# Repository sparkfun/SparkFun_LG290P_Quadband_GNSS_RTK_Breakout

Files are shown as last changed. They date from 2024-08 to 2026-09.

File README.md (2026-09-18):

SparkFun Quadband GNSS RTK Breakout - LG290P (Qwiic)
========================================

SparkFun Quadband GNSS RTK Breakout - LG290P (Qwiic) (https://www.sparkfun.com/sparkfun-quadband-gnss-rtk-breakout-lg290p-qwiic.html)

[*SparkFun Quadband GNSS RTK Breakout - LG290P (Qwiic) (GPS-26620)*](https://www.sparkfun.com/sparkfun-quadband-gnss-rtk-breakout-lg290p-qwiic.html)

The [SparkFun Quadband GNSS RTK Breakout - LG290P (Qwiic)](https://www.sparkfun.com/sparkfun-quadband-gnss-rtk-breakout-lg290p-qwiic.html) features the Quectel LG290P GNSS module. The board's dimensions, pin layout, and connectors are exactly the same as our very popular [SparkFun GPS-RTK-SMA Breakout - ZED-F9P (Qwiic)](https://www.sparkfun.com/sparkfun-gps-rtk-sma-breakout-zed-f9p-qwiic.html); and can be used as a drop-in replacement. The board also accommodates users with a diverse choice of interfaces including UART, SPI*, and I2C*.

The LG290P module is a quad-band, multi-constellation, high-precision, RTK GNSS receiver. The module is capable of simultaneously receiving signals from the `L1`, `L2`, `L5`, and `L6`/`E6` frequency bands of the GPS, GLONASS, Galileo, BDS, QZSS, and NavIC GNSS constellations. In addition, the module supports SBAS augmentation systems (WASS, EGNOS, BDSBAS, MSAS, GAGAN, and SDCM), PPP services* (BDS PPP-B2b, QZSS CLAS, MADOCA-PPP, and Galileo HAS), and RTK corrections for precision navigation with a fast convergence time and reliable performance.

The built-in NIC anti-jamming unit provides professional-grade interference signal detection and elimination algorithms, which effectively mitigate against multiple narrow-band interference sources and significantly improves the signal reception performance in complex electromagnetic environments. Additionally, the embedded algorithms ensure reliable positioning in complex scenarios such as urban environments and deep tree cover.

With its performance advantages of high-precision and low power consumption, this board is an ideal choice for high-precision navigation applications, such as intelligent robots, UAVs, precision agriculture, mining, surveying, and autonomous navigation.

> [!NOTE]
> `*`: Feature is still under development

> [!IMPORTANT]
> - Currently, only the UART interface is supported by the module. All three UART ports are broken out to the USB-C connector *(via CH342 USB-serial converter)*, 4-pin locking JST connector, and BlueSMiRF 6-pin header.
> - Additionally, the corrections for some of the PPP services may not be implemented yet.

Documentation
--------------

* **[Hookup Guide (mkdocs)](http://docs.sparkfun.com/SparkFun_LG290P_Quadband_GNSS_RTK_Breakout/)** - The hookup guide for the SparkFun Quadband GNSS RTK Breakout - LG290P (Qwiic) hosted by GitHub pages.<br>
   
* [SparkFun LG290P GNSS Arduino Library](https://github.com/sparkfun/SparkFun_LG290P_GNSS_Arduino_Library) - An Arduino library for the LG290P GNSS module

*Need to download or print our hookup guide?*

* [Print *(Print to PDF)* from Single-Page View](http://docs.sparkfun.com/SparkFun_LG290P_Quadband_GNSS_RTK_Breakout/print_view)

Repository Contents
-------------------

* **[/docs](/docs/)** - Online documentation files
    * [assets](/docs/assets/) - Assets files
        * [3d_model](/docs/assets/3d_model/) - Files for the 3D models
            * [3D CAD Model](/docs/assets/3d_model/cad_model.step) (.step)
        * [board_files](/docs/assets/board_files/) - Files for the product design
            * [KiCad Design Files](/docs/assets/board_files/kicad_files.zip) (.zip)
            * [Schematic](/docs/assets/board_files/schematic.pdf) (.pdf)
            * [Dimensions](/docs/assets/board_files/dimensions.pdf) (.pdf)
        * [component_documentation](/docs/assets/component_documentation/) - Datasheets for hardware components
        * [img/hookup_guide/](/docs/assets/img/hookup_guide/) - Images for hookup guide documentation
* **[/Hardware](/Hardware/)** - Hardware design files (.brd, .sch)
  * **[/Production](/Production/)** - Production files

Product Variants
----------------

- LG290P Variants
  - [GPS-26620](https://www.sparkfun.com/sparkfun-quadband-gnss-rtk-breakout-lg290p-qwiic.html) - v1.0, Initial Release
  - [GPS-26916](https://www.sparkfun.com/sparkfun-rtk-postcard.html) - SparkFun RTK Postcard *(w/ ESP32)*
- [GPS-28019](https://www.sparkfun.com/products/28019) - SparkFun Quadband GNSS RTK Breakout - LG580P (Qwiic)

Version History
---------------

* [v10](https://github.com/sparkfun/SparkFun_LG290P_Quadband_GNSS_RTK_Breakout/releases/tag/v10) - Initial Release

License Information
-------------------

This product is ***open source***!

Please review the [`LICENSE.md`](./LICENSE.md) file for license information.

If you have any questions or concerns about licensing, please contact technical support on our [SparkFun forums](https://community.sparkfun.com/).

Distributed as-is; no warranty is given.

- Your friends at SparkFun.

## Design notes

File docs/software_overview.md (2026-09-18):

---
icon: fontawesome/solid/computer
---

## CH342 USB Driver
The USB drivers for the CH342 USB-to-Serial converter can be downloaded from the [manufacturer's website](https://www.wch-ic.com/search?q=CH342&t=downloads).

<div class="grid cards" align="center" markdown>

-   :material-microsoft-windows: **Windows**

	---

	[:octicons-download-16:{ .heart } Download Page for `CH343SER.EXE`](https://www.wch-ic.com/downloads/CH343SER_EXE.html){ .md-button .md-button--primary target="blank" }

-   :material-apple: **MacOS**

	---

	[:octicons-download-16:{ .heart } Download Page for `CH341SER_MAC.ZIP`](https://www.wch-ic.com/downloads/CH34XSER_MAC_ZIP.html){ .md-button .md-button--primary target="blank" }

</div>

!!! info "Linux"
	A USB driver is not required for Linux based operating systems.

## GNSS Software
!!! tip
	While it is not required, we highly recommend that users configure their LG290P GNSS module with the [QGNSS software provided by Quectel](#qgnss-software). This is due to the unique data structure of the UART command messages, utilized to configure the LG290P module.

	??? warning "Windows Only"
		Currently, the QGNSS software is only available for Windows operating systems.

	??? success "Windows, MacOS, or Linux"
		For users with computers that run on MacOS or Linux, we have found alternative software option for viewing the data from the NMEA messages. However, this GUI interface is currently limited to only receiving UART messages and cannot send messages to configure the LG290P module.

		- :material-github: [GitHub Repository](https://github.com/semuconsulting/PyGPSClient)
		- [Installation Instructions](https://github.com/semuconsulting/PyGPSClient?tab=readme-ov-file#installation)
		- [PyPI Project](https://pypi.org/project/pygpsclient/)

### QGNSS Software
!!! warning "Windows Only"
	Currently, the QGNSS software is only available for Windows operating systems.

QGNSS is highly intuitive GNSS evaluation software that is easy to use, personalized, and compatible with leading Quectel technologies. The software allows users to define or apply GNSS product configurations for specific use cases. Saving, restoring, or sharing configurations between different products and users is easy. The software supports product evaluation with a choice of views to observe static and dynamic behavior of the connected a Quectel GNSS receiver.

<article style="text-align: center;" markdown>
[:octicons-download-16:{ .heart } Download the QGNSS Software *(v2.x)* from Quectel](https://www.quectel.com/download/qgnss_v2-0_en/){ .md-button .md-button--primary target="blank" }
</article>

!!! info "System Requirements"
	**Operating System:** Windows

#### Connecting to the LG290P
In order to connect to the LG290P properly, users will need to specify the settings of the `UART1` port.

<figure markdown>
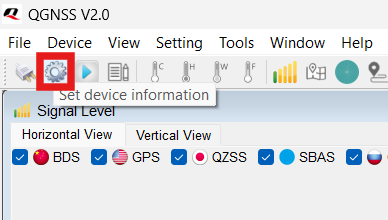
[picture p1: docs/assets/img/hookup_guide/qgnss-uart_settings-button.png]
Configure UART Settings

<figcaption markdown>Click the <kbd>:material-cog:</kbd> button to configure the UART settings.</figcaption>
</figure>

Before users can connect to the Quad-band GNSS RTK breakout board, they will need to specify the connection settings in QGNSS. Once configured, users can select the ++"OK"++ button and QGNSS will automatically attempt to connect to the GNSS module.

- Select the `LG290P(03)` from the drop-down menu to configure the `Model` of the GNSS module being connected.
- Below, is a list of the default settings for `UART` ports of the LG290P. These settings should be selected in the `Device Information` menu, unless configured differently.
- For the `Port`, select the port with the lowest enumeration of the CH342 or the port labeled with channel `A` from the drop-down menu.

<div class="grid" markdown>

<div markdown>

<figure markdown>
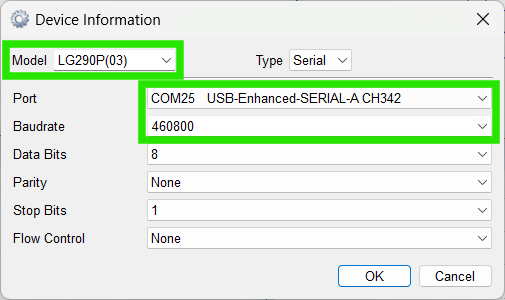
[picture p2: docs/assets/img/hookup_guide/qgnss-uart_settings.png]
UART Settings in QGNSS

<figcaption markdown>Specify the settings for the UART port in QGNSS.</figcaption>
</figure>

</div>

<div markdown>

!!! info "LG290P - Default Settings"
	The UART ports of the LG290P GNSS module will have the following default configuration:

	- Baudrate: 460800bps
	- Data Bits: 8
	- Parity: No
	- Stop Bits: 1
	- Flow Control: None

</div>

<div markdown>

<figure markdown>
COM Ports
<figcaption markdown>Available `COM`ports for the CH342. Select the lowest enumeration or the port labeled `A`.</figcaption>
</figure>

</div>

</div>

#### Configure the LG290P
By default, the UART ports are configured to transmit and receive `NMEA 0183` and/or `RTCM 3.x` messages. These messages are generally used for transmitting PNT data; and providing or receiving RTK corrections, respectively. Quectel also implements a system of proprietary messages (`PQTM`) for users to configure the LG290P, following the data format of the `NMEA` protocol.

???+ terminal "Data Format - PQTM Messages"
	The expected structure of the data in the proprietary PQTM messages is shown below:

	<figure markdown>
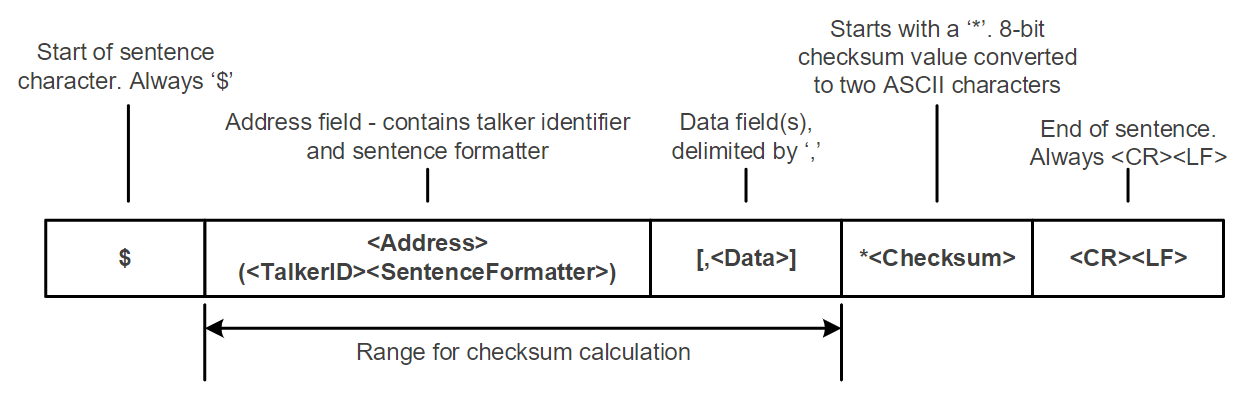
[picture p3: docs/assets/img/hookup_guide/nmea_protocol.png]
NMEA data structure
	
	<figcaption markdown>The data structure of Quectel messages for the `NMEA` protocol.</figcaption>
	</figure>

	`<Checksum>`:

	- Checksum field follows the checksum delimiter character `*`.
	- Checksum is the 8-bit exclusive OR of all characters in the sentence, including `,` the field delimiter, between but not including the `$` and the `*` delimiters.

	`<CR>` & `<LF>`: Carriage return; followed by a new line

	- Depending on the terminal emulator, these may be options configured in the program settings.
	- Otherwise, users may need to add the `\r` and `\n` characters at the end of the message.

In the QGNSS software, users can click on the ++"Advance"++ button, at the bottom of the `QConsole` window, to configure the settings for the messages sent to the LG290P. Selecting `NMEA` and `CRLF` from the drop-down menu of the **Checksum Type** and **Suffix** options, will automatically calculate and append the `<checksum>` value, carriage return, and line follow to the end of the message entered in the **Data Input** field.

<figure markdown>
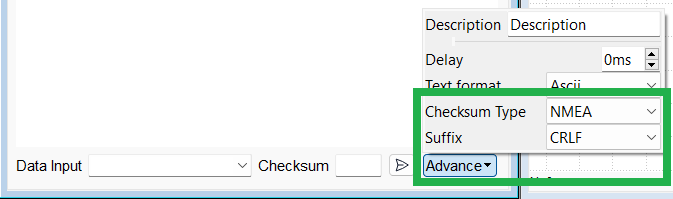
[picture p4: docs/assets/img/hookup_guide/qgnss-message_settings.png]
NMEA message setting

<figcaption markdown>The settings for the messages transmitted from the QConsole.</figcaption>
</figure>

???+ tip "Display the QConsole Toolbar"
	There is a toolbar for the QConsole, which has a bunch of tools that users may find useful. This includes, a search function, scroll-lock button, pause/clear the message feed, etc. To open/close the toolbar inside the QConsole, ++"right-click"++ on the mouse and select the `Show Tool` option from the drop-down menu or utilize the keyboard shortcut: ++ctrl++ + ++q++.

	<figure markdown>
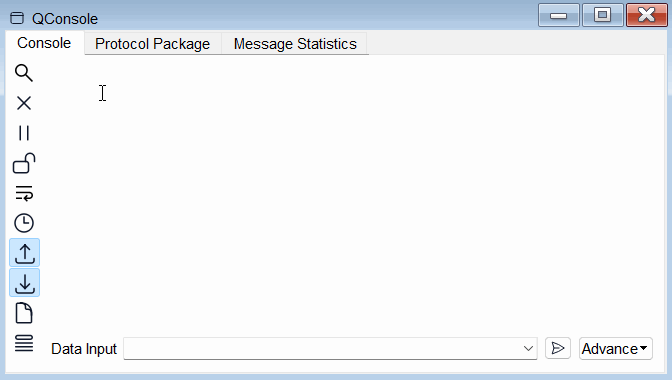
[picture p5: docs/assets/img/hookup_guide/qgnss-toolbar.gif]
QConsole Toolbar
	
	<figcaption markdown>++"Right-click"++ on the mouse and select the `Show Tool` option, inside the QConsole.</figcaption>
	</figure>

??? example "Example - `PQTMCFGUART` Message"
	As an example, try utilizing the `PQTMCFGUART` PQTM message. Enter `$PQTMCFGUART,R*` into the **Data Input*** field of the QConsole. DOn't forget to select the `NMEA` and `CRLF` options from ++"Advance"++ settings menu. If entered and configured properly, the value `36` should pop up in the **Checksum** field of the QConsole; then, click on the <kbd>:material-send:</kbd> button to send the message.

	``` bash
	$PQTMCFGUART,R*
	```

	Once the message has been sent, keep a close watch of the messages in the console. It may help to click on the <kbd>:octicons-unlock-16:</kbd> button to disable auto-scrolling, when trying to locate the message response. Additionally, the response may not appear right away, it could be appended to the end of the next data packet, as shown in the image below.

	<figure markdown>
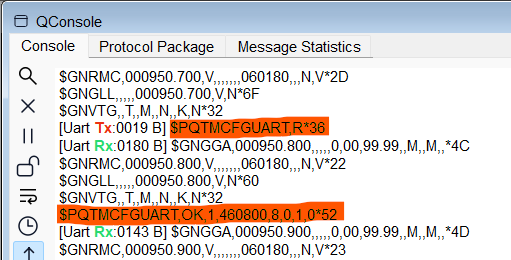
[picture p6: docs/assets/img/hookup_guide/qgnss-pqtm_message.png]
PQTM demo
	
	<figcaption markdown>Example of utilizing the Quectel PQTM messages in the QConsole.</figcaption>
	</figure>

#### Firmware Update
In the event that users need to update the firmware on the LG290P module, please refer to the instructions in Quectel's [reference manual](./assets/component_documentation/quectel_lg290p03lgx80p03_firmware_upgrade_guide_v1-1.pdf). For the latest firmware, users should reach out to Quectel through their [forum page](https://forums.quectel.com/); otherwise, we have some of the firmware releases available in one of our [GitHub repositories](https://github.com/sparkfun/SparkFun_RTK_Postcard/tree/main/Firmware).

<article style="text-align: center;" markdown>

[Archived Firmware Releases](https://github.com/sparkfun/SparkFun_RTK_Postcard/tree/main/Firmware){ .md-button .md-button--primary target="blank" } [Firmware Upgrade Manual](./assets/component_documentation/quectel_lg290p03lgx80p03_firmware_upgrade_guide_v1-1.pdf){ .md-button .md-button--primary target="blank" }

</article>

!!! warning "Synchronization Step"
	In the [reference manual](./assets/component_documentation/quectel_lg290p03lgx80p03_firmware_upgrade_guide_v1-1.pdf), **Step 9** instructs users to wait for a synchronization process. If users refer to an earlier section of the manual, this process requires the LG290P module to receive a `SYNC_WORD1` within 500ms of powering up. Therefore, users must restart the module during the synchronization step. In the QGNSS software *(+v2.1)*, this can be performed with the :material-refresh: reboot button.

	<figure markdown>
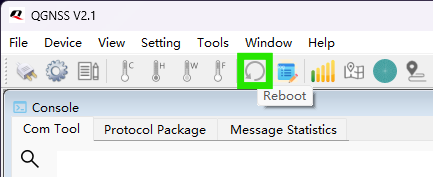
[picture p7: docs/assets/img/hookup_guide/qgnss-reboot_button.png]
Reboot button
	
	<figcaption markdown>Reboot button in the QGNSS software *(v2.1)*.</figcaption>
	</figure>

!!! example "Example - Step-by-Step Instructions"

	1. [Connect to the LG290P](#connecting-to-the-lg290p)
	1. From the **Tools** drop down menu, select **Firmware Update**

	**Tools** > **Firmware Update**

	1. Click the :material-file-send: button to select the receiver firmware
	1. Click `Settings` to select the baudrate
	1. Click to start the firmware upgrade process and wait for the process to complete
	1. Reset module

	1. Click to choose the firmware upgrade package whose name is identifiable by the presence of “pkg” before the extension name
	1. Click to start the firmware upgrade process and wait for synchronization between the module and the PC
	1. Manually reset the module within 90 s; otherwise, the firmware upgrade will fail. In this case, you can retry the previous step

		??? tip "Previous Versions"
			For previous versions of the QGNSS software, prior to initializing the firmware upgrade process, users can send the `PQTMSRR` [PQTM message](#configure-the-lg290p) to perform a system reset and reboot the GNSS receiver. We recommend having everything pre-configured to upgrade the firmware as the module usually initializes within 5s of sending the `PQTMSRR` message.

	1. Wait for upgrading to complete
	1. Firmware upgrade is successful. After the upgrade is complete, the module will automatically restart

### PyGPSClient
As an alternative to QGNSS, for users with computers that run on MacOS or Linux (_including Raspberry Pi_), we recommend [PyGPSClient](https://github.com/semuconsulting/PyGPSClient) as an option for configuring the LG290P (_via proprietary NMEA sentences_), viewing standard and proprietary NMEA data from the receiver and connecting to an NTRIP caster.

??? info "Resources"
	For additional information, users can refer to the following resources for the PyGPSClient software:

	- :material-github: [GitHub Repository](https://github.com/semuconsulting/PyGPSClient)
	- [Installation Instructions](https://github.com/semuconsulting/PyGPSClient?tab=readme-ov-file#installation)
	- [LG290P Configuration](https://github.com/semuconsulting/PyGPSClient?tab=readme-ov-file#nmeaconfig)
	- [PyPI Project](https://pypi.org/project/pygpsclient/)

#### Installation
There are a variety of [installation methods](https://github.com/semuconsulting/PyGPSClient?tab=readme-ov-file#installation) detailed in the GitHub repository's `README.md` file. However, we recommend utilizing the `pip` installation method.

!!! terminal "Installation Commands"
	Depending on how Python is installed on the computer, one of the following commands should allow users to install the software.

	-
		``` bash
		python3 -m pip install --upgrade pygpsclient
		```
	-
		``` bash
		pip install --upgrade pygpsclient
		```

	!!! info "System Requirements"
		This installation method requires an internet connection. Additionally, users may need administrative privileges *(or root access `sudo`)* for some installations.

#### Connecting to the LG290P
Before users can connect to the Quad-band GNSS RTK breakout board, they will need to specify the settings of the UART port in PyGPSClient. Once configured, users can select the <kbd>:material-usb:</kbd> button and PyGPSClient will automatically attempt to connect to the GNSS module. If the UART port does not appear in the Serial Port list in the PyGPSClient UI, it can be added as a user-defined port e.g. `/dev/ttyAMA0`.

- Below, is a list of the default settings for `UART` ports of the LG290P. These settings should be selected in the configuration menu.
- For the `Serial Port`, select the port with the lowest enumeration of the CH342 or the port labeled with channel `A` from the drop-down menu.

<div class="grid" markdown>

<div markdown>

<figure markdown>
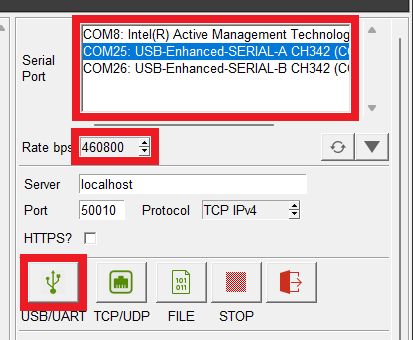
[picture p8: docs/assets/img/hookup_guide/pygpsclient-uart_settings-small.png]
UART Settings in PyGPSClient

<figcaption markdown>Specify the settings for the UART port in QGNSS.</figcaption>
</figure>

</div>

<div markdown>

!!! info "LG290P - Default Settings"
	The UART ports of the LG290P GNSS module will have the following default configuration:

	- Baudrate: 460800bps
	- Data Bits: 8
	- Parity: No
	- Stop Bits: 1
	- Flow Control: None

</div>

</div>

### Terminal Emulator
Another viable option for connecting to the Quad-band GNSS RTK breakout board, is to utilize a [terminal emulation program](https://learn.sparkfun.com/tutorials/112). While reading the data sent from the LG290P is relatively trivial, users will need to be more selective when choosing an emulator to configure the LG290P module on the Quad-band GNSS RTK breakout board. This is due to the unique data structure of the proprietary messages that Quectel implements to configure the LG290P *(see the [**Configure the LG290P**](#configure-the-lg290p) section, above)*.

## Arduino IDE
!!! tip
	For first-time users, who have never programmed before and are looking to use the Arduino IDE, we recommend beginning with the <a href="https://www.sparkfun.com/sparkfun-inventor-s-kit-for-arduino-uno-v4-1.html">SparkFun Inventor's Kit (SIK)</a>, which is designed to help users get started programming with the Arduino IDE.

Most users may already be familiar with the Arduino IDE and its use. However, for those of you who have never heard the name *Arduino* before, feel free to check out the [Arduino website](https://www.arduino.cc/en/Guide/HomePage). To get started with using the Arduino IDE, check out our tutorials below:

<div class="grid cards" markdown align="center">

-   <a href="https://learn.sparkfun.com/tutorials/50"><figure markdown>
	What is an Arduino?
	</figure>

	---

	**What is an Arduino?**</a>

-   <a href="https://learn.sparkfun.com/tutorials/61"><figure markdown>
	Installing the Arduino IDE
	</figure>

	---
	
	**Installing the Arduino IDE**</a>

-   <a href="https://learn.sparkfun.com/tutorials/15"><figure markdown>
	Installing an Arduino Library
	</figure>

	---
	
	**Installing an Arduino Library**</a>

-   <a href="https://learn.sparkfun.com/tutorials/1265"><figure markdown>
	Installing Board Definitions in the Arduino IDE
	</figure>

	---
	
	**Installing Board Definitions in the Arduino IDE**</a>
</div>

### SparkFun LG290P Quadband RTK GNSS Arduino Library
The [SparkFun LG290P Quadband RTK GNSS Arduino Library](https://github.com/sparkfun/SparkFun_LG290P_GNSS_Arduino_Library) can be installed from the library manager in the Arduino IDE by searching for:

	SparkFun LG290P Quadband RTK GNSS Arduino Library

<div class="grid" markdown>

<div markdown>

<figure markdown>
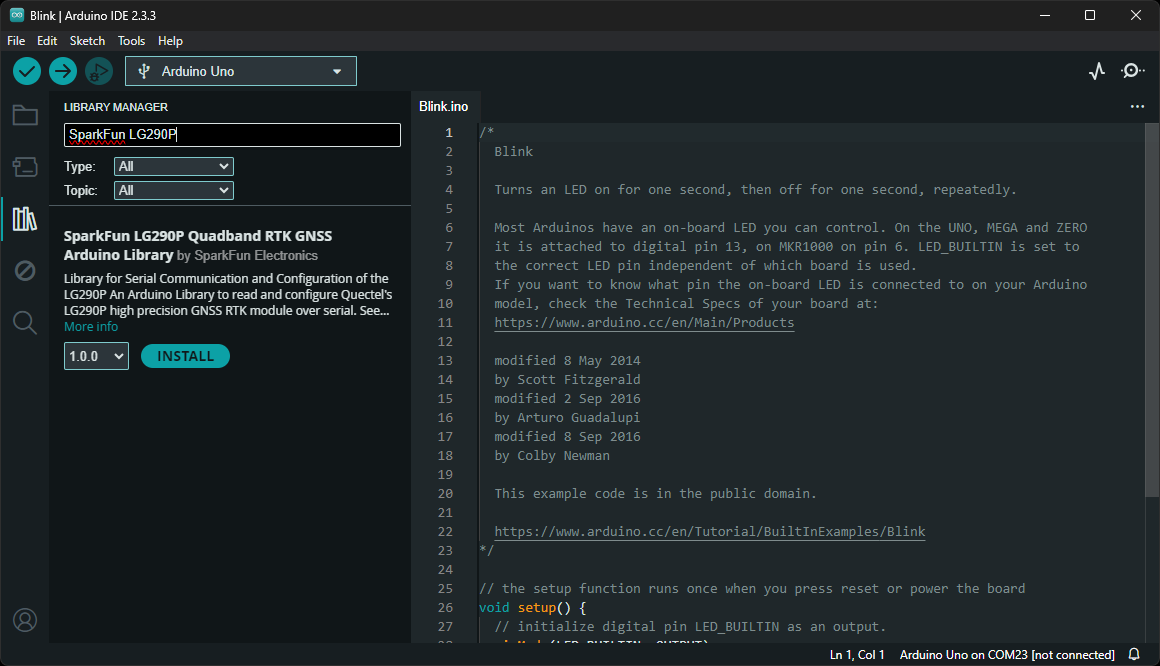
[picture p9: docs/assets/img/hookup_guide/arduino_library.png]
Click to enlarge

<figcaption markdown>SparkFun LG290P Quadband RTK GNSS Arduino Library in the library manager of the Arduino IDE.</figcaption>
</figure>

</div>

<div markdown>

!!! tip "Manually Download the Arduino Library"
	For users who would like to manually download and install the library, the `*.zip` file can be accessed from the [GitHub repository](https://github.com/sparkfun/SparkFun_LG290P_GNSS_Arduino_Library) or downloaded by clicking the button below.

	<article style="text-align: center;" markdown>
	[:octicons-download-16:{ .heart } Download the Arduino Library](https://github.com/sparkfun/SparkFun_LG290P_GNSS_Arduino_Library/archive/refs/heads/main.zip){ .md-button .md-button--primary }
	</article>

</div>

</div>

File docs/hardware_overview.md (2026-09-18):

---
icon: material/cog
---

## :material-folder-cog: Design Files
The SparkFun LG290P Quadband GNSS RTK breakout board's dimensions, pin layout, and connectors are exactly the same as our very popular [SparkFun GPS-RTK-SMA Breakout - ZED-F9P (Qwiic)](https://www.sparkfun.com/sparkfun-gps-rtk-sma-breakout-zed-f9p-qwiic.html); and can be used as a drop-in replacement. The board features three UART ports, which are accessible through the USB-C connector, BlueSMiRF *(6-pin PTH)* header , and 4-pin locking JST connector. Users can also interface with the board through the 24 PTH pins that are broken out around the edge of the board. For the GNSS antenna, an SMA antenna connector is provided on the edge of the board; additionally, there are also SMD pads for another <i>(RP-)</i>SMA connector to output a PPS signal. We also provide two 4-pin JST Qwiic connectors for future use, when the I<sup>2</sup>C feature becomes available for the GNSS module.

<!-- Import the component -->
<script type="module" src="https://ajax.googleapis.com/ajax/libs/model-viewer/3.5.0/model-viewer.min.js"></script>

<div class="grid cards desc" markdown>

-   :kicad-logo:{ .enlarge-logo } Design Files

	---

	- :fontawesome-solid-file-pdf: [Schematic](./assets/board_files/schematic.pdf)
	- :material-folder-zip: [KiCad Files](./assets/board_files/kicad_files.zip)
	- :material-cube-outline: [STEP File](./assets/3d_model/cad_model.step)
	<!-- - :material-rotate-3d: [STEP File](./assets/3d_model/cad_model.step) -->
	- :fontawesome-solid-file-pdf: [Board Dimensions](./assets/board_files/dimensions.pdf):
		- 1.70" x 1.70" (43.2mm x 43.2mm)
		- Four mounting holes:
			- 4-40 screw compatible

-   <!-- Boxes in tabs -->

	=== "3D Model"
		<article style="text-align: center;" markdown>
		<model-viewer src="../assets/3d_model/web_model.glb" camera-controls poster="../assets/3d_model/poster.png" tone-mapping="neutral" shadow-intensity="1.49" exposure="0.75" shadow-softness="0.58" camera-target="-0.001m 0m 0m" camera-orbit="0deg 70deg 0.1259m" field-of-view="25.11deg" environment-image="legacy" style="width: 100%; height: 450px;">
		</model-viewer>
		</article>

	=== "Dimensions"
		<article style="text-align: center;" markdown>
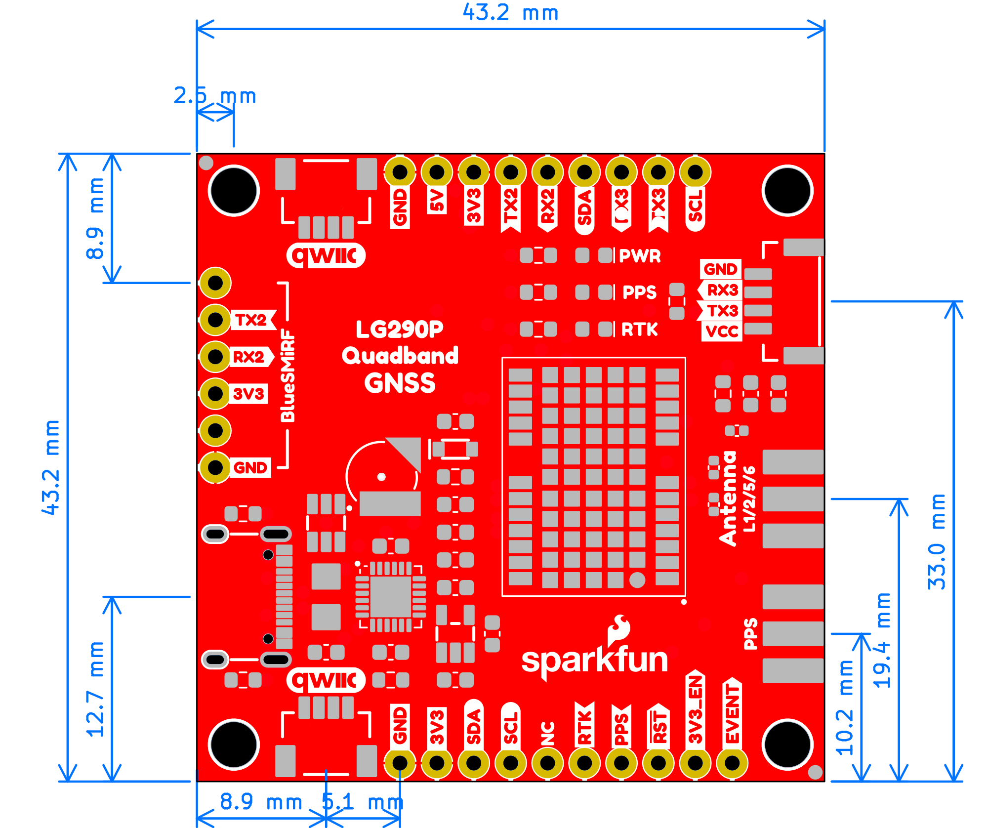
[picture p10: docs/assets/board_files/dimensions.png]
Board Dimensions
		
		<figcaption markdown>Dimensions of the Quad-band GNSS RTK breakout board.</figcaption>
		</article>

		??? tip "Need more measurements?"
			For more information about the board's dimensions, users can download the [KiCad files](./assets/board_files/kicad_files.zip) for this board. These files can be opened in KiCad and additional measurements can be made with the measuring tool.

			!!! info ":octicons-download-16:{ .heart } KiCad - Free Download!"
				KiCad is free, open-source [CAD]("computer-aided design") program for electronics. Click on the button below to download their software. *(\*Users can find out more information about KiCad from their [website](https://www.kicad.org/).)*

				<article style="text-align: center;" markdown>
				[Download :kicad-logo:{ .enlarge-logo }](https://www.kicad.org/download/ "Go to downloads page"){ .md-button .md-button--primary width="250px" }
				</article>

			??? info ":straight_ruler: Measuring Tool"
				This video demonstrates how to utilize the dimensions tool in KiCad, to include additional measurements:

				<article class="video-500px" style="text-align: center; margin: auto;" markdown>
				<iframe src="https://www.youtube.com/embed/-eXuD8pkCYw" title="KiCad Dimension Tool" frameborder="0" allow="accelerometer; autoplay; clipboard-write; encrypted-media; gyroscope; picture-in-picture" allowfullscreen></iframe>
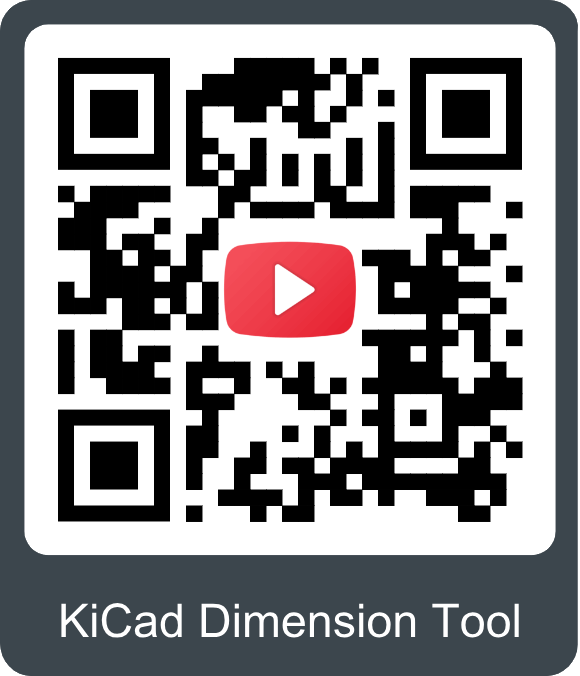
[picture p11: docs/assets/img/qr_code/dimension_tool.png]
QR code to play video
				
				</article>

</div>

## USB-C Connector
The USB connector is provided to power and communicate with the LG290P GNSS receiver. For most users, it will be the primary method for interfacing with the LG290P.

<figure markdown>
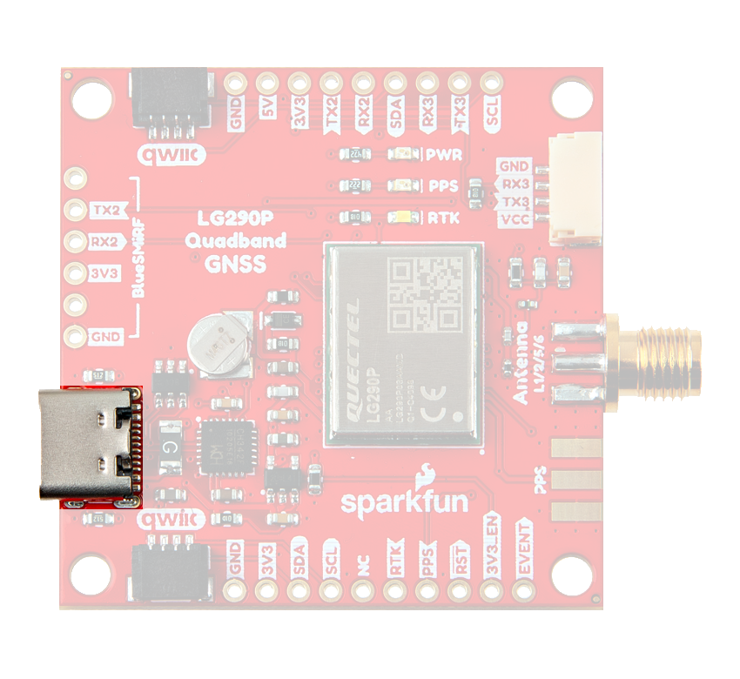
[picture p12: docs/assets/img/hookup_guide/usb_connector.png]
USB-C Connector

<figcaption markdown>USB-C connector on the Quad-band GNSS RTK breakout board.</figcaption>
</figure>

### CH342 Dual UART Converter
The CH342 serial-to-USB converter allows users to interface with the `UART1` port of the LG290P GNSS module through the USB-C connector. Although the CH342 provides a dual-channel UART interface, only a single channel is utilized to communicate with the LG290P GNSS module. To utilize the CH342, users may need to install a USB driver, which can be downloaded from the [manufacturer website](https://www.wch-ic.com/search?q=CH342&t=downloads).

Once the USB driver is installed:

- Two virtual `COM` ports will be emulated, which can be used as standard `COM` ports to access the receiver.
- Users should select `COM` port with the lower enumeration or the one labeled as `Channel A`.

??? tip "Tip - USB Drivers"
	<div class="grid cards" align="center" markdown>

	-   :material-microsoft-windows: **Windows**

		---

		[:octicons-download-16:{ .heart } Download Page for `CH343SER.EXE`](https://www.wch-ic.com/downloads/CH343SER_EXE.html){ .md-button .md-button--primary target="blank" }

	-   :material-apple: **MacOS**

		---

		[:octicons-download-16:{ .heart } Download Page for `CH341SER_MAC.ZIP`](https://www.wch-ic.com/downloads/CH34XSER_MAC_ZIP.html){ .md-button .md-button--primary target="blank" }

	</div>

	!!! info "Linux"
		A USB driver is not required for Linux based operating systems.

## Power
The Quad-band GNSS RTK breakout board only requires **3.3V** to power the board's primary components. The simplest method to power the board is through the USB-C connector. Alternatively, the board can also be powered through the other connectors and [PTH](https://en.wikipedia.org/wiki/Through-hole_technology "Plated Through Holes") pins.

<figure markdown>
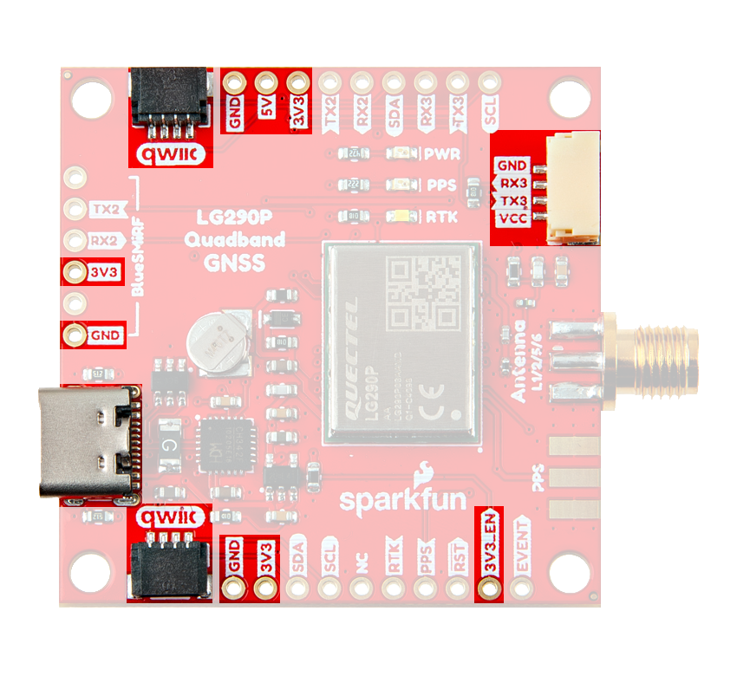
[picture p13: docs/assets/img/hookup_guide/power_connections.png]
Power connections

<figcaption markdown>Quad-band GNSS RTK breakout board's power connections.</figcaption>
</figure>

Below, is a general summary of the power circuitry for the board:

<div class="annotate" markdown>

- **`5V`** - The voltage from the USB-C connector, usually **5V**.
	- Can be utilized as the primary power source for the entire board.
- **`3V3`** - 3.3V power rail, which powers the LG290P GNSS module, backup battery, and the power LED.
	- Power can also be distributed to/from any of the `3V3` PTH pins or JST connectors *(Qwiic or `UART3`)*.
		- For power that is supplied through these connections, the LG290P requires a supply voltage of **3.15–3.45V**.
	- A regulated **3.3V** is supplied by the [RT9080](./assets/component_documentation/DS9080.pdf), when powered from the `5V` PTH pin or USB connector
		- Input Voltage Range: **3.0 to 5.5V**
		- The RT9080 LDO regulator can source up to 600mA.
- **`3V3_EN`** - Controls the power output form the RT9080 voltage regulator.
	- By default, the pin is pulled-up to 5V and to enable the RT9080 output voltage.
- **`GND`** - The common ground or the 0V reference for the voltage supplies.

</div>

!!! info
	For more details, users can reference the [schematic](./assets/board_files/schematic.pdf) and the datasheets of the individual components on the board.

<div class="grid cards" markdown>

-   ### Power Consumption

	The power consumption of the LG290P GNSS module depends on the GNSS signals enabled and the positioning mode.

	**Current Consumption:**

	- Acquisition: 91mA (300.3mW)
	- Tracking: 91mA (300.3mW)
	- Backup Mode: 12μA (39.6mW)

-   ### Backup Battery

	While charged, the backup battery allows the GNSS module to hot/warm start with valid ephemeris data (time and GNSS orbital trajectories) that was stored.

	**Time to First Fix:**

	- Cold Start: 28s
	- Warm Start: 28s
	- Hot Start: 1.7s

</div>

## :fontawesome-solid-microchip:&nbsp; LG290P GNSS
The centerpiece of the Quad-band GNSS RTK breakout board, is the [LG290P GNSS module](./assets/component_documentation/quectel_lg290p03_hardware_design_v1-1.pdf) from [Quectel](https://www.quectel.com/). The LG290P is a low-power, multi-band, multi-constellation GNSS receiver capable of delivering centimeter-level precision at high update rates. The built-in NIC anti-jamming unit provides professional-grade interference signal detection and elimination algorithms, which effectively mitigate against multiple narrow-band interference sources and significantly improves the signal reception performance in complex electromagnetic environments. With its performance advantages of high-precision and power consumption, this board is an ideal choice for high-precision navigation applications, such as intelligent robots, UAVs, precision agriculture, mining, surveying, and autonomous navigation.

<div class="grid" markdown>

<div markdown>

<figure markdown>
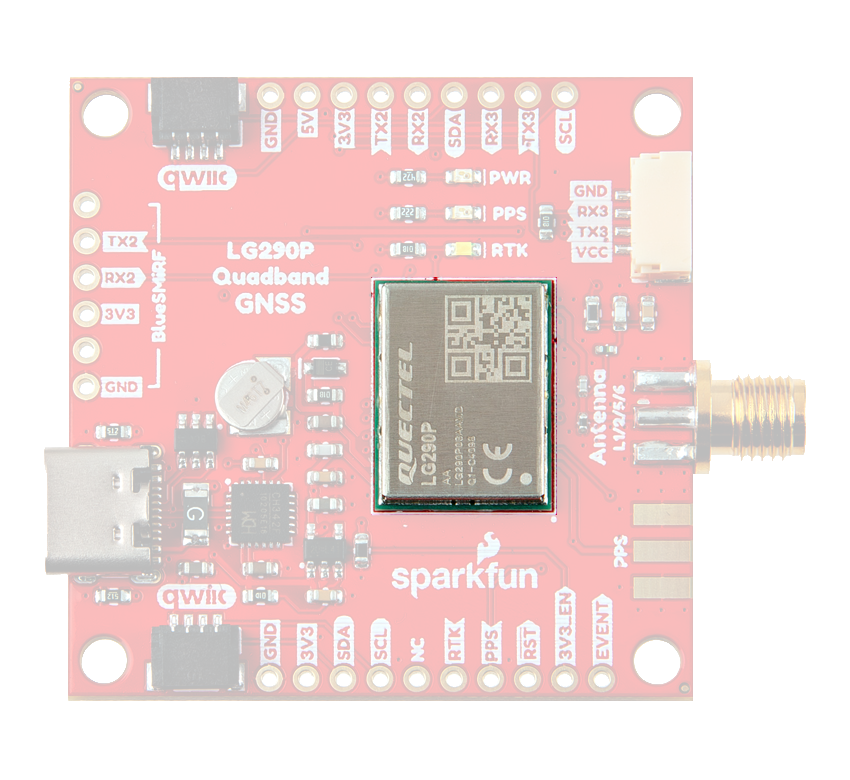
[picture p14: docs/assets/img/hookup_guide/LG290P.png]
LG290P GNSS module

<figcaption markdown>The LG290P module on the Quad-band GNSS RTK breakout board.</figcaption>
</figure>

</div>

<div markdown>

<article class="video-500px" style="text-align: center; margin: auto;" markdown>
<iframe src="https://player.vimeo.com/video/1000742664?dnt=1&amp;app_id=122963" title="Quectel: Product Intro for LG290P GNSS Module" frameborder="0" allow="accelerometer; autoplay; clipboard-write; encrypted-media; gyroscope; picture-in-picture" allowfullscreen></iframe>
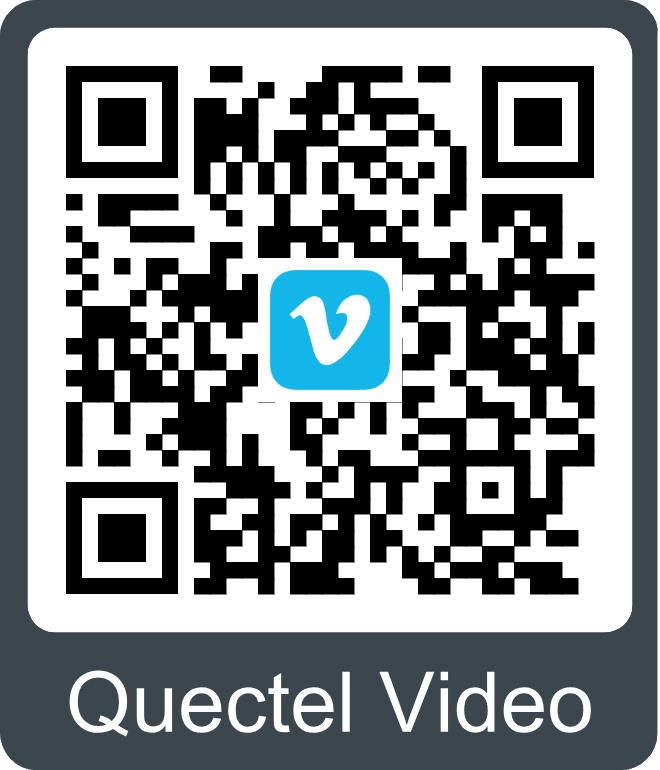
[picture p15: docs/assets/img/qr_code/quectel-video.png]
QR code to product video

</article>

</div>

</div>

??? info "General Features"
	<div class="grid" markdown>

	<div markdown>

	- Supply Voltage: **3.15–3.45V**
	- Tracking Channels: 1040
	- Concurrent signal reception: 5 + QZSS
		- `L1`, `L2`, `L5`, `E6` frequency bands
	- Sensitivity:
		- Acquisition: -146dBm
		- Tracking: -160dBm
		- Reacquisition: -155dBm
	- Antenna Power: External or Internal
	- GNSS Constellations and SBAS Systems:
		- **USA:** GPS + WASS
		- **Russia:** GLONASS + SDCM
		- **EU:** Galileo + EGNOS
		- **China:** BDS + BDSDAS
		- **Japan:** QZSS + MSAS
		- **India:** NavIC + GAGAN
	- Accuracy of 1PPS Signal: 5ns *(RMS)*
	- Update Rate:
		- Default: 10Hz
		- Max: 20Hz

	</div>

	<div markdown>

	- Time to First Fix *(without AGNSS)*:
		- Cold Start: 28s
		- Warm Start: 28s
		- Hot Start: 1.7s
	- RTK Convergence Time: 5s
	- Dynamic Performance:
		- Maximum Altitude: 10000m
		- Maximum Velocity: 490m/s
		- Maximum Acceleration: 4g
	- Built-in NIC anti-jamming unit
	- Interfaces
		- UART (x3)
			- Baud Rate: 9600–3000000bps
				- **Default:** 460800bps
			- Protocol: `NMEA 0183`/`RTCM 3.x`
		- SPI[^1] (x1)
		- I^2^C[^1] (x1)
	- Operating temperature: -40&deg;C to +85&deg;C
	- Footprint: 12.2mm × 16mm × 2.6mm
	- Weight: ~0.9g

	</div>

	</div>

	[^1]:
		!!! warning "Feature Under Development"
			Currently, only the UART interface is supported by the module. Support for the **I^2^C** and **SPI** interfaces are still under development.

??? info "Supported Frequency Bands"
	The LG290P modules are multi-band, multi-constellation GNSS receivers. Below, is a chart illustrating the frequency bands utilized by all the global navigation satellite systems; along with a list of the frequency bands and GNSS systems supported by the LG290P GNSS module.

	<figure markdown>
	GNSS frequency bands (https://www.tallysman.com/app/uploads/2021/07/Tallysman-GNSS-Frequencies-v8.0_Chart-1-1024x425.png "Click to enlarge")
	<figcaption markdown>Frequency bands of the global navigation satellite systems. (Source: [Tallysman](https://www.tallysman.com/gnss-constellations-radio-frequencies-and-signals/))</figcaption>
	</figure>

	<div class="grid" markdown>

	<div markdown>

	**Supported Frequency Bands:**

	- GPS: `L1 C/A`, `L1C`[^2], `L5`, `L2C`
	- GLONASS: `L1`, `L2`
	- Galileo: `E1`, `E5a`, `E5b`, `E6`
	- BDS: `B1I`, `B1C`, `B2a`, `B2b`, `B2I`, `B3I`
	- QZSS: `L1 C/A`, `L1C`[^2], `L5`, `L2C`
	- NavIC: `L5`
	- SBAS: `L1 C/A`
	- L-band PPP[^3]:
		- PPP: `B2b`
		- QZSS: `L6`
		- Galileo HAS: `E6`

	</div>

	<div markdown>

	**Supported GNSS Constellations:**

	- GPS (USA)
	- GLONASS (Russia)
	- Galileo (EU)
	- BDS (China)
	- QZSS (Japan)
	- NavIC (India)

	**Supported SBAS Systems:**

	- WASS (USA)
	- SDCM (Russia)
	- EGNOS (EU)
	- BDSBAS (China)
	- MSAS (Japan)
	- GAGAN (India)

	</div>

	</div>

	[^2]:
		!!! warning "Feature Under Development"
			Support for the `L1C` frequency band has not been implemented.
	[^3]:
		!!! warning "Feature Under Development"
			Corrections for some of the PPP services have not been implemented.

	!!! info
		For a comparison of the frequency bands supported by the LG290P GNSS modules, refer to sections **1.2**, **1.5**, and **1.6** of the [hardware design manual](./assets/component_documentation/quectel_lg290p03_hardware_design_v1-1.pdf).

	??? tip "What are Frequency Bands?"
		A [frequency band](https://en.wikipedia.org/wiki/Frequency_band) is a section of the [electromagnetic spectrum](https://en.wikipedia.org/wiki/Electromagnetic_spectrum), usually denoted by the range of its upper and lower limits. In the [radio spectrum](https://en.wikipedia.org/wiki/Radio_spectrum), these frequency bands are usually regulated by region, often through a government entity. This regulation prevents the interference of RF communication; and often includes major penalties for any interference with critical infrastructure systems and emergency services.

		<figure markdown>
		GNSS frequency bands (https://gssc.esa.int/navipedia/images/c/cf/GNSS_All_Signals.png "Click to enlarge")
		<figcaption markdown>Frequency bands of the global navigation satellite systems. (Source: [ESA](https://gssc.esa.int/navipedia/index.php?title=File:GNSS_All_Signals.png "European Space Agency"))</figcaption>
		</figure>

		However, if the various GNSS constellations share similar frequency bands, then how do they avoid interfering with one another? Without going too far into detail, the image above helps illustrate some of the characteristics, specific to the frequency bands of each system. With these characteristics in mind, along with other factors, the chart can help users to visualize how multiple GNSS constellations might co-exist with each other.

		For more information, users may find these articles of interest:

		- [GNSS signal](https://gssc.esa.int/navipedia/index.php/GNSS_signal)
		- [GPS Signal Plan](https://gssc.esa.int/navipedia/index.php?title=GPS_Signal_Plan)
		- [GLONASS Signal Plan](https://gssc.esa.int/navipedia/index.php?title=GLONASS_Signal_Plan)
		- [GALILEO Signal Plan](https://gssc.esa.int/navipedia/index.php?title=GALILEO_Signal_Plan)

??? tip "GNSS Accuracy"
	The accuracy of the position reported from the LG290P GNSS module, can be improved based upon the correction method being employed. Currently, [RTK](https://en.wikipedia.org/wiki/	Real-time_kinematic_positioning "Real-Time Kinematic") corrections provide the highest level of accuracy; however, users should be aware of certain limitations of the system:

	- RTK technique requires real-time correction data from a reference station or network of base stations.
		- RTK corrections usually come from RTCM messages that are signal specific *(i.e. an RTK network may only provide corrections for specific signals; only `E5b` and not `E5a`)*.
	- The range of the base stations will vary based upon the method used to transmit the correction data.
	- The reliability of RTK corrections are inherently reduced in [multipath environments](https://en.wikipedia.org/wiki/Multipath_propagation).

	<article style="text-align: center;" markdown>

	| Correction Method                                                                             | Horizontal                   | Vertical                | Velocity                                |
	| :-------------------------------------------------------------------------------------------- | :--------------------------: | :---------------------: | :-------------------------------------: |
	| Standalone                                                                                    | 0.7m<br>~2.3'                | 2.5m<br>~8.2'           | 3cm/s (0.108kph)<br>~1.2in/s (0.067mph) |
	| [RTK](https://en.wikipedia.org/wiki/Real-time_kinematic_positioning "Real-Time Kinematic")    | **0.8cm** *(+1ppm)*<br>~0.3" | 1.5cm *(+1ppm)*<br>~.6" |                                         |

	</article>

	??? info "RTK Corrections"
		To understand how RTK works, users will need a more fundamental understanding of the signal error sources.

		<div class="grid cards" markdown align="center">

		-   <a href="https://www.sparkfun.com/news/7533">
			<figure markdown>
			Tutorial Thumbnail
			</figure>

			---

			**Real-Time Kinematics Explained**</a>

		-   <a href="https://www.sparkfun.com/news/7138">
			<figure markdown>
			Tutorial Thumbnail
			</figure>

			---

			**What is Correction Data?**</a>

		</div>

### Peripherals and I/O Pins
The LG290P GNSS features several peripheral interfaces and I/O pins. Some of these are broken out as pins on the Quad-band GNSS RTK breakout board; whereas, others are broken out to their specific interface *(i.e. USB connector, JST connector, etc.)*. Additionally, some of their connections are tied to other components on the board.

<div class="grid" markdown>

<div markdown>

<figure markdown>
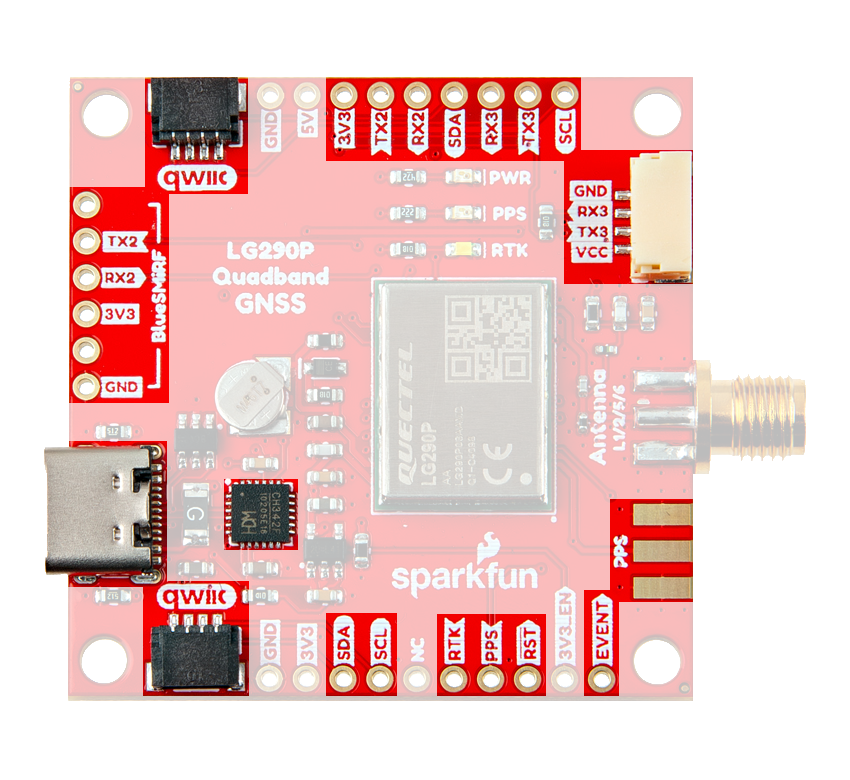
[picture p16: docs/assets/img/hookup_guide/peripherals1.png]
Peripherals interfaces

<figcaption markdown>The peripheral interfaces and I/O pins on the Quad-band GNSS RTK breakout board.</figcaption>
</figure>

</div>

<div markdown>
**Interfaces:**

- UART (x3)
- ~~SPI[^1]~~
- ~~I^2^C[^1]~~
- ~~Event Trigger[^4]~~
- Timing Signal
- RTK Signal
- Module Reset

[^4]:
	!!! warning "Feature Under Development"
		The event trigger has not been implemented.

</div>

</div>

=== "UARTs"
	The LG290P GNSS has three UART ports, which can be operated and configured separately.

	<div class="grid" markdown>

	<div markdown>

	<figure markdown>
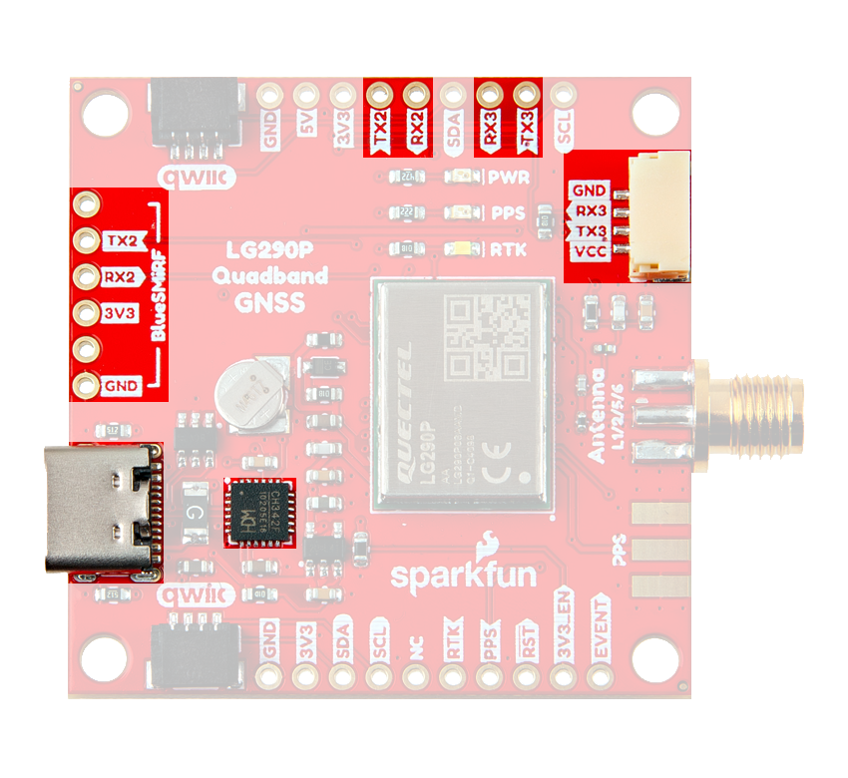
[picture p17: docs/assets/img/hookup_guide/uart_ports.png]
UART interface
	
	<figcaption markdown>The UART ports on the Quad-band GNSS RTK breakout board.</figcaption>
	</figure>

	</div>

	<div markdown>

	!!! info "Default Configuration"
		By default, the UART ports are configured with the following settings:

		- Logic Level: **3.3V**
		- Baudrate: **460800bps**
		- Data Bits: 8
		- Parity: No
		- Stop Bits: 1
		- Flow Control: None
		- Protocols:
			- `NMEA 0183`
			- `RTCM 3.x`

	??? tip "Pin Connections"
		When connecting to the board's UART pins to another device, the pins should be connected based upon the flow of their data.

		<article style="text-align: center;" markdown>

		<table>
		<tr>
		<th>Board</th>
		<td align="center">RX</td>
		<td align="center">TX</td>
		<td align="center">GND</td>
		</tr>
		<tr>
		<th>UART Device</th>
		<td align="center">TX</td>
		<td align="center">RX</td>
		<td align="center">GND</td>
		</tr>
		</table>

		</article>

	</div>

	</div>

	=== "`UART1`"
		<div class="annotate" markdown>

		`UART1` can only be accessed from the USB-C connector, through the CH342 serial-to-USB converter. For Windows and MacOS computers (1), a [USB driver must be installed](#ch342-dual-uart-converter) in order to communicate with the LG290P module through the CH342 converter. Once the USB driver is installed:

		- Two virtual `COM` ports are emulated, which can be used as standard `COM` ports to access the receiver.
		- Users should select `COM` port with the lower enumeration or listed as `Channel A`.

		</div>

		1. On Linux, the standard Linux CDC-ACM driver is suitable.

	=== "`UART2`"
		`UART2` is available through the breakout [PTH](https://en.wikipedia.org/wiki/Through-hole_technology "Plated Through Holes") pins or the *BlueSMiRF header* pins. The pin layout of the BlueSMiRF header is pin compatible with many of our serial devices (i.e. [UART adapters](https://www.sparkfun.com/categories/349), [*serial* data loggers](https://www.sparkfun.com/categories/589), [BlueSMiRF transceivers](https://www.sparkfun.com/categories/tags/bluesmirf)).

	=== "`UART3`"
		`UART3` is available through the breakout [PTH](https://en.wikipedia.org/wiki/Through-hole_technology "Plated Through Holes") pins or the locking JST connector. The pin layout of the 4-pin locking JST connector is compatible with many of our [serial radios and adapter cables](../hardware_assembly/#radio-transceivers).

	??? info "UART Protocols"
		#### UART Protocols
		By default, these UART ports are configured to transmit and receive `NMEA 0183` and/or `RTCM 3.x` messages. These messages are generally used for transmitting PNT data; and providing or receiving RTK corrections, respectively. Quectel also implements a system of proprietary messages (`PQTM`) for users to configure the LG290P that follows a data format similar to the `NMEA` protocol. The expected structure of these proprietary messages is shown below:

		<figure markdown>
		NMEA data structure
		<figcaption markdown>The data structure of Quectel messages for the `NMEA` protocol.</figcaption>
		</figure>

		=== "NMEA"
			A full list of compatible `NMEA 0183` v4.11 messages, is provided in section **2.2. Standard Messages** of the [GNSS Protocol Specification](./assets/component_documentation/quectel_lg290p03lgx80p03_gnss_protocol_specification_v1-1.pdf) manual. This protocol is used for outputting GNSS data, as detailed by the [National Marine Electronics Association](https://www.nmea.org/) organization.

			??? abstract "List of Standard NMEA Messages"
				<article style="text-align: center;" markdown>

				| Message | Type Mode | Message Description               |
				| :-----: | :-------: | :-------------------------------- |
				| RMC | Output | Recommended Minimum Specific GNSS Data   |
				| GGA | Output | Global Positioning System Fix Data       |
				| GSV | Output | GNSS Satellites in View                  |
				| GSA | Output | GNSS DOP and Active Satellites           |
				| VTG | Output | Course Over Ground & Ground Speed        |
				| GLL | Output | Geographic Position – Latitude/Longitude |

				</article>

		=== "PQTM"
			A full list of PQTM messages (proprietary NMEA messages defined by Quectel) supported by LG290P, is provided in section **2.3. PQTM Messages** of the [GNSS Protocol Specification](./assets/component_documentation/quectel_lg290p03lgx80p03_gnss_protocol_specification_v1-1.pdf) manual. This protocol is used to configure or read the settings for the LG290P GNSS module.

			??? abstract "List of Proprietary Quectel Messages"
				<article style="text-align: center;" markdown>

				| Message            | Type Mode    | Message Description                              |
				| :----------------- | :----------: | :----------------------------------------------- |
				| PQTMVER            | Output       | Outputs the firmware version                     |
				| PQTMCOLD           | Input        | Performs a cold start                            |
				| PQTMWARM           | Input        | Performs a warm start                            |
				| PQTMHOT            | Input        | Performs a hot start                             |
				| PQTMSRR            | Input        | Performs a system reset and reboots the receiver |
				| PQTMUNIQID         | Output       | Queries the module unique ID                     |
				| PQTMSAVEPAR        | Input        | Saves the configurations into NVM                |
				| PQTMRESTOREPAR     | Input        | Restores the parameters configured by all commands to their default values |
				| PQTMVERNO          | Output       | Queries the firmware version                     |
				| PQTMCFGUART        | Input/Output | Sets/gets the UART interface                     |
				| PQTMCFGPPS         | Input/Output | Sets/gets the PPS feature                        |
				| PQTMCFGPROT        | Input/Output | Sets/gets the input and output protocol for a specified port |
				| PQTMCFGNMEADP      | Input/Output | Sets/gets the decimal places of standard NMEA messages |
				| PQTMEPE            | Output       | Outputs the estimated position error             |
				| PQTMCFGMSGRATE     | Input/Output | Sets/gets the message output rate on the current interface |
				| PQTMVEL            | Output       | Outputs the velocity information                 |
				| PQTMCFGGEOFENCE    | Input/Output | Sets/gets geofence feature                       |
				| PQTMGEOFENCESTATUS | Output       | Outputs the geofence status                      |
				| PQTMGNSSSTART      | Input        | Starts GNSS engine                               |
				| PQTMGNSSSTOP       | Input        | Stops GNSS engine                                |
				| PQTMTXT            | Output       | Outputs short text messages                      |
				| PQTMCFGSVIN        | Input/Output | Sets/gets the Survey-in feature                  |
				| PQTMSVINSTATUS     | Output       | Outputs the Survey-in status                     |
				| PQTMPVT            | Output       | Outputs the PVT (GNSS only) result               |
				| PQTMCFGRCVRMODE    | Input/Output | Sets/gets the receiver working mode              |
				| PQTMDEBUGON        | Input        | Enables debug log output                         |
				| PQTMDEBUGOFF       | Input        | Disables debug log output                        |
				| PQTMCFGFIXRATE     | Input/Output | Sets/gets the fix interval                       |
				| PQTMCFGRTK         | Input/Output | Sets/gets the RTK mode                           |
				| PQTMCFGCNST        | Input/Output | Sets/gets the constellation configuration        |
				| PQTMDOP            | Output       | Outputs dilution of precision                    |
				| PQTMPL             | Output       | Outputs protection level information             |
				| PQTMCFGODO         | Input/Output | Sets/gets the odometer feature                   |
				| PQTMRESETODO       | Input        | Resets the accumulated distance recorded by the odometer |
				| PQTMODO            | Output       | Outputs the odometer information                 |
				| PQTMCFGSIGNAL      | Input/Output | Sets/gets GNSS signal mask                       |
				| PQTMCFGSAT         | Input/Output | Sets/gets GNSS satellite mask                    |
				| PQTMCFGRSID        | Input/Output | Sets/gets the reference station ID               |
				| PQTMCFGRTCM        | Input/Output | Sets/gets RTCM                                   |

				</article>

		=== "RTCM"
			A full list of compatible `RTCM v3` messages, is provided in section **3. RTCM Protocol** of the [GNSS Protocol Specification](./assets/component_documentation/quectel_lg290p03lgx80p03_gnss_protocol_specification_v1-1.pdf) manual. This protocol is used for transferring GNSS raw measurement data, as detailed by the [Radio Technical Commission for Maritime Services](https://www.rtcm.org/) organization.

			??? abstract "List of Supported RTCMv3 *(MSM)* Messages"
				<article style="text-align: center;" markdown>

				| Message | Type Mode | Message Description                              |
				| :--: | :----------: | :----------------------------------------------- |
				| 1005 | Input/Output | Stationary RTK Reference Station ARP             |
				| 1006 | Input/Output | Stationary RTK Reference Station ARP with height |
				| 1019 | Input/Output | GPS Ephemerides                                  |
				| 1020 | Input/Output | GLONASS Ephemerides                              |
				| 1041 | Input/Output | NavIC/IRNSS Ephemerides                          |
				| 1042 | Input/Output | BDS Satellite Ephemeris Data                     |
				| 1044 | Input/Output | QZSS Ephemerides                                 |
				| 1046 | Input/Output | Galileo I/NAV Satellite Ephemeris Data           |
				| 1073 | Input/Output | GPS MSM3 |
				| 1074 | Input/Output | GPS MSM4 |
				| 1075 | Input/Output | GPS MSM5 |
				| 1076 | Input/Output | GPS MSM6 |
				| 1077 | Input/Output | GPS MSM7 |
				| 1083 | Input/Output | GLONASS MSM3 |
				| 1084 | Input/Output | GLONASS MSM4 |
				| 1085 | Input/Output | GLONASS MSM5 |
				| 1086 | Input/Output | GLONASS MSM6 |
				| 1087 | Input/Output | GLONASS MSM7 |
				| 1093 | Input/Output | Galileo MSM3 |
				| 1094 | Input/Output | Galileo MSM4 |
				| 1095 | Input/Output | Galileo MSM5 |
				| 1096 | Input/Output | Galileo MSM6 |
				| 1097 | Input/Output | Galileo MSM7 |
				| 1113 | Input/Output | QZSS MSM3 |
				| 1114 | Input/Output | QZSS MSM4 |
				| 1115 | Input/Output | QZSS MSM5 |
				| 1116 | Input/Output | QZSS MSM6 |
				| 1117 | Input/Output | QZSS MSM7 |
				| 1123 | Input/Output | BDS MSM3 |
				| 1124 | Input/Output | BDS MSM4 |
				| 1125 | Input/Output | BDS MSM5 |
				| 1126 | Input/Output | BDS MSM6 |
				| 1127 | Input/Output | BDS MSM7 |
				| 1133 | Input/Output | NavIC/IRNSS MSM3 |
				| 1134 | Input/Output | NavIC/IRNSS MSM4 |
				| 1135 | Input/Output | NavIC/IRNSS MSM5 |
				| 1136 | Input/Output | NavIC/IRNSS MSM6 |
				| 1137 | Input/Output | NavIC/IRNSS MSM7 |

				</article>

=== "PPS Output"
	From the module, the [PPS](https://en.wikipedia.org/wiki/Pulse-per-second_signal "Pulse Per Second") output signal is a 3.3V signal output that can be access through the SMA connector and/or the `PPS` [PTH](https://en.wikipedia.org/wiki/Through-hole_technology "Plated Through Holes") pin. The signal is also connected to the `PPS` LED, which can be used as a visual indicator for its operation.

	<figure markdown>
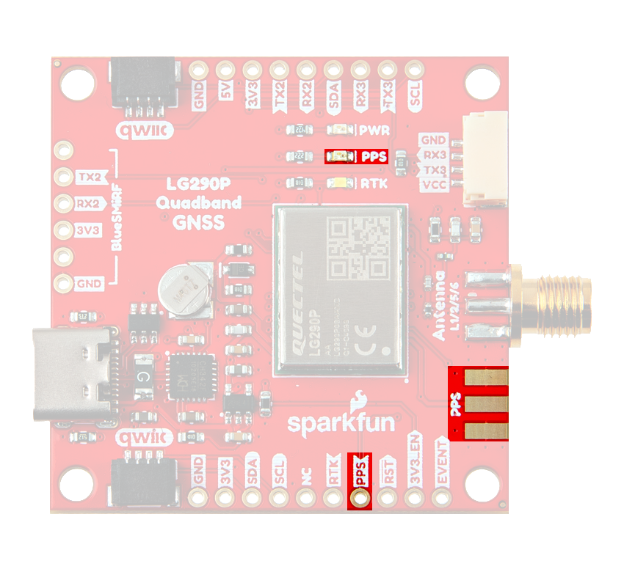
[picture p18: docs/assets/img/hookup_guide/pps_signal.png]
I/O for PPS signal
	
	<figcaption markdown>The timing signal's outputs on the Quad-band GNSS RTK breakout board.</figcaption>
	</figure>

	??? tip "Jumpers"
		*See the **[Jumpers](#jumpers)** section for more details.*

		- There is a jumper attached to the `PPS` PTH pin. When cut, it disconnects the pin from the PPS signal.
		- There is a jumper attached to the `PPS` LED. For low power applications, the jumper can be cut to disable the `PPS` LED.

	??? tip "Use Case"
		- Users could use this signal in conjunction with the event pins to synchronize two modules with each other.
		- Users could use this signal to create their own **Stratum 0** source for the [NTP](https://en.wikipedia.org/wiki/Network_Time_Protocol "Network Time Protocol") on a primary time server.

=== "RTK"
	The `RTK` [PTH](https://en.wikipedia.org/wiki/Through-hole_technology "Plated Through Holes") pin operates as both the `RTK_STAT` status indicator for the RTK positioning and `ANT_ON` power control for the external LNA or active antenna power. The pin is also connected to the `RTK` LED, which can be used as a visual indicator for its operation.

	<figure markdown>
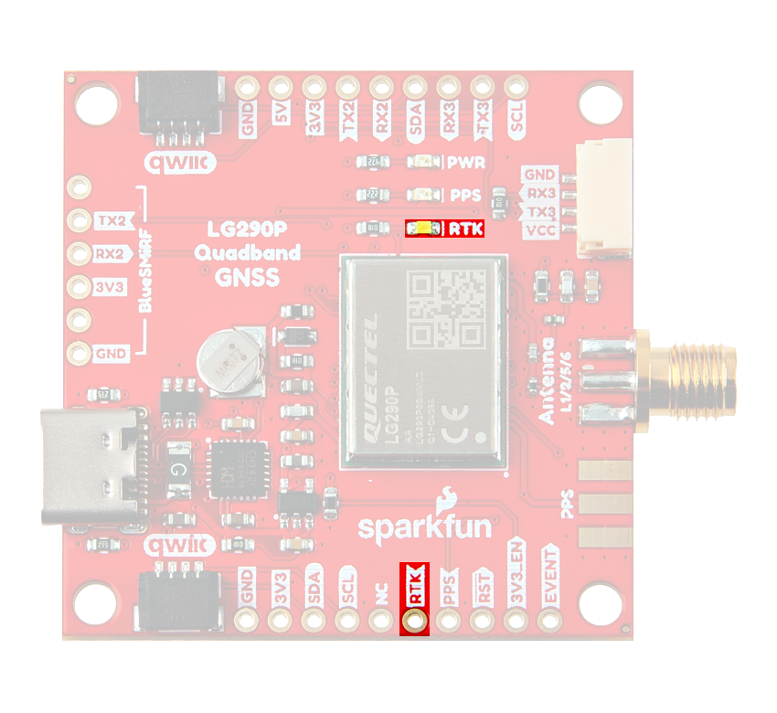
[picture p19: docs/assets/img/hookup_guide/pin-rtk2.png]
I/O for RTK signal
	
	<figcaption markdown>The RTK signal's outputs on the Quad-band GNSS RTK breakout board.</figcaption>
	</figure>

	=== "`RTK_STAT`"
		In this configuration, the pin is set to a high level at startup.

		1. If the pin output is high, it indicates the module has entered the RTK fixed mode.
		2. If the pin output is low, it indicates that the module exited the RTK fixed mode.
		3. If the pin outputs an alternating pin level, it indicates that the module received the correct RTCM data and did not enter the RTK fixed mode.

	=== "`ANT_ON`"
		In this configuration, the pin is used to control the external LNA or active antenna power supply.

		- When the pin is high, the antenna is powered.
		- When the pin is low, the antenna is not powered.

	??? tip "Jumpers"
		*See the **[Jumpers](#jumpers)** section for more details.*

		- There is a jumper attached to the `RTK` LED. For low power applications, the jumper can be cut to disable the `RTK` LED.

=== "Reset"
	The `RST` pin can be used to reset the LG290P module if it enters an abnormal state. To reset the GNSS module, the pin must be low for more than 100ms.

	<figure markdown>
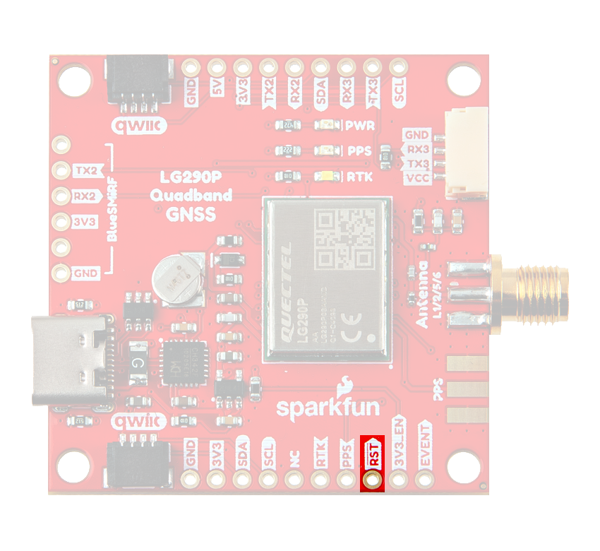
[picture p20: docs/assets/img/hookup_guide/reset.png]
Reset Pin
	
	<figcaption markdown>The `RST` pin on the Quad-band GNSS RTK breakout board.</figcaption>
	</figure>

<!-- === "Event" -->
<!-- === "I<sup>2</sup>C" -->

## SMA Connectors
While there are two SMD pads for SMA connectors, only the antenna's SMA connector is populated on the Quad-band GNSS RTK breakout board. The `Antenna` `L1/2/5/6` connector is an input for the GNSS antenna. Whereas, the `PPS` SMD pad provides a output for the **[PPS timing signal](#pps-output)**.

<div class="grid" markdown>

<div markdown>

<figure markdown>
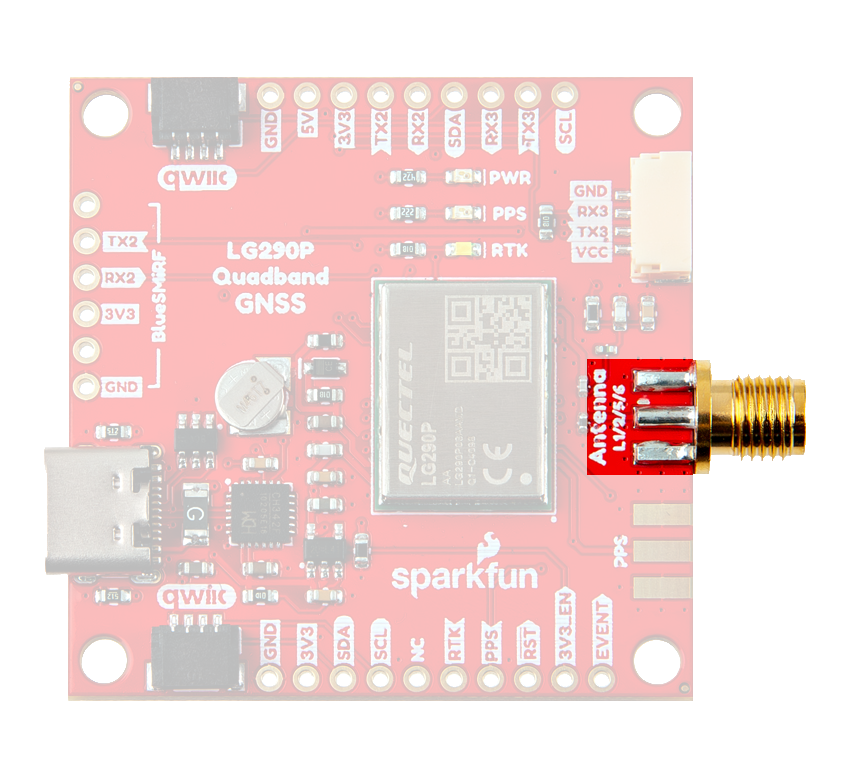
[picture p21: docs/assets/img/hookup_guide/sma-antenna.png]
SMA Connector

<figcaption markdown>The SMA connector for an external GNSS antenna on the Quad-band GNSS RTK breakout board.</figcaption>
</figure>

</div>

<div markdown>

<figure markdown>
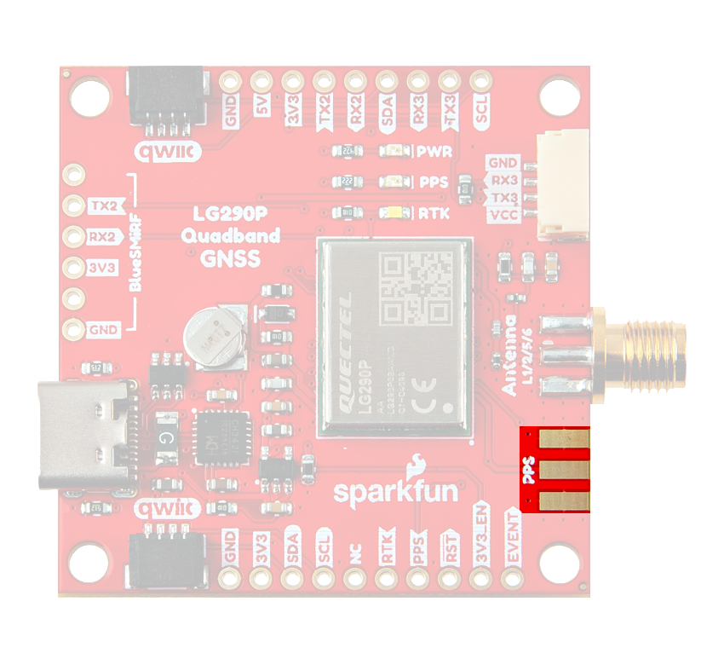
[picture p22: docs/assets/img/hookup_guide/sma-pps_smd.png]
SMD Pads

<figcaption markdown>The SMD pads to add an SMA connector for the **[PPS output](#pps-output)** from the Quad-band GNSS RTK breakout board.</figcaption>
</figure>

</div>

</div>

!!! warning "Antenna Specifications"
	- Passive antennas are not recommended for the LG290P GNSS module.
	- To mitigate the impact of out-of-band signals, utilize an active antenna whose SAW filter is placed in front of the LNA in the internal framework.
		- **DO NOT** select and antenna with the LNA placed in the front.
	- There is no need to inject an external DC voltage into the SMA connector for the GNSS antenna. Power is already provided from the LG290P module for the LNA of an active antenna.

## JST Connector
The Quad-band GNSS RTK breakout features a 4-pin [JST GH connector](./assets/component_documentation/JST-GH_datasheet.pdf), which is polarized and locking. Users can access the pins of the `UART3` port, through the JST connector with our [breadboard cable](https://www.sparkfun.com/breadboard-to-jst-ghr-04v-cable-4-pin-x-1-25mm-pitch.html)(1) or through the PTH pins. The pin layout of the JST connector is compatible with many of our [serial radios and adapter cables](../hardware_assembly/#radio-transceivers).
{ .annotate }

1. <a href="https://www.sparkfun.com/breadboard-to-jst-ghr-04v-cable-4-pin-x-1-25mm-pitch.html">
	<figure markdown>
	Product Thumbnail
	</figure>

	---

	**Breadboard to JST-GHR-04V Cable - 4-Pin x 1.25mm Pitch**<br>
	CAB-17240</a>

<figure markdown>
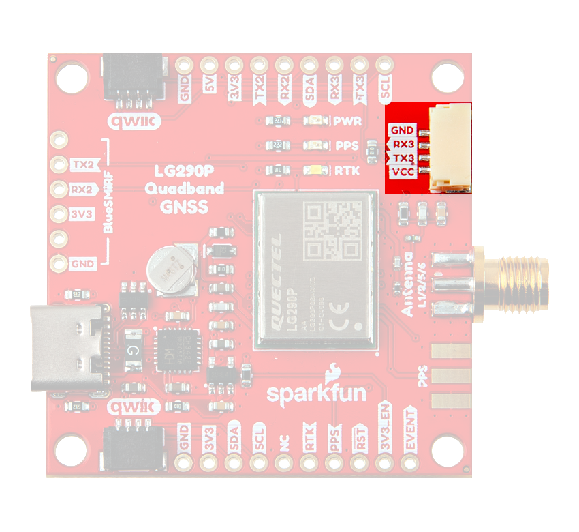
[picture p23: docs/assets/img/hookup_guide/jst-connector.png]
JST connector

<figcaption markdown>The JST connector on the Quad-band GNSS RTK breakout board.</figcaption>
</figure>

??? info "Pin Connections"
	#### Pin Connections
	When connecting the Quad-band GNSS RTK breakout board to other products, users need to be aware of the pin connections between the devices.

	<article style="text-align: center;" markdown>

	<table border="1" markdown>
	<tr>
	<th style="vertical-align:middle;">Pin Number</th>
	<td align="center">
		**1**<br>
		*(Left Side)*
	</td>
	<td align="center">**2**</td>
	<td align="center">**3**</td>
	<td align="center">**4**</td>
	</tr>
	<tr>
	<th>Label</th>
	<td align="center">VCC</td>
	<td align="center">TX3</td>
	<td align="center">RX3</td>
	<td align="center">GND</td>
	</tr>
	<tr>
	<th style="vertical-align:middle;">Function</th>
	<td>
		<u>**Voltage Output**</u><br>
		- **Default: 3.3V**<br>
		- Selectable: 3.3V or 5V
	</td>
	<td align="center" style="vertical-align:middle;">`UART3` - Receive</td>
	<td align="center" style="vertical-align:middle;">`UART3` - Transmit</td>
	<td align="center" style="vertical-align:middle;">Ground</td>
	</tr>
	</table>

	</article>

	<div class="grid" markdown>

	<div markdown>

	When connecting the Quad-band GNSS RTK breakout board to our radios, the pin connections should follow the table below. If the flow control is not enabled, the only the `RX`, `TX`, and `GND` pins are utilized.

	<article style="text-align: center;" markdown>

	<table markdown>
	<tr>
	<th>Board</th>
	<td align="center">RX</td>
	<td align="center">TX</td>
	<td align="center">GND</td>
	</tr>
	<tr>
	<th>Radio</th>
	<td align="center">TX</td>
	<td align="center">RX</td>
	<td align="center">GND</td>
	</tr>
	</table>

	</article>

	</div>

	<div markdown>

	As documented in the [LoRaSerial product manual](https://docs.sparkfun.com/SparkFun_LoRaSerial), the pin connections between a host system *(i.e. Quad-band GNSS RTK breakout board)* and the LoRaSerial Kit radio is outlined in the image below.

	<figure markdown>
	Flow Control (https://docs.sparkfun.com/SparkFun_LoRaSerial/img/SAMD21%20Flow%20control.png "Click to enlarge")
	<figcaption markdown>The `COM` ports on the Quad-band GNSS RTK breakout board.</figcaption>
	</figure>

	</div>

	</div>

## BlueSMiRF Header
The Quad-band GNSS RTK breakout features a 6-pin BlueSMiRF [PTH](https://en.wikipedia.org/wiki/Through-hole_technology "Plated Through Holes") header for `UART2`. The pin layout of which, is compatible with many of our serial devices (i.e. [UART adapters](https://www.sparkfun.com/categories/349), [*serial* data loggers](https://www.sparkfun.com/categories/589), [BlueSMiRF transceivers](https://www.sparkfun.com/categories/tags/bluesmirf)).

<figure markdown>
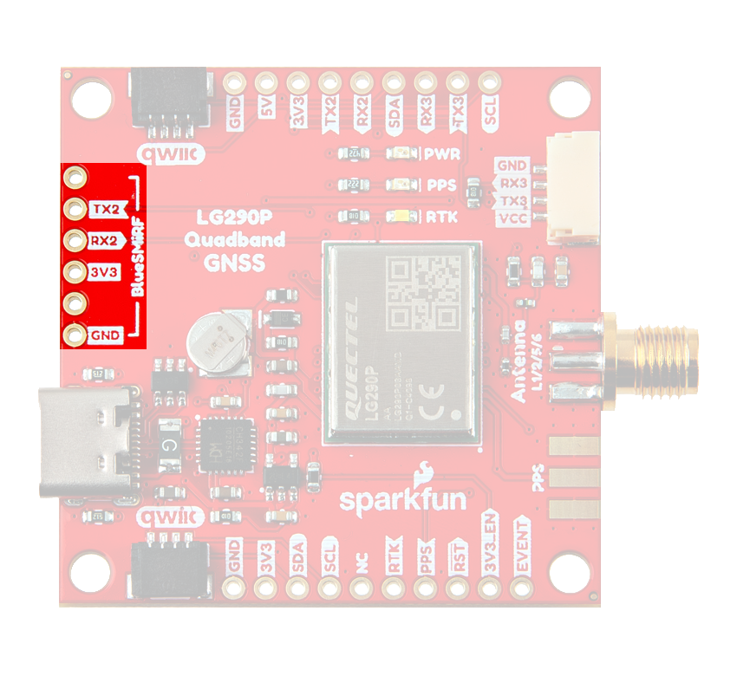
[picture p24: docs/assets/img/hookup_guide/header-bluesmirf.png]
BlueSMiRF header

<figcaption markdown>The 6-pin BlueSMiRF PTH header on the Quad-band GNSS RTK breakout board.</figcaption>
</figure>

??? info "Pin Connections"
	#### Pin Connections
	When connecting the Quad-band GNSS RTK breakout board to other products, users need to be aware of the pin connections between the devices.

	<article style="text-align: center;" markdown>

	<table border="1" markdown>
	<tr>
	<th style="vertical-align:middle;">Pin Number</th>
	<td align="center">
		**1**<br>
		*(Left Side)*
	</td>
	<td align="center">**2**</td>
	<td align="center">**3**</td>
	<td align="center">**4**</td>
	<td align="center">**5**</td>
	<td align="center">**6**</td>
	</tr>
	<tr>
	<th>Label</th>
	<td></td>
	<td align="center">TX2</td>
	<td align="center">RX2</td>
	<td align="center">3V3</td>
	<td></td>
	<td align="center">GND</td>
	</tr>
	<tr>
	<th>Function</th>
	<td></td>
	<td align="center">`UART2` - Receive</td>
	<td align="center">`UART2` - Transmit</td>
	<td align="center">3.3V</td>
	<td></td>
	<td align="center">Ground</td>
	</tr>
	</table>

	</article>

## Status LEDs
There are three status LEDs on the Quad-band GNSS RTK breakout board:

<div class="grid" markdown>

<div markdown>

<figure markdown>
Status LEDs
<figcaption markdown>The status LED indicators on the Quad-band GNSS RTK breakout board.</figcaption>
</figure>

</div>

<div markdown>

- `PWR` - Power *(Red)*
	- Turns on once 3.3V power is supplied to the board
- `PPS` - Pulse-Per-Second *(Yellow)*
	- Indicates when there is a pulse-per-second signal *(see the **[PPS Output](#pps-output)** section)*
- `RTK` - [RTK](https://en.wikipedia.org/wiki/Real-time_kinematic_positioning "Real-Time Kinematic") Mode *(White)*
	- Indicates when an RTK fix has been established or when the correct RTCM data is being received *(see the **[RTK](#rtk)** section)*

</div>

</div>

## Jumpers

??? note "Never modified a jumper before?"
	Check out our <a href="https://learn.sparkfun.com/tutorials/664">Jumper Pads and PCB Traces tutorial</a> for a quick introduction!

	<div class="grid cards" markdown align="center">

	-   <a href="https://learn.sparkfun.com/tutorials/664">
		<figure markdown>
		Tutorial thumbnail
		</figure>

		---

		**How to Work with Jumper Pads and PCB Traces**</a>

	</div>

There are seven jumpers on the back of the board that can be used to easily modify the hardware connections on the board. From which, there are three jumpers that control power to the status LEDs on the board. By default, all the jumpers are connected, to power the status LEDs. For low power applications, users can cut the jumpers to disconnect power from each of the LEDs.

<figure markdown>
Jumpers
<figcaption markdown>The jumpers on the back of the Quad-band GNSS RTK breakout board.</figcaption>
</figure>

- **`VSEL`** - This jumper can be modified to configure/disconnect the `VCC` pin of the 4-pin locking JST connector to/from `3V3` or `5V` power.
- **`BT_VCC`** - This jumper can be cut to disconnect the `3V3` BlueSMiRF header pin from the 3.3V output of the RT9080 LDO regulator.
- **`PWR`** - This jumper can be cut to remove power from the red, power LED.
- **`PPS`** - This jumper can be cut to remove power from the yellow LED, which is connected to the [PPS](https://en.wikipedia.org/wiki/Pulse-per-second_signal "Pulse Per Second") signal.
- **`RTK`** - This jumper can be cut to remove power from the white LED, indicating RTK fix or operation in RTK mode.
- **`PPS-DC`** - This jumper can be cut to disconnect the [pulse per second](https://en.wikipedia.org/wiki/Pulse-per-second_signal "Pulse Per Second") signal from the [PTH](https://en.wikipedia.org/wiki/Through-hole_technology "Plated Through Holes") pin.
- **`SHLD`** - This jumper can be cut to disconnect the shielding of the USB-C connector from the `GND` plane of the board

!!! info
	- By default, [PPS](https://en.wikipedia.org/wiki/Pulse-per-second_signal "Pulse Per Second") signal is connected to the `PPS` pin.
	- By default, the `VSEL` jumper is connected to `3V3` pad for a regulated 3.3V output on the 4-pin JST-GH connector.
	- By default, the `BT_VCC` jumper provides a regulated 3.3V output to the BlueSMiRF header.

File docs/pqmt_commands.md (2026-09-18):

---
icon: material/format-list-text
---

Below, are excerpts for a few of the PQTM messages from the [GNSS Protocol Specification](./assets/component_documentation/quectel_lg290p03lgx80p03_gnss_protocol_specification_v1-1.pdf) manual. Users will find these useful for configuring their LG290P GNSS module as an RTK base station or rover.

???+ info "Documentation"
	A full list of PQTM messages (proprietary NMEA messages defined by Quectel) supported by LG290P, is provided in section **2.3. PQTM Messages** of the [GNSS Protocol Specification](./assets/component_documentation/quectel_lg290p03lgx80p03_gnss_protocol_specification_v1-1.pdf) manual. This protocol is used to configure or read the settings for the LG290P GNSS module.

	??? abstract "List of Proprietary Quectel Messages"
		<article style="text-align: center;" markdown>

		| Message                             | Type Mode    | Message Description                              |
		| :---------------------------------- | :----------: | :----------------------------------------------- |
		| PQTMVER                             | Output       | Outputs the firmware version                     |
		| PQTMCOLD                            | Input        | Performs a cold start                            |
		| PQTMWARM                            | Input        | Performs a warm start                            |
		| PQTMHOT                             | Input        | Performs a hot start                             |
		| PQTMSRR                             | Input        | Performs a system reset and reboots the receiver |
		| PQTMUNIQID                          | Output       | Queries the module unique ID                     |
		| [PQTMSAVEPAR](#pqtmsavepar)         | Input        | Saves the configurations into NVM                |
		| [PQTMRESTOREPAR](#pqtmrestorepar)   | Input        | Restores the parameters configured by all commands to their default values |
		| PQTMVERNO                           | Output       | Queries the firmware version                     |
		| [PQTMCFGUART](#pqtmcfguart)         | Input/Output | Sets/gets the UART interface                     |
		| PQTMCFGPPS                          | Input/Output | Sets/gets the PPS feature                        |
		| [PQTMCFGPROT](#pqtmcfgprot)         | Input/Output | Sets/gets the input and output protocol for a specified port |
		| PQTMCFGNMEADP                       | Input/Output | Sets/gets the decimal places of standard NMEA messages |
		| PQTMEPE                             | Output       | Outputs the estimated position error             |
		| PQTMCFGMSGRATE                      | Input/Output | Sets/gets the message output rate on the current interface |
		| PQTMVEL                             | Output       | Outputs the velocity information                 |
		| PQTMCFGGEOFENCE                     | Input/Output | Sets/gets geofence feature                       |
		| PQTMGEOFENCESTATUS                  | Output       | Outputs the geofence status                      |
		| PQTMGNSSSTART                       | Input        | Starts GNSS engine                               |
		| PQTMGNSSSTOP                        | Input        | Stops GNSS engine                                |
		| PQTMTXT                             | Output       | Outputs short text messages                      |
		| [PQTMCFGSVIN](#pqtmcfgsvin)         | Input/Output | Sets/gets the Survey-in feature                  |
		| PQTMSVINSTATUS                      | Output       | Outputs the Survey-in status                     |
		| PQTMPVT                             | Output       | Outputs the PVT (GNSS only) result               |
		| [PQTMCFGRCVRMODE](#pqtmcfgrcvrmode) | Input/Output | Sets/gets the receiver working mode              |
		| PQTMDEBUGON                         | Input        | Enables debug log output                         |
		| PQTMDEBUGOFF                        | Input        | Disables debug log output                        |
		| PQTMCFGFIXRATE                      | Input/Output | Sets/gets the fix interval                       |
		| [PQTMCFGRTK](#pqtmcfgrtk)           | Input/Output | Sets/gets the RTK mode                           |
		| PQTMCFGCNST                         | Input/Output | Sets/gets the constellation configuration        |
		| PQTMDOP                             | Output       | Outputs dilution of precision                    |
		| PQTMPL                              | Output       | Outputs protection level information             |
		| PQTMCFGODO                          | Input/Output | Sets/gets the odometer feature                   |
		| PQTMRESETODO                        | Input        | Resets the accumulated distance recorded by the odometer |
		| PQTMODO                             | Output       | Outputs the odometer information                 |
		| PQTMCFGSIGNAL                       | Input/Output | Sets/gets GNSS signal mask                       |
		| PQTMCFGSAT                          | Input/Output | Sets/gets GNSS satellite mask                    |
		| PQTMCFGRSID                         | Input/Output | Sets/gets the reference station ID               |
		| PQTMCFGRTCM                         | Input/Output | Sets/gets RTCM                                   |

		</article>

## Save Parameters/Restore to Default Settings

#### `PQTMSAVEPAR`
:   Saves the current configurations into NVM of the LG290P

	```
	$PQTMSAVEPAR*<Checksum><CR><LF>
	```

	??? example
		Save the current settings to non-volatile memory of the LG290P.
		```
		$PQTMSAVEPAR*5A
		```

		If there are no errors, users will receive the following response:
		```
		$PQTMSAVEPAR,OK*72
		```

#### `PQTMRESTOREPAR`
:   Restores the parameters configured by all commands to their default values; this command takes effect after restarting the LG290P

	```
	$PQTMRESTOREPAR*<Checksum><CR><LF>	
	```

	??? example
		Restore all the settings of the LG290P to their factory defaults
		```
		$PQTMRESTOREPAR*13
		```

		If there are no errors, users will receive the following response:
		```
		$PQTMRESTOREPAR,OK*3B
		```

## UART Settings

#### `PQTMCFGUART`
:   Configures the serial protocol setting for the UART interfaces

	- Current UART interface:

		```
		$PQTMCFGUART,W,<BaudRate>[,<DataBit>,<Parity>,<StopBit>,<FlowCtrl>]*<Checksum><CR><LF>
		```

	- A specific UART interface:

		```
		$PQTMCFGUART,W,<Index>,<BaudRate>[,<DataBit>,<Parity>,<StopBit>,<FlowCtrl>]*<Checksum><CR><LF>
		```

	**Parameters:**

	<table markdown>
	<tr markdown>
	<th>Field</th>
	<td markdown>`<Index>`</td>
	<td markdown>`<BaudRate>`</td>
	<td markdown>`<DataBit>`</td>
	<td markdown>`<Parity>`</td>
	<td markdown>`<StopBit>`</td>
	<td markdown>`<FlowCtrl>`</td>
	</tr>
	<tr markdown>
	<th>Description</th>
	<td markdown>
	**UART Interface**
	<ul markdown>
	<li markdown>`1` = UART1</li>
	<li markdown>`2` = UART2</li>
	<li markdown>`3` = UART3</li>
	</ul>
	</td>
	<td markdown>
	**Baud Rate** (bps)
	<ul markdown>
	<li markdown>`9600`</li>
	<li markdown>`115200`</li>
	<li markdown>`230400`</li>
	<li markdown>==`460800`==</li>
	<li markdown>`921600`</li>
	</ul>
	</td>
	<td markdown>
	**Number of Data Bits**
	<ul markdown>
	<li markdown>==`8` = 8 bits==</li>
	</ul>
	</td>
	<td markdown>
	**Parity**
	<ul markdown>
	<li markdown>==`0` = No parity==</li>
	<li markdown>`1` = Odd parity</li>
	<li markdown>`2` = Even parity</li>
	<li markdown>`3` = Mark</li>
	<li markdown>`4` = Space</li>
	</ul>
	</td>
	<td markdown>
	**Number of Stop Bit**(s)
	<ul markdown>
	<li markdown>==`1` = 1 stop bit==</li>
	<li markdown>`2` = 2 stop bits</li>
	</ul>
	</td>
	<td markdown>
	**Flow Control**
	<ul markdown>
	<li markdown>==`0` = None==</li>
	</ul>
	</td>
	</tr>
	</table>

	???+ tip "Baud Rate"
		For ports utilized in conjunction with either the BlueSMiRF or radio transceivers, we recommend reducing the baud rate to 115200bps or lower to avoid overflowing the buffers of the transceiver's serial port.

	??? example "Configure the Settings"
		!!! abstract inline end "Example Settings"

			- Port: `UART1`
			- Baud Rate: 115200bps
			- Data Bits: 8
			- Parity: No
			- Stop Bits: 1
			- Flow Control: None

		Configure the baud rate of the current UART interface to 115200bps:
		```
		$PQTMCFGUART,W,115200*18
		```

		Configure the baud rate of `UART1` to 115200bps:
		```
		$PQTMCFGUART,W,1,115200*05
		```

		Configure all parameters of the current UART interface:
		```
		$PQTMCFGUART,W,115200,8,0,1,0*11
		```

		Configure all parameters of `UART1`:
		```
		$PQTMCFGUART,W,1,115200,8,0,1,0*0C
		```

		If there are no errors, users will receive the following response:
		```
		$PQTMCFGUART,OK*60
		```

	??? example "Retrieve the Settings"
		!!! abstract inline end "Example Settings"

			- Port: `UART1`
			- Baud Rate: 115200bps
			- Data Bits: 8
			- Parity: No
			- Stop Bits: 1
			- Flow Control: None

		Get the configuration on the current UART interface:
		```
		$PQTMCFGUART,R*36
		```

		Get the configuration on UART1:
		```
		$PQTMCFGUART,R,1*2B
		```

		If there are no errors, users will receive the following response:
		```
		$PQTMCFGUART,OK,1,115200,8,0,1,0*5F
		```

#### `PQTMCFGPROT`
:   Configures the input/output protocol on a specified port

	```
	$PQTMCFGPROT,W,<PortType>,<PortID>,<InputProt>,<OutputProt>*<Checksum><CR><LF>
	```

	**Parameters:**

	<table markdown>
	<tr markdown>
	<th>Field</th>
	<td markdown>`<PortType>`</td>
	<td markdown>`<PortID>`</td>
	<td markdown>`<InputProt>`</td>
	<td markdown>`<OutputProt>`</td>
	</tr>
	<tr markdown>
	<th>Description</th>
	<td markdown>
	**Port Type**
	<ul markdown>
	<li markdown>==`1` = UART==</li>
	</ul>
	</td>
	<td markdown>
	**Port ID**
	<ul markdown>
	<li markdown>`1` = UART1</li>
	<li markdown>`2` = UART2</li>
	<li markdown>`3` = UART3</li>
	</ul>
	</td>
	<td colspan="2" markdown>
	**Input/Output Protocols** (`HEX`: 32-bit)
	<ul markdown>
	<li markdown>==Bit `0` = NMEA==</li>
	<li markdown>==Bit `2` = RTCM3==</li>
	</ul>
	The **default** protocols are NMEA and RTCM3:<br>
	==**HEX:** `00000005`==<br>
	**BIN:** `0000 0000 0000 0000 0000 0000 0000 0101`
	</td>
	</tr>
	</table>

	??? example "Configure the Settings"
		!!! abstract inline end "Example Settings"

			- Port: `UART1`
			- Input Protocol: NMEA & RTCM3
			- Input Protocol: NMEA & RTCM3

		Configure the configuration on UART1:
		```
		$PQTMCFGPROT,W,1,1,00000005,00000005*38
		```

		If there are no errors, users will receive the following response:
		```
		$PQTMCFGPROT,OK*6B
		```

	??? example "Retrieve the Settings"
		!!! abstract inline end "Example Settings"

			- Port: `UART1`
			- Input Protocol: NMEA & RTCM3
			- Input Protocol: NMEA & RTCM3

		Get the configuration on UART1:
		```
		$PQTMCFGPROT,R,1,1*3D
		```

		If there are no errors, users will receive the following response:
		```
		$PQTMCFGPROT,OK,1,1,00000005,00000005*6B
		```

## RTK Settings

#### `PQTMCFGSVIN`
:   Configures a base station's position either by **survey-in** mode or **fixed** mode

	```
	$PQTMCFGSVIN,W,<Mode>,<CFG_CNT>,<3D_AccLimit>,<ECEF_X>,<ECEF_Y>,<ECEF_Z>*<Checksum><CR><LF>
	```

	**Parameters:**

	<table markdown>
	<tr markdown>
	<th>Field</th>
	<td markdown>`<Mode>`</td>
	<td markdown>`<CFG_CNT>`</td>
	<td markdown>`<3D_AccLimit>`</td>
	<td markdown>`<ECEF_X>` `<ECEF_Y>` `<ECEF_Z>`</td>
	</tr>
	<tr markdown>
	<th>Description</th>
	<td markdown>
	**Receiver Mode**
	<ul markdown>
	<li markdown>==`0` = Disable==</li>
	<li markdown>`1` = Survey-in mode</li>
	<li markdown>`2` = Fixed mode<br>*(Position is configured in ECEF coordinates)*</li>
	</ul>
	</td>
	<td markdown>
	**Survey-in Mode**<br>
	Minimum positioning time *(seconds)*
	<ul markdown>
	<li markdown>Range: `0`-`86400`</li>
	<li markdown>==**Default:** `0`==</li>
	</ul>
	</td>
	<td markdown>
	**Survey-in Mode**<br>
	3D positioning accuracy *(meters)*
	<ul markdown>
	<li markdown>`0` = No limit</li>
	<li markdown>==**Default:** `0.0`==</li>
	</ul>
	</td>
	<td markdown>
	**Fixed Mode**<br>
	WGS84 ECEF X,Y,Z coordinates *(meters)*
	<ul markdown>
	<li markdown>==**Default:** `0.0000`==</li>
	</ul>
	</td>
	</tr>
	</table>

	???+ info "RTK Base Station Modes"
		In order to operate as a base station, the LG290P GNSS module requires an accurate position of its antenna. This can be either defined in [ECEF coordinates](https://en.wikipedia.org/wiki/Earth-centered%2C_Earth-fixed_coordinate_system) or acquired through a self-survey process.

		1. ==Survey-In Mode:== The base station's location is established based on a weighted mean of recent solutions of its position. The `<CFG_CNT>` and `<3D_AccLimit>` parameters define the shortest amount of time that the position gets surveyed and the maximum standard deviation of the estimated position.
		1. ==Fixed Mode:== The base station's position is provided in [ECEF coordinates](https://en.wikipedia.org/wiki/Earth-centered%2C_Earth-fixed_coordinate_system).
	
		!!! note
			Any error in the base station's location will translate directly into an error in the rover's position.

	??? example "Configure the Settings"
		!!! abstract inline end "Example Settings"

			- Mode: Survey-in mode
			- Survey Time: 3600 seconds
			- 3D Accuracy: 1.2m
			- ECEF Coordinates:
				- X: -2519265.0514m
				- Y: 4849534.9045m
				- Z: 3277834.6432m

		Configure the configuration on UART1:
		```
		$PQTMCFGSVIN,W,1,3600,1.2,-2519265.0514,4849534.9045,3277834.6432*01
		```

		If there are no errors, users will receive the following response:
		```
		$PQTMCFGSVIN,OK*70
		```

	??? example "Retrieve the Settings"
		!!! abstract inline end "Example Settings"

			- Mode: Survey-in mode
			- Survey Time: 3600 seconds
			- 3D Accuracy: 1.2m
			- ECEF Coordinates:
				- X: -2519265.0514m
				- Y: 4849534.9045m
				- Z: 3277834.6432m

		Get the configuration on UART1:
		```
		$PQTMCFGSVIN,R*26
		```

		If there are no errors, users will receive the following response:
		```
		$PQTMCFGSVIN,OK,1,3600,1.2,-2519265.0514,4849534.9045,3277834.6432*52
		```

#### `PQTMCFGRCVRMODE`
:   Configures the mode that the receiver is operating in

	```
	$PQTMCFGRCVRMODE,W,<Mode>*<Checksum><CR><LF>
	```

	**Parameters:**

	<table markdown>
	<tr markdown>
	<th>Field</th>
	<td markdown>`<Mode>`</td>
	</tr>
	<tr markdown>
	<th>Description</th>
	<td markdown>
	**Operation mode**
	<ul markdown>
	<li markdown>`0` = Unknown</li>
	<li markdown>
	**`1` = Rover**<br>
	When set to this mode, the receiver will restore to default NMEA message output state.
	</li>
	<li markdown>`2` = Base Station<br>
	When set to this mode, the receiver will automatically disable NMEA message output and enable RTCM `MSM4` and RTCMv3 `1005` message output.
	</li>
	</ul>
	</td>
	</tr>
	</table>

	!!! note
		After switching the module‘s working mode, save the configuration and then reset the module. Otherwise, it will continue to operate in the original mode.

	??? example "Configure the Settings"
		!!! abstract inline end "Example Settings"

			- Port ID: `UART1`
			- Input Protocol: NMEA & RTCM3
			- Input Protocol: NMEA & RTCM3

		Configure the configuration on UART1:
		```
		$PQTMCFGRCVRMODE,W,2*29
		```

		If there are no errors, users will receive the following response:
		```
		$PQTMCFGRCVRMODE,OK*64
		```

	??? example "Retrieve the Settings"
		!!! abstract inline end "Example Settings"

			- Port ID: `UART1`
			- Input Protocol: NMEA & RTCM3
			- Input Protocol: NMEA & RTCM3

		Get the configuration on UART1:
		```
		$PQTMCFGRCVRMODE,R*32
		```

		If there are no errors, users will receive the following response:
		```
		$PQTMCFGRCVRMODE,OK,2*7A
		```

#### `PQTMCFGRTK`
:   Configures the operation settings of the RTK mode

	```
	$PQTMCFGRTK,W,<DiffMode>,<RelMode>*<Checksum><CR><LF>
	```

	**Parameters:**

	<table markdown>
	<tr markdown>
	<th>Field</th>
	<td markdown>`<DiffMode>`</td>
	<td markdown>`<RelMode>`</td>
	</tr>
	<tr markdown>
	<th>Description</th>
	<td markdown>
	**Differential Mode**
	<ul markdown>
	<li markdown>`0` = Disable RTK/RTD feature *(Differential data is not used)*</li>
	<li markdown>**`1` = Auto mode**</li>
	<li markdown>`2` = RTD only mode *(Only pseudoranges is used)*</li>
	</ul>
	</td>
	<td markdown>
	**Absolute/Relative Mode**
	<ul markdown>
	<li markdown>**`1` = Absolute mode, ensure absolute position accuracy**</li>
	<li markdown>`2` = Relative mode, ensure relative position accuracy</li>
	</ul>
	This field only takes effect when `<DiffMode>` = `1` and the module enters the RTK only mode.
	</td>
	</tr>
	</table>

	??? example "Configure the Settings"
		!!! abstract inline end "Example Settings"

			- Port ID: `UART1`
			- Input Protocol: NMEA & RTCM3
			- Input Protocol: NMEA & RTCM3

		Configure the configuration on UART1:
		```
		$PQTMCFGRTK,W,1,1*6C
		```

		If there are no errors, users will receive the following response:
		```
		$PQTMCFGRTK,OK*3F
		```

	??? example "Retrieve the Settings"
		!!! abstract inline end "Example Settings"

			- Port ID: `UART1`
			- Input Protocol: NMEA & RTCM3
			- Input Protocol: NMEA & RTCM3

		Get the configuration on UART1:
		```
		$PQTMCFGRTK,R*69
		```

		If there are no errors, users will receive the following response:
		```
		$PQTMCFGRTK,OK,1,1*3F
		```

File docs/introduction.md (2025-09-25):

---
icon: material/book-open-page-variant
---

# Introduction
<div class="grid cards desc" markdown>

-   <a href="https://www.sparkfun.com/sparkfun-quadband-gnss-rtk-breakout-lg290p-qwiic.html">
	**SparkFun Quadband GNSS RTK Breakout - LG290P (Qwiic)**<br>
	**SKU:** GPS-26620

	---

	<figure markdown>
	Product Thumbnail
	</figure></a>

	<article class="video-500px" style="text-align: center; margin: auto;" markdown>
	<iframe src="https://www.youtube.com/embed/a-aU4-Yodzg" title="Product Showcase Video" frameborder="0" allow="accelerometer; autoplay; clipboard-write; encrypted-media; gyroscope; picture-in-picture" allowfullscreen></iframe>
	QR code to product video
	</article>

-	The SparkFun Quadband GNSS RTK Breakout - LG290P (Qwiic) features the Quectel LG290P GNSS module. The board's dimensions, pin layout, and connectors are exactly the same as our very popular [SparkFun GPS-RTK-SMA Breakout - ZED-F9P (Qwiic)](https://www.sparkfun.com/sparkfun-gps-rtk-sma-breakout-zed-f9p-qwiic.html); and can be used as a drop-in replacement. The board also accommodates users with a diverse choice of interfaces including UART, SPI[^1], and I^2^C[^1].

	The LG290P module is a quad-band, multi-constellation, high-precision, RTK GNSS receiver. The module is capable of simultaneously receiving signals from the `L1`, `L2`, `L5`, and `L6`/`E6` frequency bands of the GPS, GLONASS, Galileo, BDS, QZSS, and NavIC GNSS constellations. In addition, the module supports SBAS augmentation systems (WASS, EGNOS, BDSBAS, MSAS, GAGAN, and SDCM), PPP services[^2] (BDS PPP-B2b, QZSS CLAS, MADOCA-PPP, and Galileo HAS), and RTK corrections for precision navigation with a fast convergence time and reliable performance.

	The built-in NIC anti-jamming unit provides professional-grade interference signal detection and elimination algorithms, which effectively mitigate against multiple narrow-band interference sources and significantly improves the signal reception performance in complex electromagnetic environments. Additionally, the embedded algorithms ensure reliable positioning in complex scenarios such as urban environments and deep tree cover.

	With its performance advantages of high-precision and low power consumption, this board is an ideal choice for high-precision navigation applications, such as intelligent robots, UAVs, precision agriculture, mining, surveying, and autonomous navigation.

	<article style="text-align: center;" markdown>
	QR code to product page [Purchase from SparkFun :fontawesome-solid-cart-plus:{ .heart }](https://www.sparkfun.com/sparkfun-quadband-gnss-rtk-breakout-lg290p-qwiic.html){ .md-button .md-button--primary }
	</article>

</div>

!!! warning "Features Under Development"
	- **I^2^C/SPI** - Currently, only the UART interface is supported by the module.
	- **PPP Services** - Corrections for some of the PPP services have not been implemented.

[^1]:
	!!! warning "Feature Under Development"
		**I^2^C/SPI** - Currently, only the UART interface is supported by the module.

[^2]:
	!!! warning "Feature Under Development"
		Corrections for some of the PPP services have not been implemented.

## :fontawesome-solid-list-check:&nbsp;Required Materials
To get started, users will need a few items. Some users may already have a few of these items, feel free to adjust accordingly.

<div class="annotate" markdown>

- Computer with an operating system (OS) that is compatible with all the software installation requirements
- [USB 3.1 Cable A to C - 3 Foot](https://www.sparkfun.com/usb-3-1-cable-a-to-c-3-foot.html) - Used to interface with the SparkFun Quadband GNSS RTK Breakout - LG290P (Qwiic) (1)
- [SparkFun Quadband GNSS RTK Breakout - LG290P (Qwiic)](https://www.sparkfun.com/sparkfun-quadband-gnss-rtk-breakout-lg290p-qwiic.html)
- [GNSS Multi-Band L1/L2/L5 Surveying Antenna](https://www.sparkfun.com/gnss-multi-band-l1-l2-l5-surveying-antenna-tnc-spk6618h.html)
	- [SMA Male to TNC Male Cable](https://www.sparkfun.com/reinforced-interface-cable-sma-male-to-tnc-male-10m.html)
	- [Antenna Mount](https://www.sparkfun.com/gnss-magnetic-antenna-mount-5-8-11-tpi.html)

</div>

1. If your computer doesn't have a USB-A slot, then choose an appropriate cable or adapter.

<div class="grid cards products" markdown>

-   <a href="https://www.sparkfun.com/usb-3-1-cable-a-to-c-3-foot.html">
	<figure markdown>
	USB 3.1 Cable A to C - 3 Foot
	</figure>

	---

	**USB 3.1 Cable A to C - 3 Foot**<br>
	CAB-14743</a>

-   <a href="https://www.sparkfun.com/sparkfun-quadband-gnss-rtk-breakout-lg290p-qwiic.html">
	<figure markdown>
	Product Thumbnail
	</figure>

	---

	**SparkFun Quadband GNSS RTK Breakout - LG290P (Qwiic)**<br>
	GPS-26620</a>

-   <a href="https://www.sparkfun.com/gnss-multi-band-l1-l2-l5-surveying-antenna-tnc-spk6618h.html">
	<figure markdown>
	Product Thumbnail
	</figure>

	---

	**GNSS Multi-Band L1/L2/L5 Surveying Antenna - TNC (SPK6618H)**<br>
	GPS-21801</a>

-   <a href="https://www.sparkfun.com/reinforced-interface-cable-sma-male-to-tnc-male-10m.html">
	<figure markdown>
	Product Thumbnail
	</figure>

	---

	**Reinforced Interface Cable - SMA Male to TNC Male (10m)**<br>
	CAB-21740</a>

-   <a href="https://www.sparkfun.com/gnss-magnetic-antenna-mount-5-8-11-tpi.html">
	<figure markdown>
	Product Thumbnail
	</figure>

	---

	**GNSS Magnetic Antenna Mount - 5/8" 11-TPI**<br>
	PRT-21257</a>

</div>

???+ note "GNSS Antennas & Accessories"
	For the best performance, we recommend users choose an **active**, multi-band GNSS antenna and utilize a low-loss cable. For additional options, please check out the [GPS Antenna](https://www.sparkfun.com/categories/18) category of our product catalog.

	=== "GNSS Antennas"

		<div class="grid cards" markdown>

		-   <a href="https://www.sparkfun.com/gnss-multi-band-l1-l2-l5-surveying-antenna-tnc-spk6618h.html">
			<figure markdown>
			Product Thumbnail
			</figure>

			---

			**GNSS Multi-Band L1/L2/L5 Surveying Antenna - TNC (SPK6618H)**<br>
			GPS-21801</a>

		-   <a href="https://www.sparkfun.com/gnss-multi-band-l1-l2-l5-helical-antenna-sma.html">
			<figure markdown>
			Product Thumbnail
			</figure>

			---

			**GNSS Multi-Band L1/L2/L5 Helical Antenna (SMA)**<br>
			GPS-23847</a>

		-   <a href="https://www.sparkfun.com/gnss-multi-band-l1-l2-l5-helical-antenna-sma-bt-t009.html">
			<figure markdown>
			Product Thumbnail
			</figure>

			---

			**GNSS Multi-Band L1/L2/L5 Helical Antenna - SMA (BT-T009)**<br>
			GPS-23848</a>

		-   <a href="https://www.sparkfun.com/magmax2-active-multiband-gnss-magnetic-mount-antenna-aa-200.html">
			<figure markdown>
			Product Thumbnail
			</figure>

			---

			**MagmaX2 Active Multiband GNSS Magnetic Mount Antenna - AA.200**<br>
			GPS-17108</a>

		</div>

	=== "Coaxial Cables"

		<div class="grid cards" markdown>

		-   <a href="https://www.sparkfun.com/interface-cable-sma-female-to-sma-male-10m-rg58.html">
			<figure markdown>
			Product Thumbnail
			</figure>

			---

			**Interface Cable - SMA Female to SMA Male (10m, RG58)**<br>
			CAB-21281</a>

		-   <a href="https://www.sparkfun.com/reinforced-interface-cable-sma-male-to-tnc-male-10m.html">
			<figure markdown>
			Product Thumbnail
			</figure>

			---

			**Reinforced Interface Cable - SMA Male to TNC Male (10m)**<br>
			CAB-21740</a>

		-   <a href="https://www.sparkfun.com/reinforced-interface-cable-sma-male-to-tnc-male-300mm.html">
			<figure markdown>
			Product Thumbnail
			</figure>

			---

			**Reinforced Interface Cable - SMA Male to TNC Male (300mm)**<br>
			CAB-21739</a>

		</div>

	=== "Mounting Hardware"

		<div class="grid cards" markdown>

		-   <a href="https://www.sparkfun.com/gnss-magnetic-antenna-mount-5-8-11-tpi.html">
			<figure markdown>
			Product Thumbnail
			</figure>

			---

			**GNSS Magnetic Antenna Mount - 5/8" 11-TPI**<br>
			PRT-21257</a>

		-   <a href="https://www.sparkfun.com/magnetic-mount-sma-2m.html">
			<figure markdown>
			Product Thumbnail
			</figure>

			---

			**Magnetic Mount SMA - 2m**<br>
			GPS-19576</a>

		-   <a href="https://www.sparkfun.com/gps-antenna-ground-plate.html">
			<figure markdown>
			Product Thumbnail
			</figure>

			---

			**GPS Antenna Ground Plate**<br>
			GPS-17519</a>

		-   <a href="https://www.sparkfun.com/gnss-antenna-mounting-hardware-kit.html">
			<figure markdown>
			Product Thumbnail
			</figure>

			---

			**GNSS Antenna Mounting Hardware Kit**<br>
			KIT-22197</a>

		-   <a href="https://www.sparkfun.com/antenna-thread-adapter-1-4in-to-5-8in.html">
			<figure markdown>
			Product Thumbnail
			</figure>

			---

			**Antenna Thread Adapter - 1/4in. to 5/8in.**<br>
			PRT-17546</a>

		-   <a href="https://www.sparkfun.com/telescopic-surveying-pole.html">
			<figure markdown>
			Product Thumbnail
			</figure>

			---

			**Telescopic Surveying Pole**<br>
			GPS-25795</a>

		</div>

???+ note "Serial Transceivers, UART Adapters, and USB Cables"
	To configure the UART ports that are broken out on the board, users will need a [UART adapter](https://www.sparkfun.com/categories/349). Once configured, the UART ports can utilize one of our RF transceivers to send/receive RTCM messages.

	=== "Transceivers"

		<div class="grid cards" markdown>

		-   <a href="https://www.sparkfun.com/sparkfun-bluesmirf-v2-headers.html">
			<figure markdown>
			Product Thumbnail
			</figure>

			---

			**SparkFun BlueSMiRF v2 - Headers**<br>
			WRL-23287</a>

		-   <a href="https://www.sparkfun.com/sparkfun-bluesmirf-v2.html">
			<figure markdown>
			Product Thumbnail
			</figure>

			---

			**SparkFun BlueSMiRF v2**<br>
			WRL-24113</a>

		-   <a href="https://www.sparkfun.com/sik-telemetry-radio-v3-915mhz-100mw.html">
			<figure markdown>
			Product Thumbnail
			</figure>

			---

			**SiK Telemetry Radio V3 - 915MHz, 100mW**<br>
			WRL-19032</a>

		-   <a href="https://www.sparkfun.com/sparkfun-loraserial-kit-915mhz-enclosed.html">
			<figure markdown>
			Product Thumbnail
			</figure>

			---

			**SparkFun LoRaSerial Kit - 915MHz (Enclosed)**<br>
			WRL-20029</a>

		-   <a href="https://www.sparkfun.com/jst-ghr-04v-to-jst-ghr-06v-cable-1-25mm-pitch.html">
			<figure markdown>
			Product Thumbnail
			</figure>

			---

			**JST-GHR-04V to JST-GHR-06V Cable - 1.25mm pitch**<br>
			CAB-17239</a>

		-   <a href="https://www.sparkfun.com/ghr-04v-s-to-ghr-06v-s-cable-100mm.html">
			<figure markdown>
			Product Thumbnail
			</figure>

			---

			**GHR-04V-S to GHR-06V-S Cable - 100mm**<br>
			CAB-17854</a>

		-   <a href="https://www.sparkfun.com/breadboard-to-jst-ghr-06v-cable-6-pin-x-1-25mm-pitch-for-loraserial.html">
			<figure markdown>
			Product Thumbnail
			</figure>

			---

			**Breadboard to JST-GHR-06V Cable - 6-Pin x 1.25mm Pitch (For LoRaSerial)**<br>
			CAB-23353</a>

		-   <a href="https://www.sparkfun.com/breadboard-to-jst-ghr-06v-cable-6-pin-x-1-25mm-pitch.html">
			<figure markdown>
			Product Thumbnail
			</figure>

			---

			**Breadboard to JST-GHR-06V Cable - 6-Pin x 1.25mm Pitch**<br>
			CAB-18079</a>

		-   <a href="https://www.sparkfun.com/breadboard-to-jst-ghr-04v-cable-4-pin-x-1-25mm-pitch.html">
			<figure markdown>
			Product Thumbnail
			</figure>

			---

			**Breadboard to JST-GHR-04V Cable - 4-Pin x 1.25mm Pitch**<br>
			CAB-17240</a>

		</div>

	=== "UART Adapters"

		<div class="grid cards" markdown>

		-   <a href="https://www.sparkfun.com/sparkfun-serial-basic-breakout-ch340c-and-usb-c.html">
			<figure markdown>
			Product Thumbnail
			</figure>

			---

			**SparkFun Serial Basic Breakout - CH340C and USB-C**<br>
			DEV-15096</a>

		-   <a href="https://www.sparkfun.com/sparkfun-serial-basic-breakout-ch340g.html">
			<figure markdown>
			Product Thumbnail
			</figure>

			---

			**SparkFun Serial Basic Breakout - CH340G**<br>
			DEV-14050</a>

		-   <a href="https://www.sparkfun.com/sparkfun-ftdi-basic-breakout-3-3v.html">
			<figure markdown>
			Product Thumbnail
			</figure>

			---

			**SparkFun FTDI Basic Breakout - 3.3V**<br>
			DEV-09873</a>

		-   <a href="https://www.sparkfun.com/sparkfun-ftdi-starter-kit-3-3v.html">
			<figure markdown>
			Product Thumbnail
			</figure>

			---

			**SparkFun FTDI Starter Kit - 3.3V**<br>
			KIT-18289</a>

		-   <a href="https://www.sparkfun.com/sparkfun-ft231x-breakout.html">
			<figure markdown>
			Product Thumbnail
			</figure>

			---

			**SparkFun FT231X Breakout**<br>
			BOB-13263</a>

		</div>

	=== "USB Cables"

		<div class="grid cards" markdown>

		-   <a href="https://www.sparkfun.com/usb-c-to-usb-c-silicone-power-charging-cable-3m.html">
			<figure markdown>
			Product Thumbnail
			</figure>

			---

			**USB-C to USB-C Silicone Power Charging Cable - 3m**<br>
			CAB-24060</a>

		-   <a href="https://www.sparkfun.com/usb-3-1-cable-a-to-c-3-foot.html">
			<figure markdown>
			Product Thumbnail
			</figure>

			---

			**USB 3.1 Cable A to C - 3 Foot**<br>
			CAB-14743</a>

		-   <a href="https://www.sparkfun.com/sparkfun-4-in-1-multi-usb-cable-usb-c-host.html">
			<figure markdown>
			Product Thumbnail
			</figure>

			---

			**SparkFun 4-in-1 Multi-USB Cable - USB-C Host**<br>
			CAB-21271</a>

		-   <a href="https://www.sparkfun.com/sparkfun-4-in-1-multi-usb-cable-usb-a-host.html">
			<figure markdown>
			Product Thumbnail
			</figure>

			---

			**SparkFun 4-in-1 Multi-USB Cable - USB-A Host**<br>
			CAB-21272</a>

		</div>

??? note "Headers and Wiring"
	To add headers or wiring, users will need [soldering equipment](https://www.sparkfun.com/categories/49) and [headers](https://www.sparkfun.com/categories/381)/[wires](https://www.sparkfun.com/search/results?term=hook-up+wire).

	!!! tip "New to soldering?"
		Check out our [How to Solder: Through-Hole Soldering](https://learn.sparkfun.com/tutorials/5) tutorial for a quick introduction!

		<div class="grid cards" markdown align="center">

		-   <a href="https://learn.sparkfun.com/tutorials/5">
			<figure markdown>
			Tutorial Thumbnail
			</figure>

			---

			**How to Solder: Through-Hole Soldering**</a>

		</div>

	<div class="grid cards" markdown>

	-   <a href="https://www.sparkfun.com/solder-lead-free-100-gram-spool.html">
		<figure markdown>
		Product Thumbnail
		</figure>

		---

		**Solder Lead Free - 100-gram Spool**<br>
		TOL-09325</a>

	-   <a href="https://www.sparkfun.com/pinecil-soldering-iron-kit.html">
		<figure markdown>
		Product Thumbnail
		</figure>

		---

		**PINECIL Soldering Iron Kit**<br>
		KIT-24063</a>

	-   <a href="https://www.sparkfun.com/straight-header-male-pth-0-1in-40-pin.html">
		<figure markdown>
		Product Thumbnail
		</figure>

		---

		**Break Away Headers - Straight**<br>
		PRT-00116</a>

	-   <a href="https://www.sparkfun.com/right-angle-header-male-pth-0-1in-40-pin.html">
		<figure markdown>
		Product Thumbnail
		</figure>

		---

		**Break Away Male Headers - Right Angle**<br>
		PRT-00553</a>

	-   <a href="https://www.sparkfun.com/right-angle-header-female-smd-0-1in-6-pin.html">
		<figure markdown>
		Product Thumbnail
		</figure>

		---

		**Header - 6-pin Female (SMD, 0.1", Right Angle)**<br>
		PRT-12590</a>

	-   <a href="https://www.sparkfun.com/hook-up-wire-assortment-stranded-22-awg.html">
		<figure markdown>
		Product Thumbnail
		</figure>

		---

		**Hook-Up Wire - Assortment (Stranded, 22 AWG)**<br>
		PRT-11375</a>

	</div>

??? note "Qwiic Devices and Cables"
	Our Qwiic connect system is a simple solution for daisy chaining I^2^C devices without the hassle of soldering or checking wire connections. Check out other [Qwiic devices](https://www.sparkfun.com/categories/399) from our catalog.

	<div class="grid cards" markdown>

	-   <a href="https://www.sparkfun.com/sparkfun-qwiic-cable-kit.html">
		<figure markdown>
		Product Thumbnail
		</figure>

		---

		**SparkFun Qwiic Cable Kit**<br>
		KIT-15081</a>

	-   <a href="https://www.sparkfun.com/qwiic-cable-grove-adapter-100mm.html">
		<figure markdown>
		Product Thumbnail
		</figure>

		---

		**Qwiic Cable - Grove Adapter (100mm)**<br>
		PRT-15109</a>

	-   <a href="https://www.sparkfun.com/sparkfun-qwiic-oled-1-3in-128x64.html">
		<figure markdown>
		Product Thumbnail
		</figure>

		---

		**SparkFun Qwiic OLED - (1.3in., 128x64)**<br>
		LCD-23453</a>

	-   <a href="https://www.sparkfun.com/sparkfun-qwiic-mux-breakout-8-channel-tca9548a.html">
		<figure markdown>
		Product Thumbnail
		</figure>

		---

		**SparkFun Qwiic Mux Breakout - 8 Channel (TCA9548A)**<br>
		BOB-16784</a>

	</div>

	!!! tip "What is Qwiic?"

		<div class="grid" markdown>

		<div markdown>

		<!-- Qwiic Banner -->
		<article style="text-align: center;" markdown>
		Qwiic Logo - light theme (https://www.sparkfun.com/qwiic)
		Qwiic Logo - dark theme (https://www.sparkfun.com/qwiic)
		</article>

		---

		The [Qwiic connect system](https://www.sparkfun.com/qwiic) is a solderless, polarized connection system that allows users to seamlessly daisy chain I^2^C boards together. Play the video, to learn more about the Qwiic connect system or click on the banner above to learn more about [Qwiic products](https://www.sparkfun.com/qwiic).

		</div>

		<div style="max-height=400px;" markdown>

		<article class="video-500px" style="text-align: center; margin: auto;" markdown>
		<iframe src="https://www.youtube.com/embed/x0RDEHqFIF8" title="SparkFun's Qwiic Connect System" frameborder="0" allow="accelerometer; encrypted-media; gyroscope; picture-in-picture" allowfullscreen></iframe>
		QR code to instructional video
		</article>

		</div>

		</div>

		!!! info "Features of the Qwiic System"

			=== "No Soldering"

				no soldering - light theme
				no soldering - dark theme

				Qwiic cables (4-pin JST) plug easily from development boards to sensors, shields, accessory boards and more, making easy work of setting up a new prototype.

			=== "Polarized Connector"

				polarized connector - light theme
				polarized connector - dark theme

				There's no need to worry about accidentally swapping the `SDA` and `SCL` wires on your breadboard. The Qwiic connector is polarized so you know you’ll have it wired correctly every time.

				The part numbers for the PCB connector is `SM04B-SRSS` ([Datasheet](https://cdn.sparkfun.com/assets/parts/1/2/2/8/9/Qwiic_Connector_Datasheet.pdf)) and the mating connector on the cables is `SHR04V-S-B`; or an equivalent *1mm pitch, 4-pin JST connection*.

			=== "Daisy Chain-able"

				daisy chainable - light theme
				daisy chainable - dark theme

				It’s time to leverage the power of the I^2^C bus! Most Qwiic boards will have two or more connectors on them, allowing multiple devices to be connected.

??? note "Jumper Modification"
	To modify the [jumpers](../hardware_overview/#jumpers), users will need [soldering equipment](https://www.sparkfun.com/categories/49) and/or a [hobby knife](https://www.sparkfun.com/categories/379).

	!!! tip "New to jumper pads?"
		Check out our [Jumper Pads and PCB Traces Tutorial](https://learn.sparkfun.com/tutorials/664) for a quick introduction!

		<div class="grid cards" markdown align="center">

		-   <a href="https://learn.sparkfun.com/tutorials/664">
			<figure markdown>
			Tutorial thumbnail
			</figure>

			---

			**How to Work with Jumper Pads and PCB Traces**</a>

		</div>

	<div class="grid cards" markdown>

	-   <a href="https://www.sparkfun.com/pinecil-soldering-iron-kit.html">
		<figure markdown>
		Product Thumbnail
		</figure>

		---

		**PINECIL Soldering Iron Kit**<br>
		KIT-24063</a>

	-   <a href="https://www.sparkfun.com/hobby-knife.html">
		<figure markdown>
		Product Thumbnail
		</figure>

		---

		**Hobby Knife**<br>
		TOL-09200</a>

	-   <a href="https://www.sparkfun.com/2-4ghz-duck-antenna-rp-sma.html79">
		<figure markdown>
		Product Thumbnail
		</figure>

		---

		**Chip Quik No-Clean Flux Pen - 10mL**<br>
		TOL-14579</a>

	-   <a href="https://www.sparkfun.com/solder-wick-2-5ft-generic.html">
		<figure markdown>
		Product Thumbnail
		</figure>

		---

		**Solder Wick #2 5ft. - Generic**<br>
		TOL-09327</a>

	</div>
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

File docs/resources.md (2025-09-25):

---
icon: material/book-open-page-variant
---

## Product Resources

- :sfe-logo: [Product Page](https://www.sparkfun.com/sparkfun-quadband-gnss-rtk-breakout-lg290p-qwiic.html)
- :material-folder-cog: Design Files:
	- :fontawesome-solid-file-pdf: [Schematic](./assets/board_files/schematic.pdf)
	- :fontawesome-solid-file-pdf: [Board Dimensions](./assets/board_files/dimensions.pdf)
	- :material-folder-zip: [KiCad Files](./assets/board_files/kicad_files.zip)
	- :material-cube-outline: [STEP File](./assets/3d_model/cad_model.step)
- :fontawesome-solid-computer: [QGNSS Software *(v2.x)*](https://www.quectel.com/download/qgnss_v2-0_en/)
- Component Documentation
	- :fontawesome-solid-file-pdf: [Product Specifications](./assets/component_documentation/Quectel_LG290P03_GNSS_Module_Specification_V1.2.pdf)
	- :fontawesome-solid-file-pdf: [Protocol Specification](./assets/component_documentation/quectel_lg290p03lgx80p03_gnss_protocol_specification_v1-1.pdf)
	- :fontawesome-solid-file-pdf: [Hardware Design](./assets/component_documentation/quectel_lg290p03_hardware_design_v1-1.pdf)
	- :fontawesome-solid-file-pdf: [Application Note - RTK Corrections](./assets/component_documentation/quectel_lg290p03lgx80p03_rtk_application_note_v1-1.pdf)
	- :fontawesome-solid-file-pdf: [Application Note - Base Station](./assets/component_documentation/quectel_lg290p03lgx80p_series_base_station_mode_application_note_v1-1.pdf)
	- :fontawesome-solid-file-pdf: [Firmware Upgrade Guide](./assets/component_documentation/quectel_lg290p03lgx80p03_firmware_upgrade_guide_v1-1.pdf)
	- :fontawesome-solid-file-pdf: [CH342 Datasheet](./assets/component_documentation/CH342%20Datasheet.pdf)
	- :fontawesome-solid-file-pdf: [RT9080 Datasheet](./assets/component_documentation/DS9080.pdf)
	- :fontawesome-solid-file-pdf: [JST-GH Connector Specifications](./assets/component_documentation/JST-GH_datasheet.pdf)
	- :fontawesome-solid-file-pdf: [JST-SH Connector Specifications](./assets/component_documentation/JST-SH_datasheet.pdf)
- :material-github: [Hardware Repository](https://github.com/sparkfun/SparkFun_LG290P_Quadband_GNSS_RTK_Breakout)
- :material-youtube: [SFE Product Showcase](https://www.youtube.com/watch?v=a-aU4-Yodzg)

### :sfe-logo: Additional Resources

- [Qwiic Information Page](https://www.sparkfun.com/qwiic)
- :material-account-supervisor: [SparkFun Technical Assistance](https://www.sparkfun.com/technical_assistance)

### 🏭&nbsp;Manufacturer's Resources
Quectel also provides great resources for the LG290P GNSS module:

- :material-web: [Product Webpage](https://www.quectel.com/product/gnss-lg290p/)
- :material-help-box: [Quectel Forum](https://forums.quectel.com/)
- :material-account-supervisor: [Technical Support](https://www.quectel.com/tech-support/)
- :material-cloud-download: [Download Zone](https://www.quectel.com/download-zone/?_sft_product_cat=gnss-modules-standalone)
- :material-newspaper-variant: [Resource Library](https://www.quectel.com/library?_sft_topic=gnss)

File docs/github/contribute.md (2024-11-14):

# Contribute: Make an Augmentation!
Spot an improvement opportunity? Feel free to contribute to our open-source design and documentation. 

## :material-file-document-multiple:&nbsp;Improve our Documentation
All of this documentation can be modified by you! Please help us make it better.

- These pages are contained in the [`docs` folder](https://github.com/sparkfun/SparkFun_LG290P_Quadband_GNSS_RTK_Breakout/tree/main/docs) of the [SparkFun LG290P Quadband GNSS RTK Breakout repository](https://github.com/sparkfun/SparkFun_LG290P_Quadband_GNSS_RTK_Breakout).

<!-- ### :material-source-pull:&nbsp;Submit a Correction -->
### Submit a Correction

1. With a GitHub account, [fork this repository](https://github.com/sparkfun/SparkFun_LG290P_Quadband_GNSS_RTK_Breakout/fork).
2. Add your corrections or improvements to the markdown file.
3. File a pull request with your changes, and enjoy making the ~~words~~ ~~worlds~~ world a better place.
	- Once received, the documentation specialist will automatically be notified.
	- We will review your suggested improvements to make sure they are correct and fit within our documentation standards.

## :material-cog:&nbsp;Improve our Hardware Design
All of our designs are open-source! Please help us make it better.

- Our board design files are contained in the [`Hardware` folder](https://github.com/sparkfun/SparkFun_LG290P_Quadband_GNSS_RTK_Breakout/tree/main/Hardware) of the [SparkFun LG290P Quadband GNSS RTK Breakout repository](https://github.com/sparkfun/SparkFun_LG290P_Quadband_GNSS_RTK_Breakout).

<!-- ### :material-source-pull:&nbsp;Submit a Design Enhancement -->
### Submit a Design Enhancement

1. With a GitHub account, [fork this repository](https://github.com/sparkfun/SparkFun_LG290P_Quadband_GNSS_RTK_Breakout/fork).
2. Add your design augmentation(s)
3. File a pull request with your changes, and enjoy making the ~~words~~ ~~worlds~~ world a better place.
	1. Once received, the engineer in charge of the original design will automatically be notified.
	2. We will review your suggested improvement(s) to verify that they are within our board design standards and meet our product design requirements.
	3. If approved, we will flag these changes for our next board revision. Congrats! 🍻

		!!! info
			Even if your suggestion is accepted, these changes may not be immediately available for purchase. We may have to cycle through our current product inventory first.
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

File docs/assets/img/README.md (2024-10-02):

img directory
====================
This folder should contain the images for the product documentation

## General Images
- `sfe-logo.png` - SparkFun flame logo (favicon)

## Directory
- `graphical_datasheet` - Files for graphical datasheet
- `hookup_guide` - Images for the hookup guide pages
- `qr_code` - QR code images
- `qwiic` - Images for Qwiic Banner
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

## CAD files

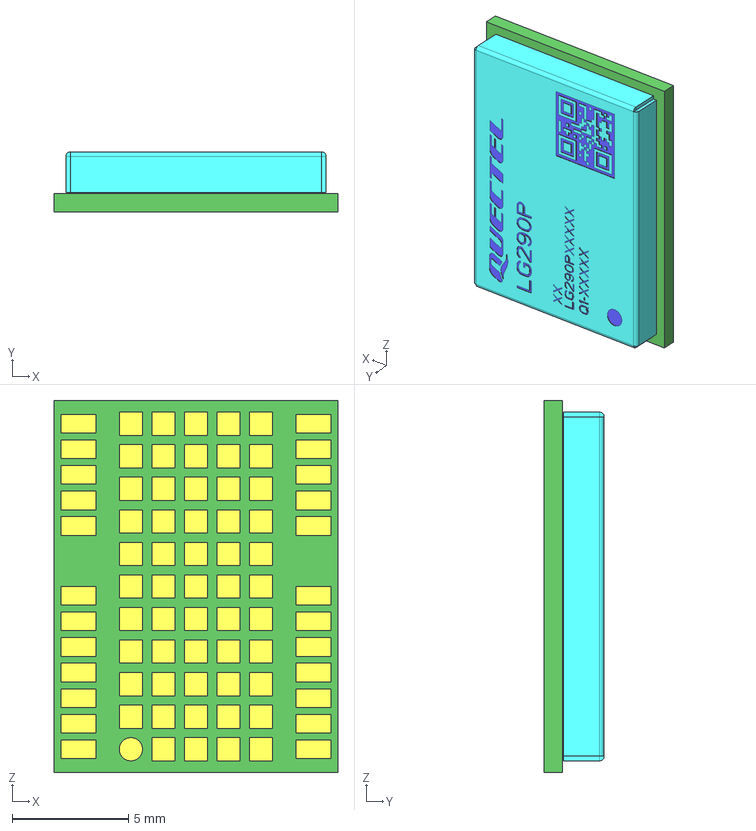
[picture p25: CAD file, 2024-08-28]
docs/assets/component_documentation/Quectel_LG290P_3D_Dimensions_V1.0.stp
12.2 x 2.60 x 16.0 mm
LG290P-PCB
LG290P-COVER

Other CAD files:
Hardware/LG290P.step

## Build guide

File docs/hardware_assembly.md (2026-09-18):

---
icon: material/tools
---

## USB Programming (`UART1`)
The USB connection can be utilized for serial communication and configuring the LG290P GNSS module. Users only need to connect their Quad-band GNSS RTK breakout board to a computer, using a USB-C cable.

<figure markdown>
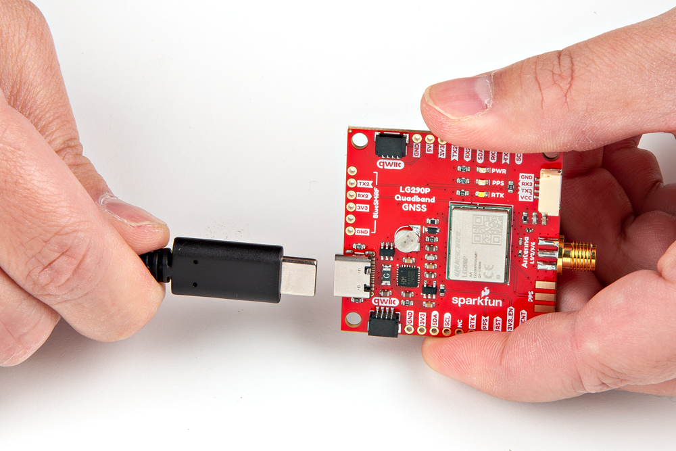
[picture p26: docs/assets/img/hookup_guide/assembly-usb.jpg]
Quad-band GNSS RTK breakout board USB connection

<figcaption markdown>The Quad-band GNSS RTK breakout board with USB-C cable being attached.</figcaption>
</figure>

!!! info "Default Baud Rate"
	The default baud rate of the UART ports on the LG290P is **460800bps**.

## GNSS Antenna
In order to receive [GNSS](https://en.wikipedia.org/wiki/Satellite_navigation "Global Navigation Satellite System") signals, users will need to connect a compatible antenna. For the best performance, we recommend users choose an active, multi-band GNSS antenna and utilize a low-loss cable.

???+ warning "Antenna Specifications"
	- Passive antennas are not recommended for the LG290P GNSS module.
	- To mitigate the impact of out-of-band signals, utilize an active antenna whose SAW filter is placed in front of the LNA in the internal framework.
		- **DO NOT** select and antenna with the LNA placed in the front.
	- There is no need to inject an external DC voltage into the SMA connector for the GNSS antenna. Power is already provided from the LG290P module for the LNA of an active antenna.

<figure markdown>
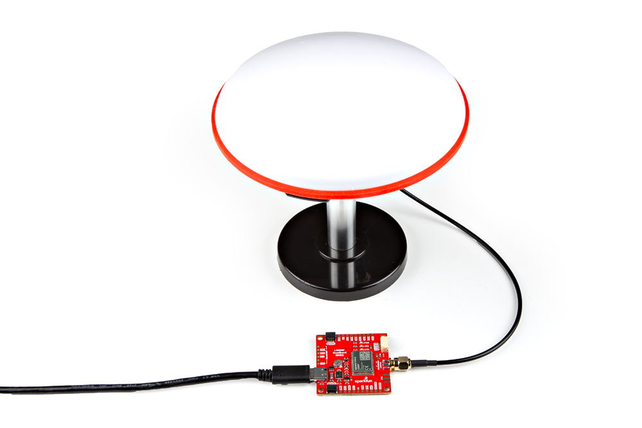
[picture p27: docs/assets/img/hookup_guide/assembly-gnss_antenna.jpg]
Quad-band GNSS RTK breakout board antenna connector

<figcaption markdown>A GNSS antenna attached to the SMA connector on the Quad-band GNSS RTK breakout board.</figcaption>
</figure>

## JST Connector (`UART3`)
The JST connector on the Quad-band GNSS RTK board, breaks out the `UART3` port of the LG290P GNSS module. In certain circumstances, users may need to utilize the JST connector to transmit or receive RTK correction data with one of our radios.

<div class="grid" markdown>

<div markdown>

<figure markdown>
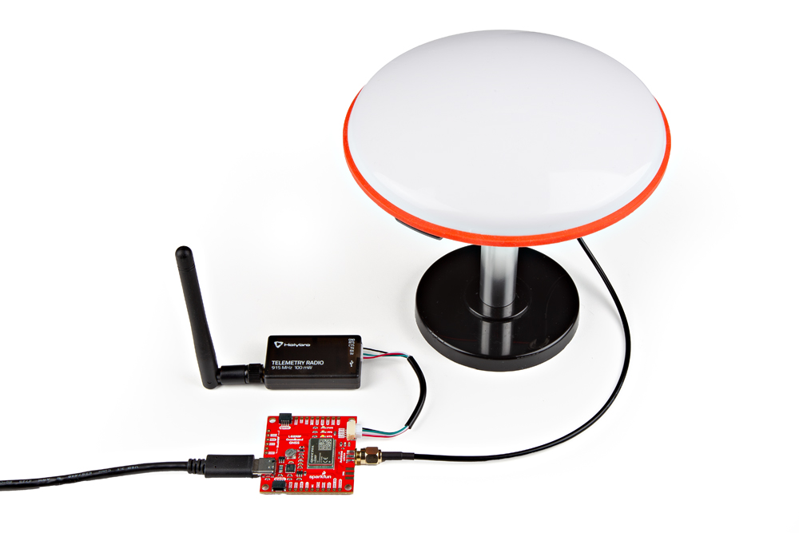
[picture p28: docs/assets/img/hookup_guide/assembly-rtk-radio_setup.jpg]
Device connected to the JST connector

<figcaption markdown>The [Telemetry Radio v3](https://www.sparkfun.com/sik-telemetry-radio-v3-915mhz-100mw.html) connected to the Quad-band GNSS RTK breakout.</figcaption>
</figure>

</div>

<div markdown>

When connecting the Quad-band GNSS RTK breakout board to other products, users should be aware of the pin connections between the devices. The table below, details the pin connections of the locking JST connector on the Quad-band GNSS RTK breakout board.

<article style="text-align: center;" markdown>

<table border="1" markdown>
<tr markdown>
<th style="vertical-align:middle;">Pin Number</th>
<td align="center" markdown>
	**1**<br>
	*(Left Side)*
</td>
<th align="center">2</td>
<th align="center">3</td>
<th align="center">4</td>
</tr>
<tr>
<th>Label</th>
<td align="center">VCC</td>
<td align="center">TX3</td>
<td align="center">RX3</td>
<td align="center">GND</td>
</tr>
<tr markdown>
<th style="vertical-align:middle;">Function</th>
<td markdown>
	<u>**Voltage Output**</u><br>
	- **Default: 3.3V**<br>
	- 3.3V or 5V
</td>
<td align="center" style="vertical-align:middle;" markdown>`UART3` - Receive</td>
<td align="center" style="vertical-align:middle;" markdown>`UART3` - Transmit</td>
<td align="center" style="vertical-align:middle;">Ground</td>
</tr>
</table>

</article>

</div>

</div>

!!! info "Default Baud Rate"
	The default baud rate of the UART ports on the LG290P is **460800bps**.

### Radio Transceivers
We have designed the locking JST connector to be plug-n-play with the following devices and cables. However, for the [SiK Telemetry Radio v3](https://www.sparkfun.com/sik-telemetry-radio-v3-915mhz-100mw.html), users should [modify the `VSEL` jumper](../hardware_overview/#jumpers) (1) on the back of the board to enable a 5V output on the `VCC` pin. Below, is a table summarizing the pin connections of the radios.
{ .annotate }

1. While the [SiK Telemetry Radio v3](https://www.sparkfun.com/sik-telemetry-radio-v3-915mhz-100mw.html) may function with a **3.3V** input, their specifications stipulate that a **5V** power supply be provided.

<article style="text-align: center;" markdown>

<table border="1" markdown>
<tr markdown>
<th style="vertical-align:middle;">Pin Number</th>
<td align="center" markdown>
	**1**<br>
	*(Left Side)*
</td>
<td align="center" markdown>**2**</td>
<td align="center" markdown>**3**</td>
<td align="center" markdown>**4**</td>
<td align="center" markdown>**5**</td>
<td align="center" markdown>
	**6**<br>
	*(Right)*
</td>
</tr>
<tr>
<th style="vertical-align:middle;">Label</th>
<td align="center" style="vertical-align:middle;">5V</td>
<td>
	RX - SiK<br>
	RXI - LoRaSerial
</td>
<td>
	TX - SiK<br>
	TXO - LoRaSerial
</td>
<td align="center" style="vertical-align:middle;">CTS</td>
<td align="center" style="vertical-align:middle;">RTS</td>
<td align="center" style="vertical-align:middle;">GND</td>
</tr>
<tr markdown>
<th style="vertical-align:middle;">Function</th>
<td markdown>
	<u>**Voltage Input**</u><br>
	- SiK: 5V<br>
	- LoRaSerial: 3.3 to 5V (1)
</td>
<td align="center" style="vertical-align:middle;">UART - Receive</td>
<td align="center" style="vertical-align:middle;">UART - Transmit</td>
<td align="center" style="vertical-align:middle;" markdown>
	Flow Control<br>
	*Clear-to-Send*
</td>
<td align="center" style="vertical-align:middle;" markdown>
	Flow Control<br>
	*Ready-to-Send*
</td>
<td align="center" style="vertical-align:middle;">Ground</td>
</tr>
</table>

</article>

??? tip "Radio Pin Connections"
	<div class="grid" markdown>

	<div markdown>

	As documented in the [LoRaSerial product manual](https://docs.sparkfun.com/SparkFun_LoRaSerial), the pin connections between a host system *(i.e. Quad-band GNSS RTK breakout board)* and the LoRaSerial radio is outlined in the image below.

	<figure markdown>
	UART w/ Flow Control (https://docs.sparkfun.com/SparkFun_LoRaSerial/img/SAMD21%20Flow%20control.png "Click to enlarge")
	<figcaption markdown>The pin connections between a radio and the Quad-band GNSS RTK breakout board.</figcaption>
	</figure>

	</div>

	<div markdown>

	However, the flow control pins *(`CTS` and `RTS`)* are not available on the Quad-band GNSS RTK breakout board. Therefore, when connecting either of the radios, the pin connections should follow the table below:

	<article style="text-align: center;" markdown>

	<table>
	<tr>
	<th>Board</th>
	<td align="center">RX</td>
	<td align="center">TX</td>
	<td align="center">GND</td>
	</tr>
	<tr>
	<th>Radio</th>
	<td align="center">TX</td>
	<td align="center">RX</td>
	<td align="center">GND</td>
	</tr>
	</table>

	</article>

	</div>

	</div>

???+ note "Radio Transceivers and Cables"
	!!! warning "Default Baud Rate"
		The baud rate for these radios are configured by the [`SERIAL_SPEED` parameter](https://docs.sparkfun.com/SparkFun_LoRaSerial/at_commands/#serial-commands). The default configuration is `SERIAL_SPEED`: **57600bps**.

	<div class="grid cards" markdown>

	-   <a href="https://www.sparkfun.com/sik-telemetry-radio-v3-915mhz-100mw.html">
		<figure markdown>
		Product Thumbnail
		</figure>

		---

		**SiK Telemetry Radio V3 - 915MHz, 100mW**<br>
		WRL-19032</a>

	-   <a href="https://www.sparkfun.com/sparkfun-loraserial-kit-915mhz-enclosed.html">
		<figure markdown>
		Product Thumbnail
		</figure>

		---

		**SparkFun LoRaSerial Kit - 915MHz (Enclosed)**<br>
		WRL-20029</a>

	-   <a href="https://www.sparkfun.com/jst-ghr-04v-to-jst-ghr-06v-cable-1-25mm-pitch.html">
		<figure markdown>
		Product Thumbnail
		</figure>

		---

		**JST-GHR-04V to JST-GHR-06V Cable - 1.25mm pitch**<br>
		CAB-17239</a>

	-   <a href="https://www.sparkfun.com/ghr-04v-s-to-ghr-06v-s-cable-100mm.html">
		<figure markdown>
		Product Thumbnail
		</figure>

		---

		**GHR-04V-S to GHR-06V-S Cable - 100mm**<br>
		CAB-17854</a>

	</div>

## Breakout Pins
The [PTH](https://en.wikipedia.org/wiki/Through-hole_technology "Plated Through Holes") pins on the Quad-band GNSS RTK board are broken out into 0.1"-spaced pins on the outer edges of the board.

??? note "New to soldering?"
	If you have never soldered before or need a quick refresher, check out our [How to Solder: Through-Hole Soldering](https://learn.sparkfun.com/tutorials/how-to-solder-through-hole-soldering) guide.

	<div class="grid cards" markdown align="center">

	-   <a href="https://learn.sparkfun.com/tutorials/5">
		<figure markdown>
		Tutorial thumbnail
		</figure>

		---
	
		**How to Solder: Through-Hole Soldering**</a>

	</div>

<div class="grid" markdown>

<div markdown>

=== "Headers"

	When selecting headers, be sure you are aware of the functionality you require.

	<figure markdown>
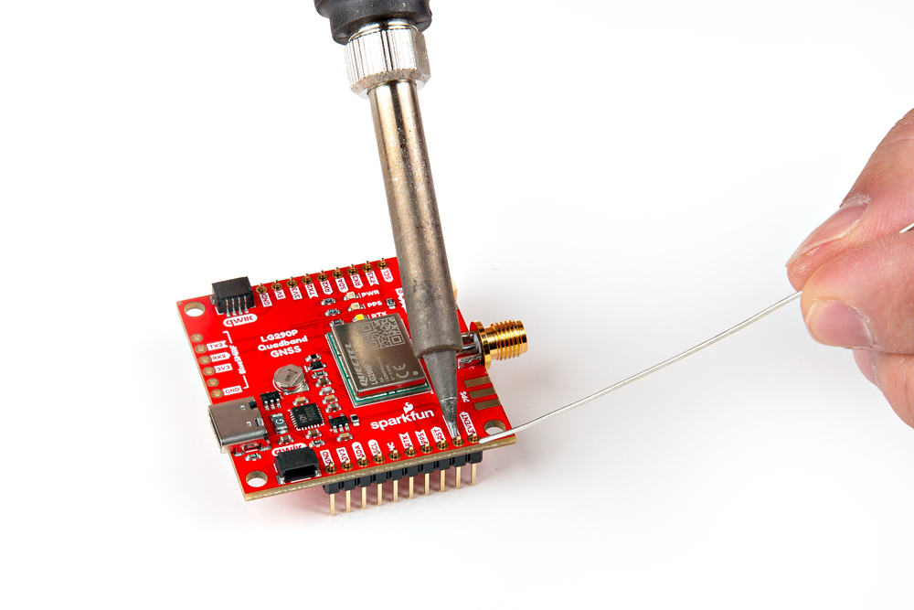
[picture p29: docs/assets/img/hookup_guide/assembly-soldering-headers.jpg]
Soldering headers
	
	<figcaption markdown>Soldering headers to the Quad-band GNSS RTK breakout board.</figcaption>
	</figure>

</div>

<div markdown>

=== "Hookup Wires"

	For a more permanent connection, users can solder wires directly to the board.

	<figure markdown>
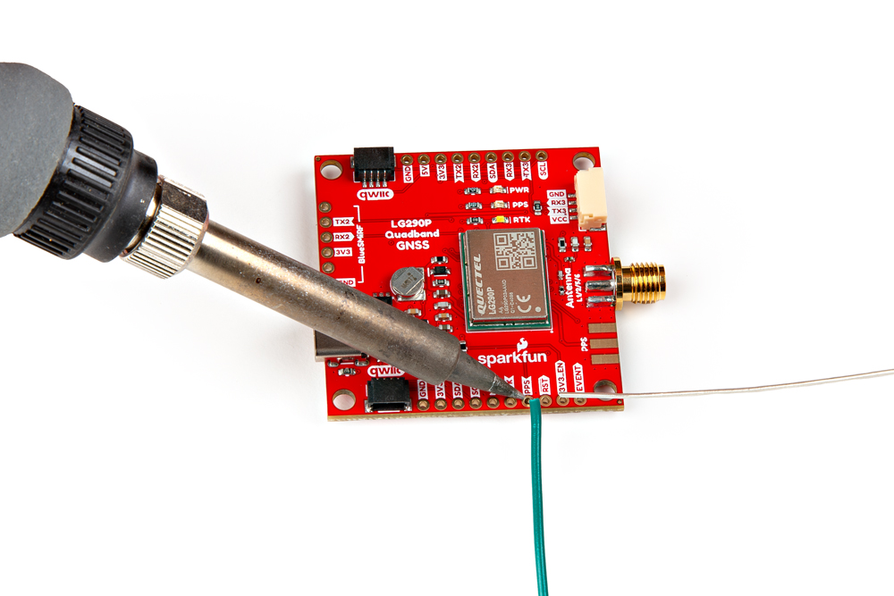
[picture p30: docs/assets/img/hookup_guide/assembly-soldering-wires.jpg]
Soldering wires
	
	<figcaption markdown>Soldering wires to the Quad-band GNSS RTK breakout board.</figcaption>
	</figure>

</div>

</div>

### BlueSMiRF Header (`UART2`)
The BlueSMiRF header pins on the Quad-band GNSS RTK board, breaks out the `UART2` port of the LG290P GNSS module. This pin layout is perfect for connecting a [serial-to-UART adapter](https://www.sparkfun.com/sparkfun-serial-basic-breakout-ch340c-and-usb-c.html) or a transceiver for serial data, such as the [BlueSMiRF Bluetooth&trade; serial-link](https://www.sparkfun.com/sparkfun-bluesmirf-v2-headers.html).

<div class="grid" markdown>

<div markdown>

<figure markdown>
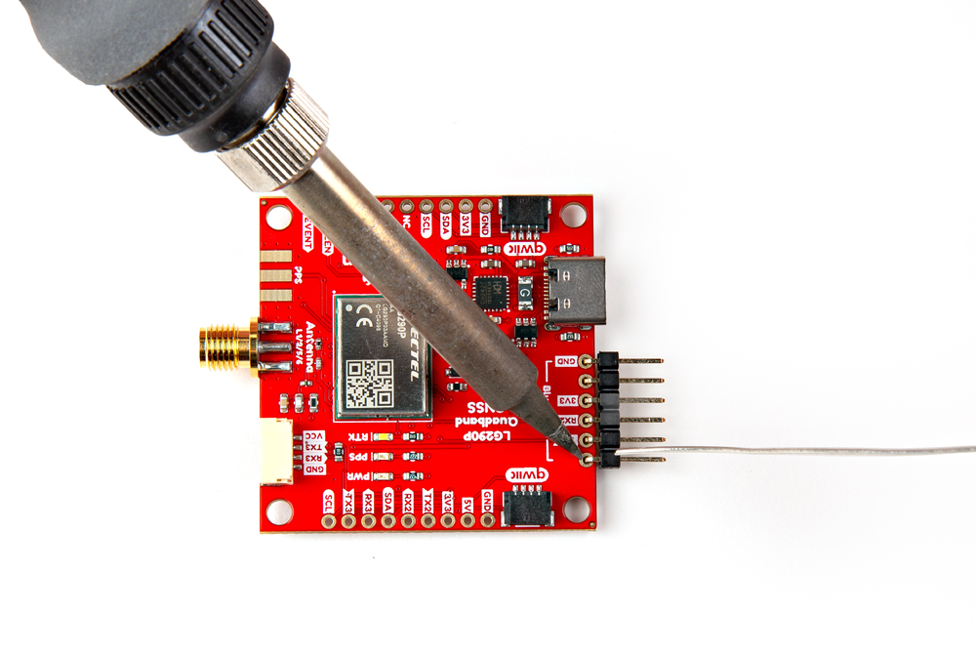
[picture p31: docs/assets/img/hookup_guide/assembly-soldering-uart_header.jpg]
Male Header Attached

<figcaption markdown>Soldering male header pins to the Quad-band GNSS RTK breakout board.</figcaption>
</figure>

</div>

<div markdown>

<figure markdown>
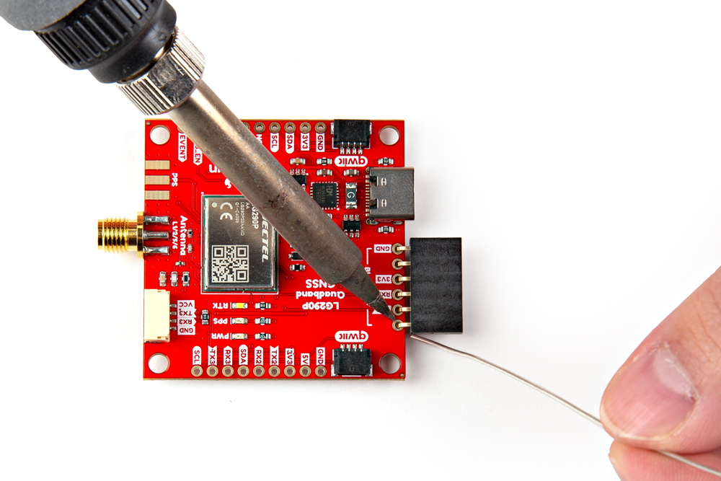
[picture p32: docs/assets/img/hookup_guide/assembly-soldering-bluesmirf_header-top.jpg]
Male Header Attached

<figcaption markdown>Soldering female header pins to the Quad-band GNSS RTK breakout board.</figcaption>
</figure>

</div>

<div markdown>

<figure markdown>
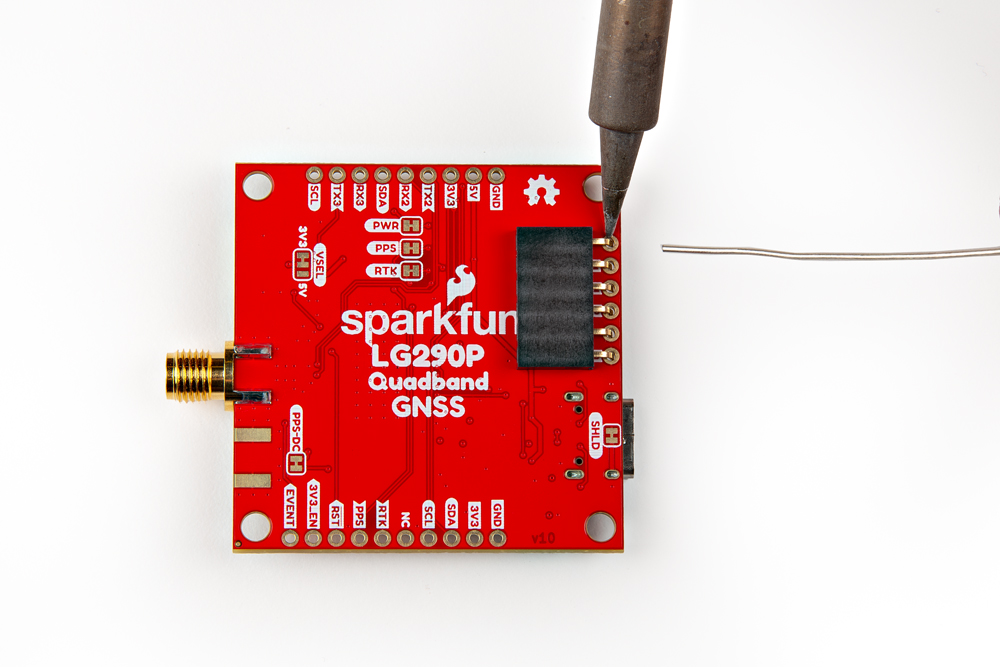
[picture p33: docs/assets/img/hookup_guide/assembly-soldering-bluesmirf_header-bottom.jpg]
Female Header Attached

<figcaption markdown>Soldering female header pins to the back of the Quad-band GNSS RTK breakout board.</figcaption>
</figure>

??? warning "Jumper Access"
	When soldering a header to the back of the board, be aware that you'll loose access to the jumper in that area.

	<figure markdown>
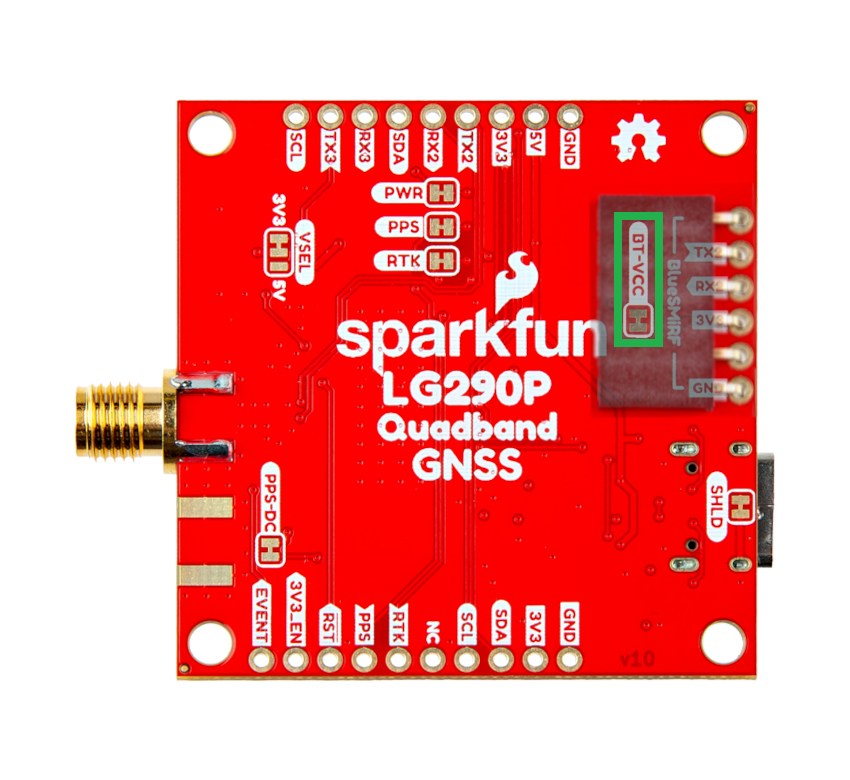
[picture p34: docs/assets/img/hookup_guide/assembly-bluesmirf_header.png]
BlueSMiRF transceiver - top
	
	<figcaption markdown>Female header covering the `BT-VCC` jumper.</figcaption>
	</figure>

</div>

</div>

!!! info "Default Baud Rate"
	The default baud rate of the UART ports on the LG290P is **460800bps**.

=== "BlueSMiRF"
	!!! warning "Default Baud Rate"
		The baud rate for the BlueSMiRF transceiver is configured by the [`SerialSpeed` parameter](https://docs.sparkfun.com/SparkFun_BlueSMiRF-v2/at_commands/#serial-commands). The default configuration is `SerialSpeed`: **115200bps**.

	Connecting a [BlueSMiRF transceiver](https://www.sparkfun.com/sparkfun-bluesmirf-v2-headers.html) to a female header that was soldered to the Quad-band GNSS RTK breakout board. This will allow users to pair their board with a mobile device; and log PNT data on the mobile device and/or connect the LG290P to an NTRIP server for RTK corrections *(through mobile device's cellular or WiFi connection)*.

	<div class="grid" markdown>

	<div markdown>

	<figure markdown>
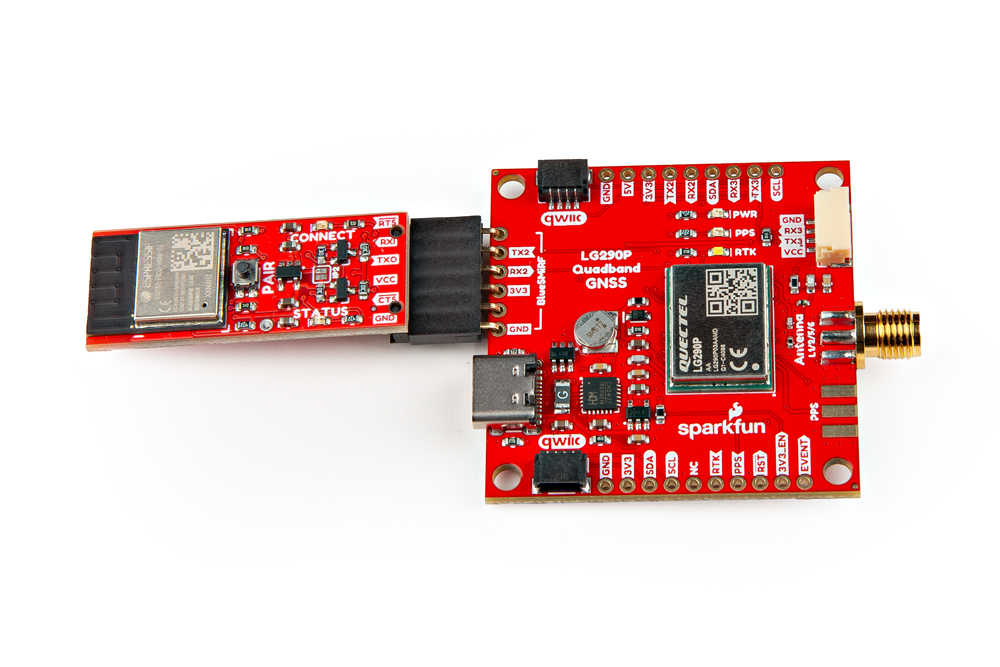
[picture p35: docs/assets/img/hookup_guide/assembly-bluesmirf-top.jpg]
BlueSMiRF transceiver - top
	
	<figcaption markdown>Female header pins soldered to the top of the board.</figcaption>
	</figure>

	</div>

	<div markdown>

	<figure markdown>
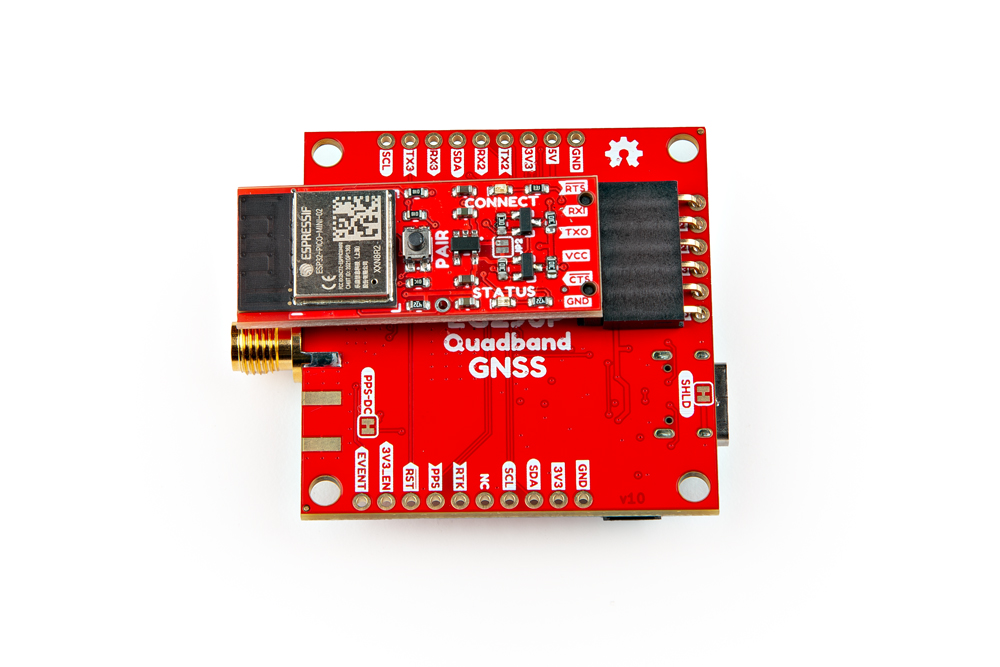
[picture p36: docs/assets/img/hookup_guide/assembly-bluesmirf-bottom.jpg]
BlueSMiRF transceiver - bottom
	
	<figcaption markdown>Female header pins soldered to the back of the board.</figcaption>
	</figure>

	</div>

	</div>

=== "UART Adapter"
	Connecting a UART adapter *([Serial Basic](https://www.sparkfun.com/sparkfun-serial-basic-breakout-ch340c-and-usb-c.html))* to a male header that was soldered to the Quad-band GNSS RTK breakout board. This will allow users to configure the LG290P, when the USB connection is unavailable.

	<figure markdown>
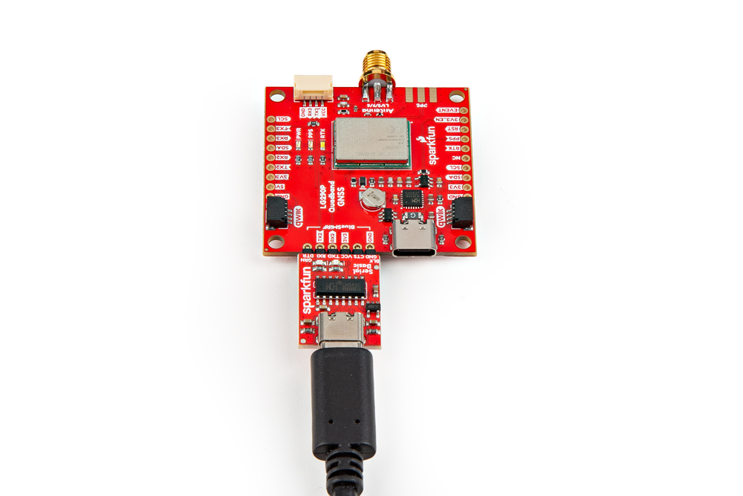
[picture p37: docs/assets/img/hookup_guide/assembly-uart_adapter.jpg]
Serial Basic
	
	<figcaption markdown>The adapter connected to the Quad-band GNSS RTK breakout board.</figcaption>
	</figure>

=== "OpenLog"
	!!! warning "Default Baud Rate"
		The baud rate for OpenLog needs to be configured in the `config.txt` file.

	Connecting an [OpenLog](https://www.sparkfun.com/sparkfun-openlog.html) to the Quad-band GNSS RTK breakout board. This will allow users to automatically log PNT data from the LG290P.

	<figure markdown>
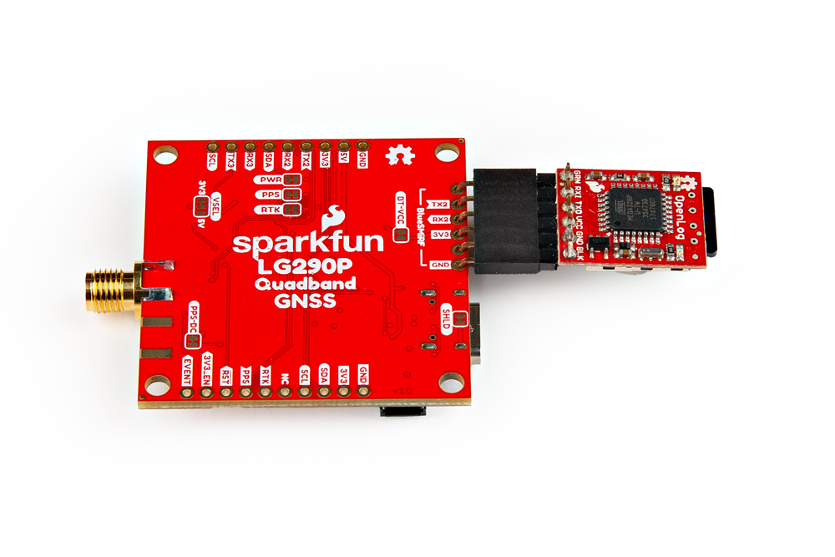
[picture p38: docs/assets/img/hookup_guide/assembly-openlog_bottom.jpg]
	
	<figcaption markdown>An [OpenLog](https://www.sparkfun.com/sparkfun-openlog.html) connected to the Quad-band GNSS RTK breakout board.</figcaption>
	</figure>

## PPS SMA Connector
SMD pads are provided for the [PPS](https://en.wikipedia.org/wiki/Pulse-per-second_signal "Pulse Per Second") output signal, where an SMA or RP-SMA connector can be soldered. This allows users to easily access the timing signal through a standardized connector, instead of the `PPS` [PTH](https://en.wikipedia.org/wiki/Through-hole_technology "Plated Through Holes") pin.

<figure markdown>
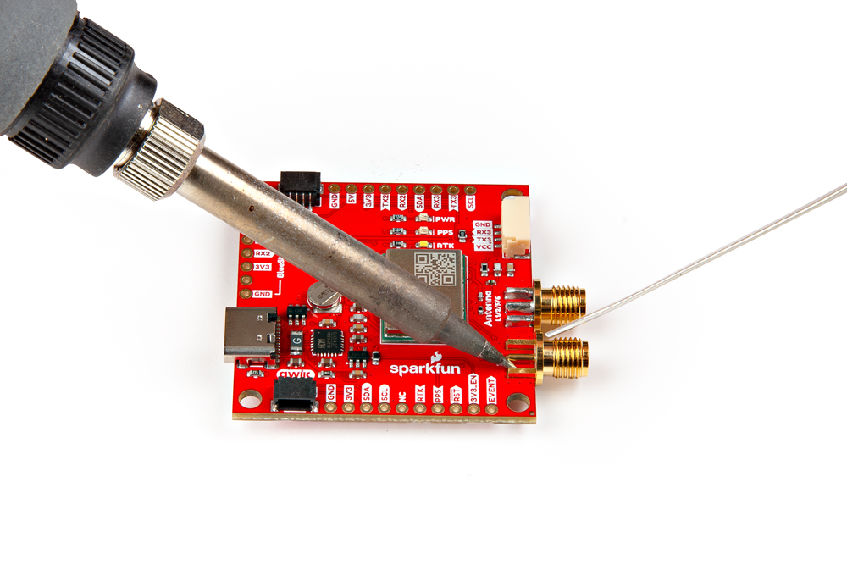
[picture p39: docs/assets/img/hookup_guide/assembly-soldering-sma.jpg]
Soldering an SMA connector

<figcaption markdown>Soldering an SMA connector to the SMD pads of the Quad-band GNSS RTK breakout board.</figcaption>
</figure>

???+ note "RP-SMA and SMA Connectors"
	<div class="grid cards" markdown>

	-   <a href="https://www.sparkfun.com/reverse-polarized-sma-connector.html">
		<figure markdown>
		Product Thumbnail
		</figure>

		---

		**Reverse Polarized SMA Connector**<br>
		WRL-00592</a>

	-   <a href="https://www.sparkfun.com/sma-connector.html">
		<figure markdown>
		Product Thumbnail
		</figure>

		---

		**SMA Connector**<br>
		WRL-00593</a>

	</div>

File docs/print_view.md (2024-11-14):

---
hide:
  - navigation
  - toc
icon: material/printer
---

--8<-- "./introduction.md:5"

# Hardware Overview
--8<-- "./hardware_overview.md:5"

# Hardware Assembly
--8<-- "./hardware_assembly.md:5"

# Software Overview
--8<-- "./software_overview.md:5"

# Resources
--8<-- "./resources.md:5"

# Troubleshooting Tips
--8<-- "./troubleshooting_tips.md:5"

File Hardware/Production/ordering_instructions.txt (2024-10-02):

Ordering Instructions:
Panel dimensions: 109.70 x 187.92 mm.
Controlled Impedance: JLC7628
Material: TG155
Solder Mask: Red
Silkscreen: White
Layers: 4
Finish: ENIG
Thickness: 1.6mm
Outer Copper Weight: 1oz
Inner Copper Weight: 0.5oz
Minimum track width: 0.15mm (6.00mil)
Minimum via drill: 0.30mm (11.81mil)
No Clean Process

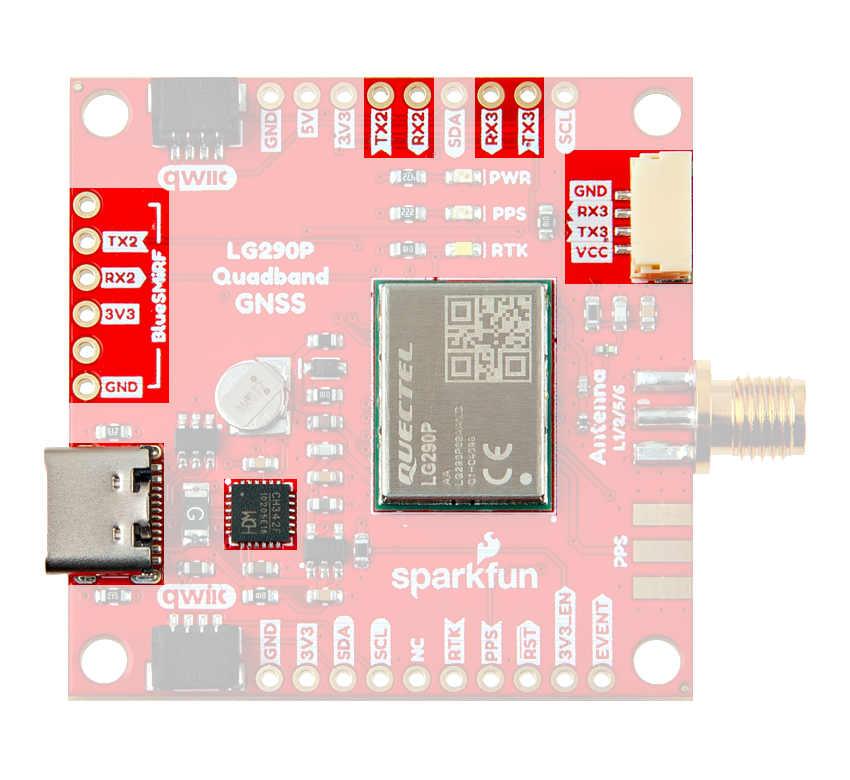
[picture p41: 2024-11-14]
docs/assets/img/hookup_guide/uart_ports1.png

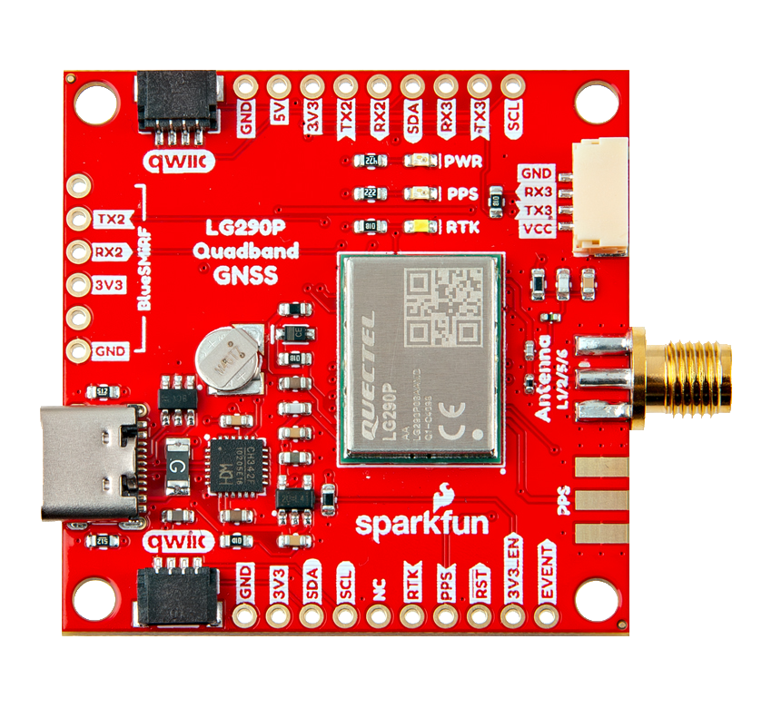
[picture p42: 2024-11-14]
docs/assets/img/hookup_guide/LG290P-top.png

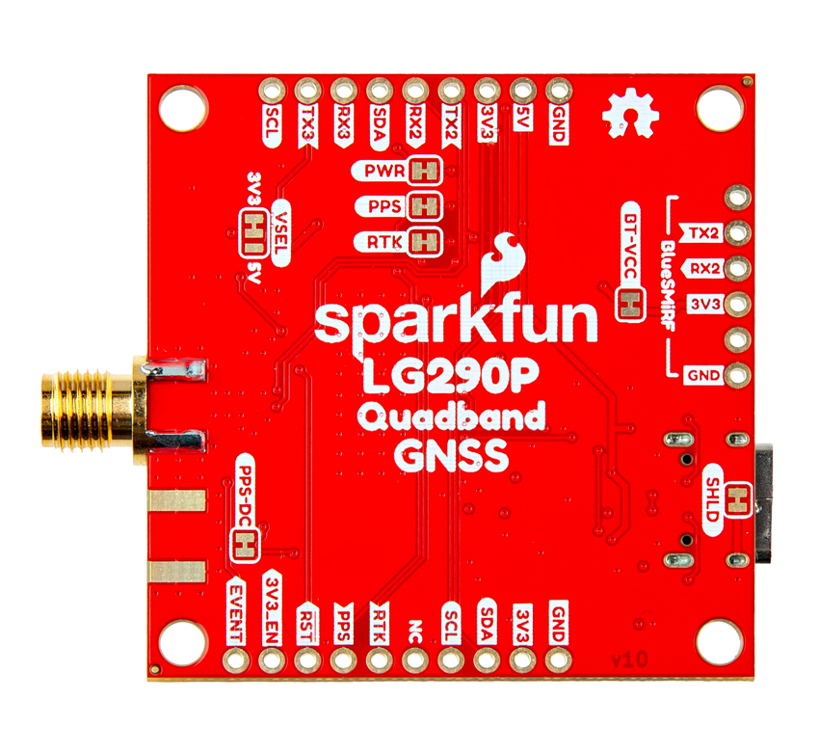
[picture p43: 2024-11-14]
docs/assets/img/hookup_guide/LG290P-bottom.png

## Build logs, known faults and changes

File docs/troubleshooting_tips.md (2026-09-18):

---
icon: sfe-logo
---

!!! warning "Need Help?"
	If you need technical assistance or more information on a product that is not working as you expected, we recommend heading over to the [SparkFun Technical Assistance](https://www.sparkfun.com/technical_assistance) page for some initial troubleshooting.

	<article style="text-align: center;" markdown>
	[SparkFun Technical Assistance Page](https://www.sparkfun.com/technical_assistance){ .md-button .md-button--primary }
	</article>

	If you can't find what you need there, the [SparkFun GNSS Forum](https://community.sparkfun.com/c/global-positioning-system-gps/96) is a great place to ask questions.

	!!! info "Account Registration Required"
		If this is your first visit to our forum, you'll need to create a [Forum Account](https://community.sparkfun.com/signup) to post questions.

### Antenna Issues
At a minimum, we recommend utilizing an active L1/L2/L5 antenna with the LG290P. Some customer have reported that the LG290P remains in an `RTK Float` status, when utilizing GNSS antennas that don't meet these specifications. However, users just need to mask the signals and satellites that are available to the GNSS receiver.

<!-- QR Code for Hookup Guide (Displayed when printed) -->
<article style="text-align: center;" markdown>
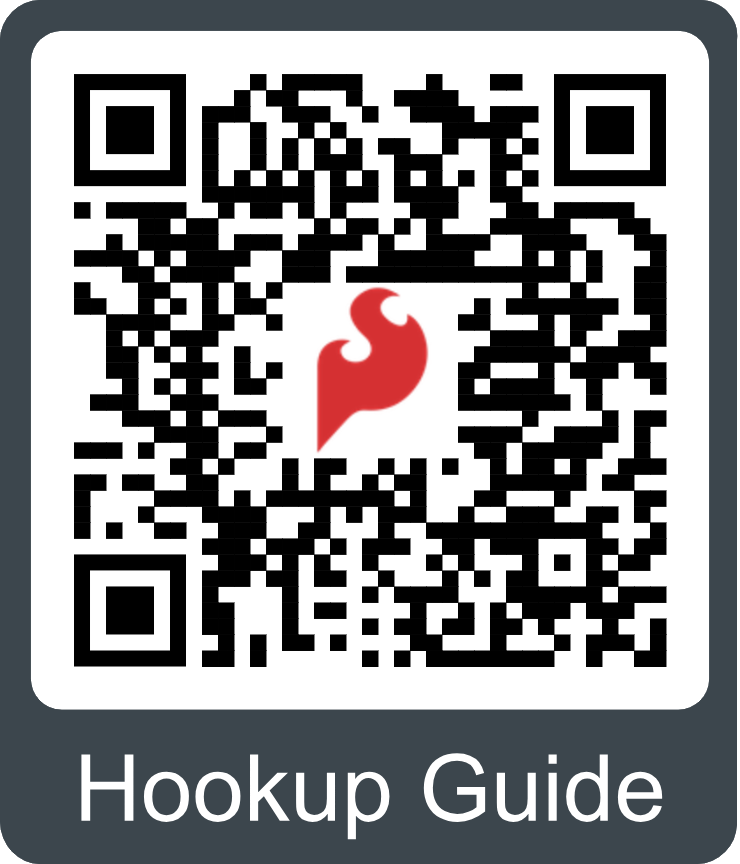
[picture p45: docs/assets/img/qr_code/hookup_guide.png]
QR code to the hookup guide

</article>

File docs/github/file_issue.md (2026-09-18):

# Did we make a mistake?

Spot something wrong? Please let us know. 

<!-- Technical Assistance Box -->
!!! warning "Need Help?"
	If you need technical assistance or more information on a product that is not working as you expected, we recommend heading on over to the [SparkFun Technical Assistance](https://www.sparkfun.com/technical_assistance) page for some initial troubleshooting. This **Submit Issues** page is not where users should seek assistance.

	<article style="text-align: center;" markdown>
	[SparkFun Technical Assistance Page](https://www.sparkfun.com/technical_assistance){ .md-button .md-button--primary }
	</article>

	If you can't find what you need there, the [SparkFun Forums](https://community.sparkfun.com) is a great place to search the product forums and ask questions.

	!!! info "Account Registration Required"
		For your first visit to our forum, you'll need to create a [Forum Account](https://community.sparkfun.com/signup) to post questions.

## Discrepancies in the Documentation

All of our documentation can be modified by you! Please help us make it better.

- The documentation files for these pages are contained in the [`docs` folder](https://github.com/sparkfun/SparkFun_LG290P_Quadband_GNSS_RTK_Breakout/tree/main/docs) of the [SparkFun LG290P Quadband GNSS RTK Breakout repository](https://github.com/sparkfun/SparkFun_LG290P_Quadband_GNSS_RTK_Breakout).

### 🔍 Spot something wrong?

If a section of the documentation is incorrect, please [open an issue](https://github.com/sparkfun/SparkFun_LG290P_Quadband_GNSS_RTK_Breakout/issues) and let us know.

### Do you have a suggested correction?

1. With a GitHub account, [fork this repository](https://github.com/sparkfun/SparkFun_LG290P_Quadband_GNSS_RTK_Breakout/fork).
2. Add your correction(s) or improvement(s) to the markdown file(s)
3. File a pull request with your changes, and enjoy making the ~~words~~ ~~worlds~~ world a better place.
	- Once received, the documentation specialist will automatically be notified.
	- We will review your suggested improvement(s) to make sure they are correct and fit within our documentation standards.

## Problems in the Hardware Design

All of our designs are open-source! Please help us make it better.

- Our board design files are contained in the [`Hardware` folder](https://github.com/sparkfun/SparkFun_LG290P_Quadband_GNSS_RTK_Breakout/tree/main/Hardware) of the [SparkFun LG290P Quadband GNSS RTK Breakout repository](https://github.com/sparkfun/SparkFun_LG290P_Quadband_GNSS_RTK_Breakout).

### Does something not make sense? 🤔

If part of the design is confusing, please [open an issue](https://github.com/sparkfun/SparkFun_LG290P_Quadband_GNSS_RTK_Breakout/issues) and let us know.

### Did we forget to include an important function of the board? 🤦

If part of the board's functionality is missing, please [open an issue](https://github.com/sparkfun/SparkFun_LG290P_Quadband_GNSS_RTK_Breakout/issues) and file a feature request.

!!! tip "Design Considerations"
	Please keep in mind that we may intentionally exclude certain functions of the board to meet our product design requirements.

	- *For example, our Qwiic Micro boards are intended to fit on a small board layout and only use I^2^C communication; therefore, we may not have the SPI and interrupt pins available for users.*

### Do you wish to contribute directly to improving the board design?

1. With a GitHub account, [fork this repository](https://github.com/sparkfun/SparkFun_LG290P_Quadband_GNSS_RTK_Breakout/fork).
2. Add your design augmentation(s)
3. File a pull request with your changes, and enjoy making the ~~words~~ ~~worlds~~ world a better place.
	1. Once received, the engineer in charge of the original design will automatically be notified.
	2. We will review your suggested improvement(s) to verify that they are within our board design standards and meet our product design requirements.
	3. If approved, we will flag these changes for our next board revision. Congrats! 🍻

		!!! info
			Even if your suggestion is accepted, these changes may not be immediately available for purchase. We may have to cycle through our current product inventory first.

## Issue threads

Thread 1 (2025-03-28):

Suggestions for updates to Sparkfun LG290P Software Overview re. PyGPSClient and pynmeagps

semuadmin, 2025-03-28:
Some suggestions for updates to the LG290P software overview in relation to the PyGPSClient and pynmeagps libraries:

> As an alternative to QGNSS, for users with computers that run on MacOS or Linux, we recommend [PyGPSClient](https://github.com/semuconsulting/PyGPSClient) as an option for viewing the data from the NMEA messages and connecting to an NTRIP caster. However, users should be aware that this GUI interface is currently limited to only receiving UART messages and cannot send messages to configure the LG290P module.

Note that the Python library [pynmeagps](https://github.com/semuconsulting/pynmeagps) (v1.0.48 or later) DOES support the full range of proprietary NMEA PQTM* configuration message types for the LG290P. See [quecteldemo.py](https://github.com/semuconsulting/pynmeagps/blob/master/examples/quecteldemo.py) for illustrative usage.

The latest release of PyGPSClient (v1.0.55) DOES support LG290P configuration via a new NMEA configuration panel.

> Additionally, users will also need administrative privileges (or root access sudo) for the installation.

This is not _necessarily_ true - local user installation does not normally require admin privileges (_though there may be other local constraints, depending on the platform_) e.g.

```python
python3 -m pip install --upgrade --user pygpsclient
```

NOTE THAT if your Python environment is `externally managed` (_as is the default with many Linux distributions_) you will be prompted to install into a virtual environment rather than the system wide environment - see PyGPSClient README for further details:

```python
python3 -m venv pygpsclient
source pygpsclient/bin/activate
python3 -m pip install --upgrade pygpsclient
```

FYI there is a makeshift [installation shell shell](https://github.com/semuconsulting/PyGPSClient/blob/master/examples/pygpsclient_debian_install.sh) in the /examples folder for Raspberry Pi and similar Debian Linux environments - it should work out of the box for most vanilla 64-bit Debian environments but can readily be refined.

> Before users can connect to the Quad-band GNSS RTK breakout board, they will need to specify the settings of the UART port in PyGPSClient. Once configured, users can select the button and PyGPSClient will automatically attempt to connect to the GNSS module.

Note there is a quirk with the forthcoming RPi PHAT version of the LG290P breakout - its 3 UART ports are NOT automatically detected by the standard Python function used by PyGPSClient to list available ports (`serial.tools.list_ports.comports()`) - it may be necessary to add one or more user-defined ports (e.g. `/dev/ttyAMA0`) - see PyGPSClient README for details.

Hope this helps.

Closed 2025-05-21.

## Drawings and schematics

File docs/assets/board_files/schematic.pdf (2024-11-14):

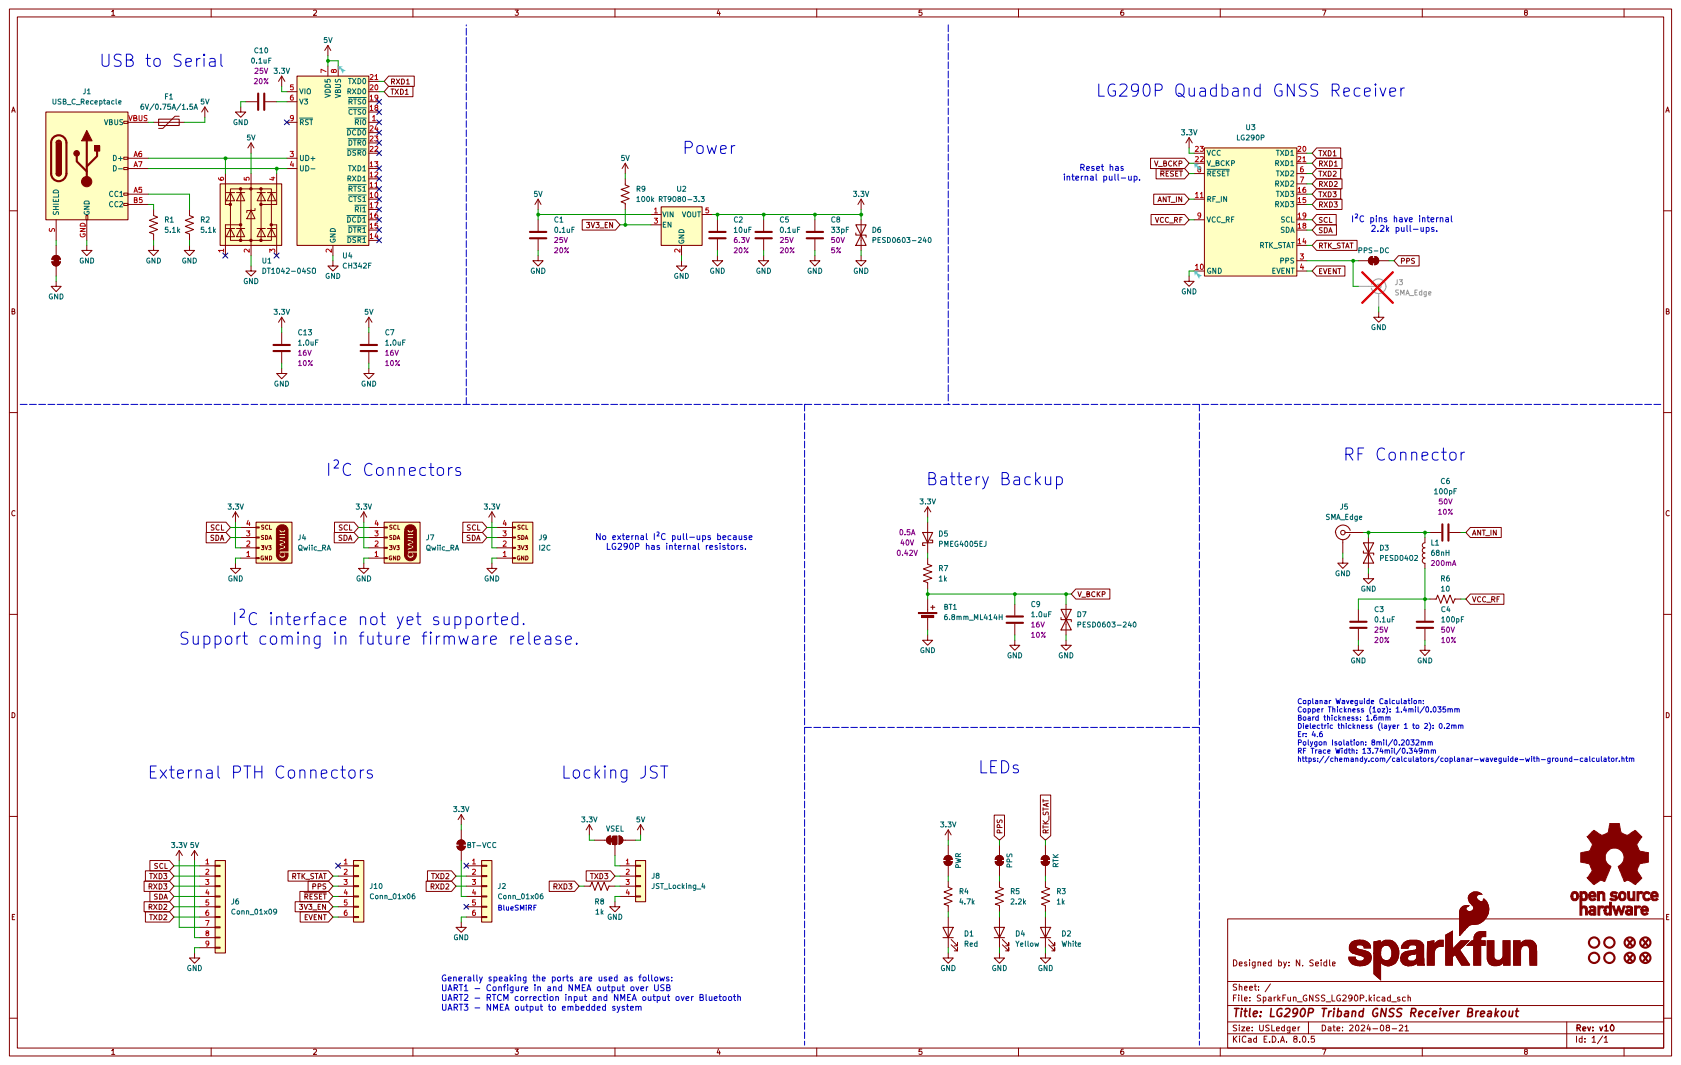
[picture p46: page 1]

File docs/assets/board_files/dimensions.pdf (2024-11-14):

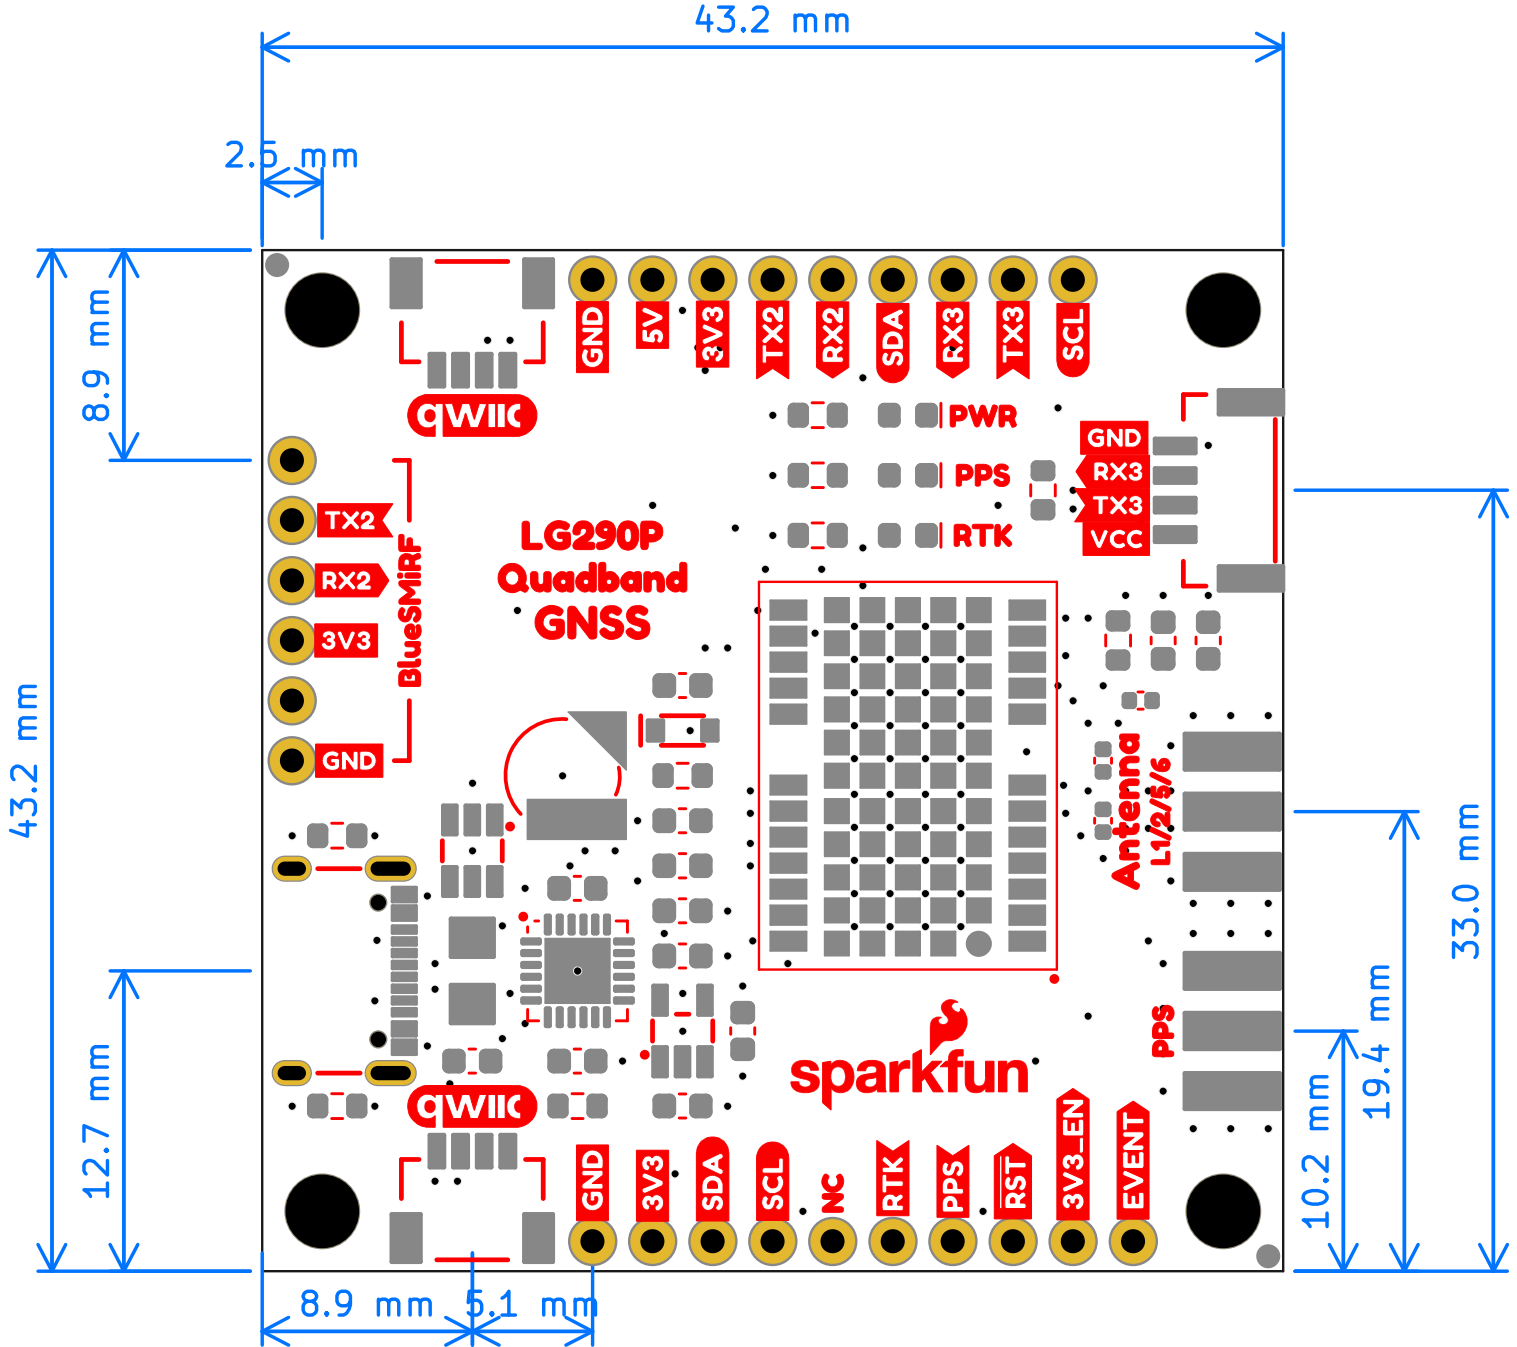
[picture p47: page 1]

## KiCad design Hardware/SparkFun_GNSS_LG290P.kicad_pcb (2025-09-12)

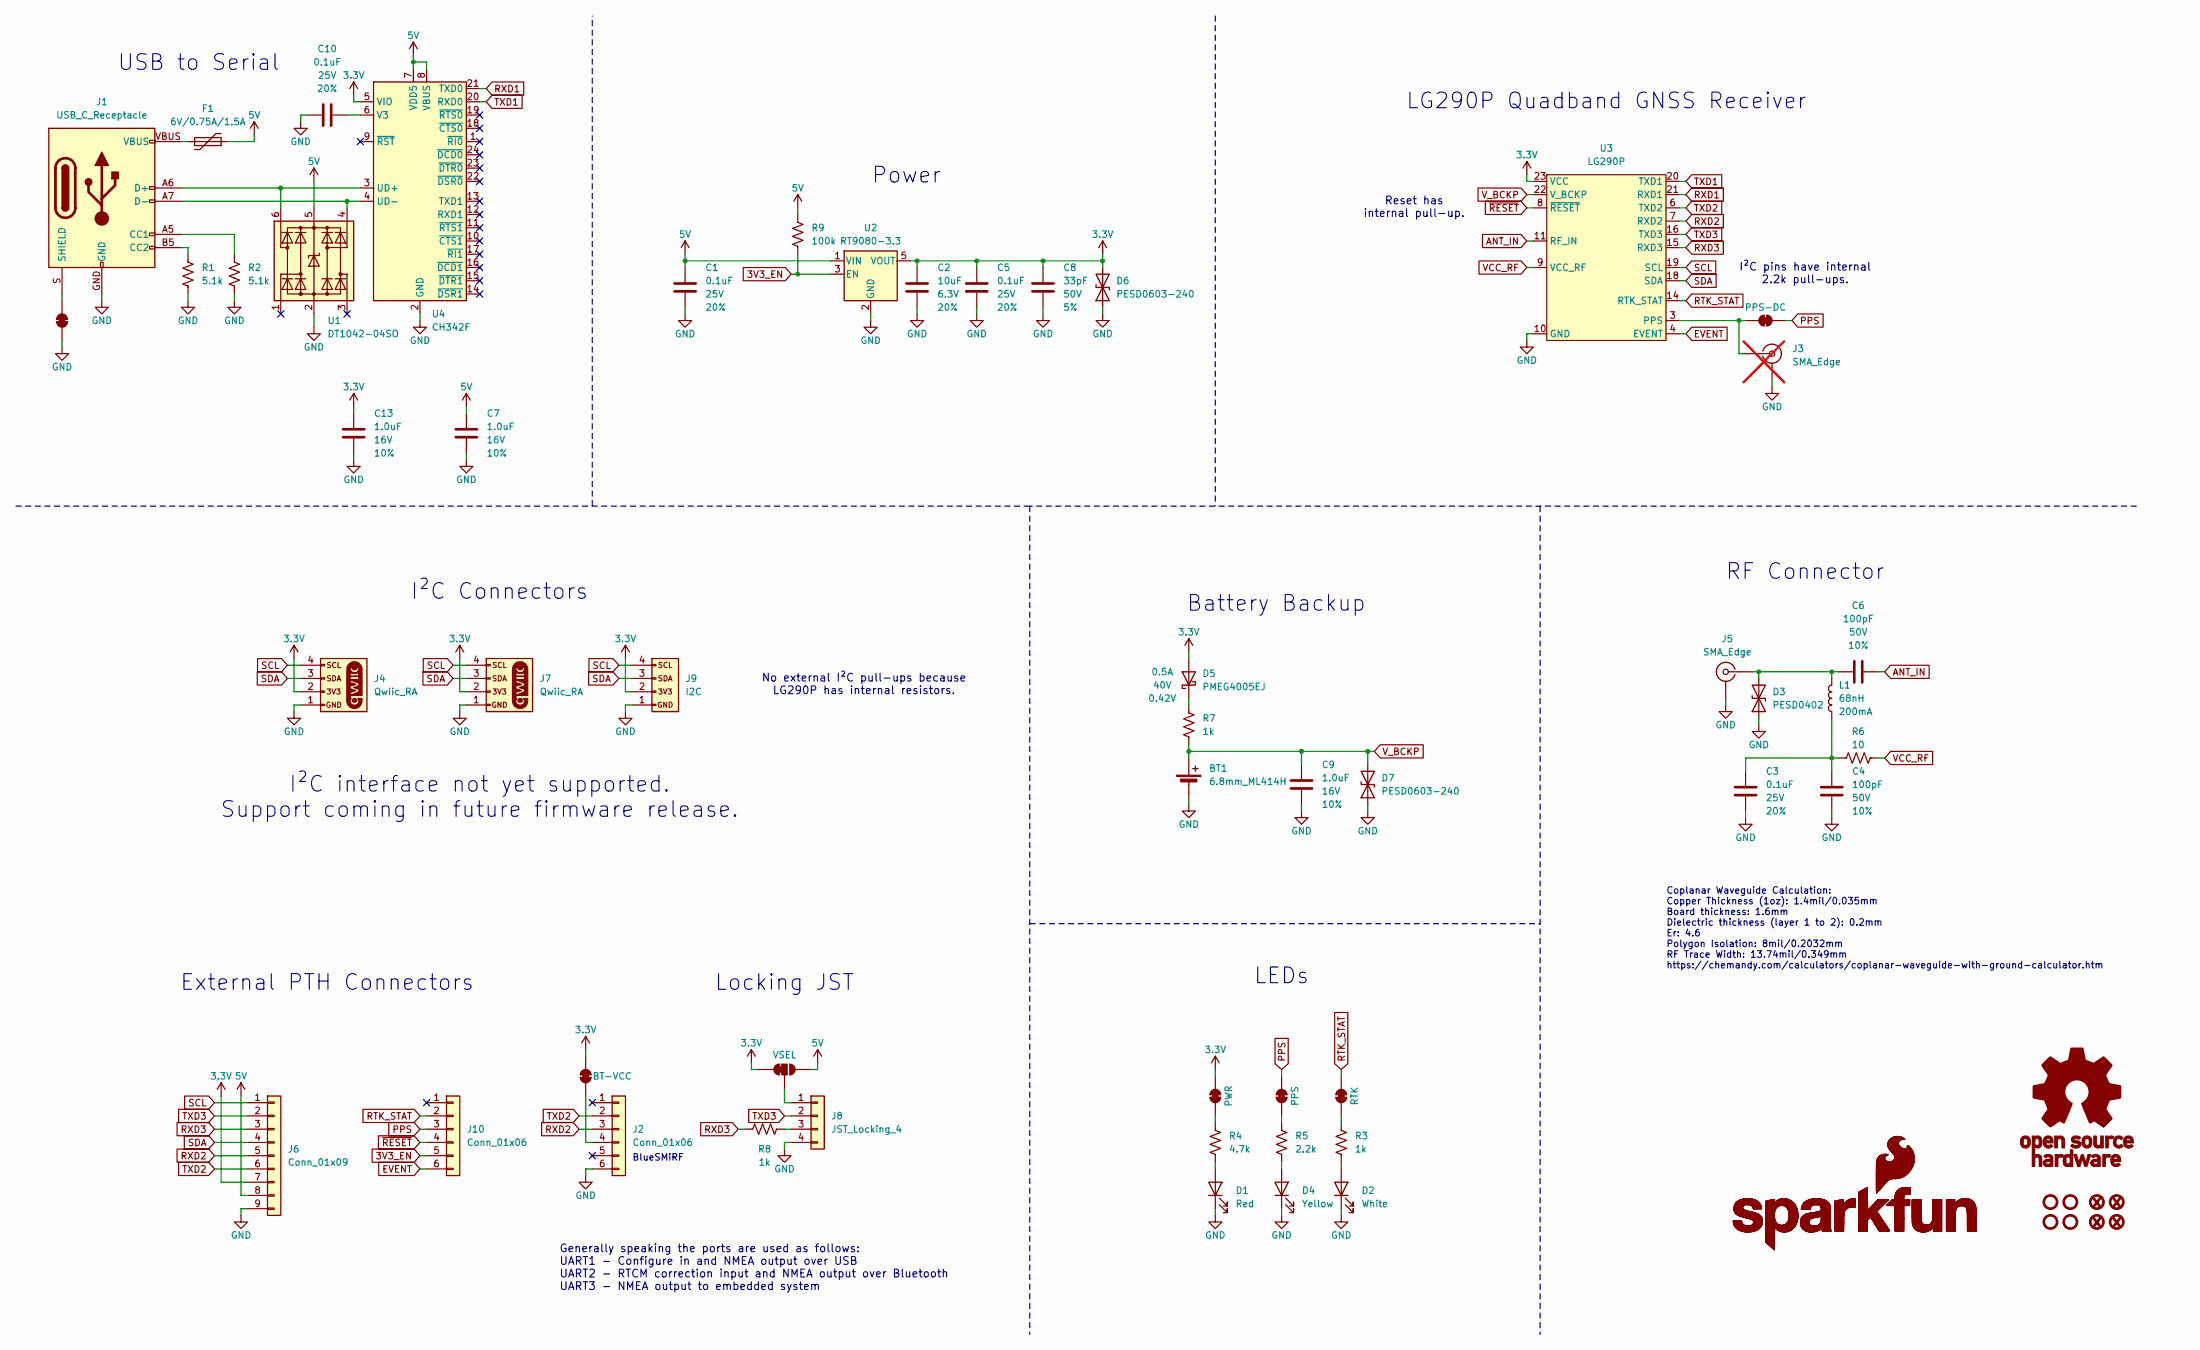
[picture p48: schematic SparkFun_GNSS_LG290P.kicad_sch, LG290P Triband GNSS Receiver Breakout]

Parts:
BT1: 6.8mm_ML414H; ML414H_IV01E
C1, C3, C5, C10: 0.1uF; C_0603_1608Metric; Voltage 25V; Tolerance 20%
C2: 10uF; C_0603_1608Metric; Voltage 6.3V; Tolerance 20%
C4: 100pF; C_0603_1608Metric; Voltage 50V; Tolerance 10%
C6: 100pF; C_0402_1005Metric; Voltage 50V; Tolerance 10%
C7, C9, C13: 1.0uF; C_0603_1608Metric; Voltage 16V; Tolerance 10%
C8: 33pF; C_0603_1608Metric; Voltage 50V; Tolerance 5%
D1: Red; LED_0603_1608Metric_Red
D2: White; LED_0603_1608Metric_White
D3: PESD0402; C_0402_1005Metric
D4: Yellow; LED_0603_1608Metric_Yellow
D5: PMEG4005EJ; SOD-323
D6, D7: PESD0603-240; C_0603_1608Metric
F1: 6V/0.75A/1.5A; 1206
FID1, FID2, FID3, FID4: Fiducial_0.5mm; Fiducial_0.5mm_Mask1mm
G1: OSHW_Logo; Creative_Commons_License
G3: SparkFun_Logo
G5: SparkFun_Logo; SparkFun_Logo_8mm
J1: USB_C_Receptacle; USB-C_16
J2, J10: Conn_01x06; 1x06
J3: SMA_Edge; not fitted
J4, J7: Qwiic_RA; JST_SMD_1.0mm-4_RA
J5: SMA_Edge
J6: Conn_01x09; 1x09
J8: JST_Locking_4; JST_SMD_1.25mm-4_Locking
J9: I2C; 1x04
JP1: BT-VCC; Jumper_2_NC_Trace
JP2: PWR; Jumper_2_NC_Trace
JP3: PPS; Jumper_2_NC_Trace
JP4: VSEL; Jumper_3_NC-1_Trace
JP5: RTK; Jumper_2_NC_Trace
JP6: PPS-DC; Jumper_2_NC_Trace
JP7: Jumper_2_NC_Trace
L1: 68nH; C_0402_1005Metric
R1, R2: 5.1k; R_0603_1608Metric
R3, R7, R8: 1k; R_0603_1608Metric
R4: 4.7k; R_0603_1608Metric
R5: 2.2k; R_0603_1608Metric
R6: 10; R_0603_1608Metric
R9: 100k; R_0603_1608Metric
ST1, ST2, ST3, ST4: Standoff
U1: DT1042-04SO; SOT23-6
U2: RT9080-3.3; SOT23-5
U3: LG290P; Quectel_LG290P
U4: CH342F; QFN-24-1EP_4x4mm_P0.5mm_EP2.7x2.7mm

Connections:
3.3V: C2.1, C5.1, C8.1, C13.1, D5.A, D6.2 (A2), J4.2, J6.7, J7.2, J9.2, JP1.2 (B), JP2.2 (B), JP4.1 (A), U2.5 (VOUT), U3.23 (VCC), U4.5 (VIO)
3V3_EN: J10.5, R9.2, U2.3 (EN)
5V: C1.1, C7.1, F1.2, J6.8, JP4.3 (B), R9.1, U1.5 (VCC), U2.1 (VIN), U4.7 (VDD5), U4.8 (VBUS)
ANT_IN: C6.2, U3.11 (RF_IN)
EVENT: J10.6, U3.4 (EVENT)
GND: BT1.-, C1.2, C2.2, C3.2, C4.2, C5.2, C7.2, C8.2, C9.2, C10.1, C13.2, D1.1 (K), D2.1 (K), D3.1 (A1), D4.1 (K), D6.1 (A1), D7.1 (A1), J1.GND, J2.6, J3.2 (Ext), J4.1, J5.2 (Ext), J6.9, J7.1, J8.4, J9.1, JP7.1 (A), R1.2, R2.2, U1.2 (GND), U2.2 (GND), U3.10 (GND), U3.12 (GND), U3.13 (GND), U3.24 (GND), U3.25 (GND), U4.2 (GND), U4.25 (GND)
unnamed: C3.1, C4.1, L1.1, R6.2
unnamed: D1.2 (A), R4.2
unnamed: D2.2 (A), R3.2
unnamed: C6.1, D3.2 (A2), J5.1 (In), L1.2
unnamed: D4.2 (A), R5.2
unnamed: D5.C, R7.1
unnamed: F1.1, J1.VBUS
unnamed: J1.A5 (CC1), R2.1
unnamed: J1.B5 (CC2), R1.1
unnamed: J1.S (SHIELD), JP7.2 (B)
unnamed: J2.4, JP1.1 (A)
unnamed: J3.1 (In), JP6.1 (A), U3.3 (PPS)
unnamed: J8.1, JP4.2 (C)
unnamed: J8.3, R8.2
unnamed: JP2.1 (A), R4.1
unnamed: JP3.1 (A), R5.1
unnamed: JP5.1 (A), R3.1
unnamed: J1.A7 (D-), J1.B7 (D-), U1.4 (I/O3), U4.4 (UD-)
unnamed: J1.A6 (D+), J1.B6 (D+), U1.6 (I/O4), U4.3 (UD+)
unnamed: C10.2, U4.6 (V3)
PPS: J10.3, JP3.2 (B), JP6.2 (B)
RTK_STAT: J10.2, JP5.2 (B), U3.14 (RTK_STAT)
RXD1: U3.21 (RXD1), U4.21 (TXD0)
RXD2: J2.3, J6.5, U3.7 (RXD2)
RXD3: J6.3, R8.1, U3.15 (RXD3)
SCL: J4.4, J6.1, J7.4, J9.4, U3.19 (SCL)
SDA: J4.3, J6.4, J7.3, J9.3, U3.18 (SDA)
TXD1: U3.20 (TXD1), U4.20 (RXD0)
TXD2: J2.2, J6.6, U3.6 (TXD2)
TXD3: J6.2, J8.2, U3.16 (TXD3)
VCC_RF: R6.1, U3.9 (VCC_RF)
V_BCKP: BT1.+, C9.1, D7.2 (A2), R7.2, U3.22 (V_BCKP)
~RESET: J10.4, U3.8 (~RESET)

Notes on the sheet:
I²C Connectors
Generally speaking the ports are used as follows: UART1 - Configure in and NMEA output over USB UART2 - RTCM correction input and NMEA output over Bluetooth UART3 - NMEA output to embedded system
Reset has internal pull-up.
I²C interface not yet supported. Support coming in future firmware release.
Coplanar Waveguide Calculation: Copper Thickness (1oz): 1.4mil/0.035mm Board thickness: 1.6mm Dielectric thickness (layer 1 to 2): 0.2mm Er: 4.6 Polygon Isolation: 8mil/0.2032mm RF Trace Width: 13.74mil/0.349mm https://chemandy.com/calculators/coplanar-waveguide-with-ground-calculator.htm
I²C pins have internal 2.2k pull-ups.
Locking JST
BlueSMiRF
Power
RF Connector
LEDs
LG290P Quadband GNSS Receiver
USB to Serial
Battery Backup
External PTH Connectors
No external I²C pull-ups because LG290P has internal resistors.

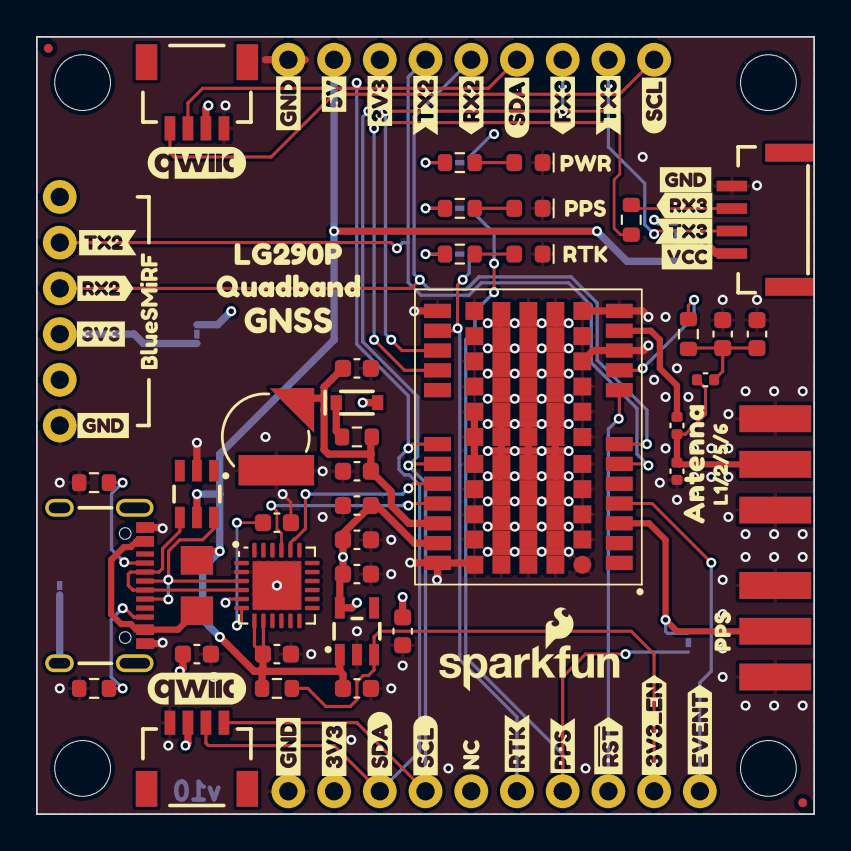
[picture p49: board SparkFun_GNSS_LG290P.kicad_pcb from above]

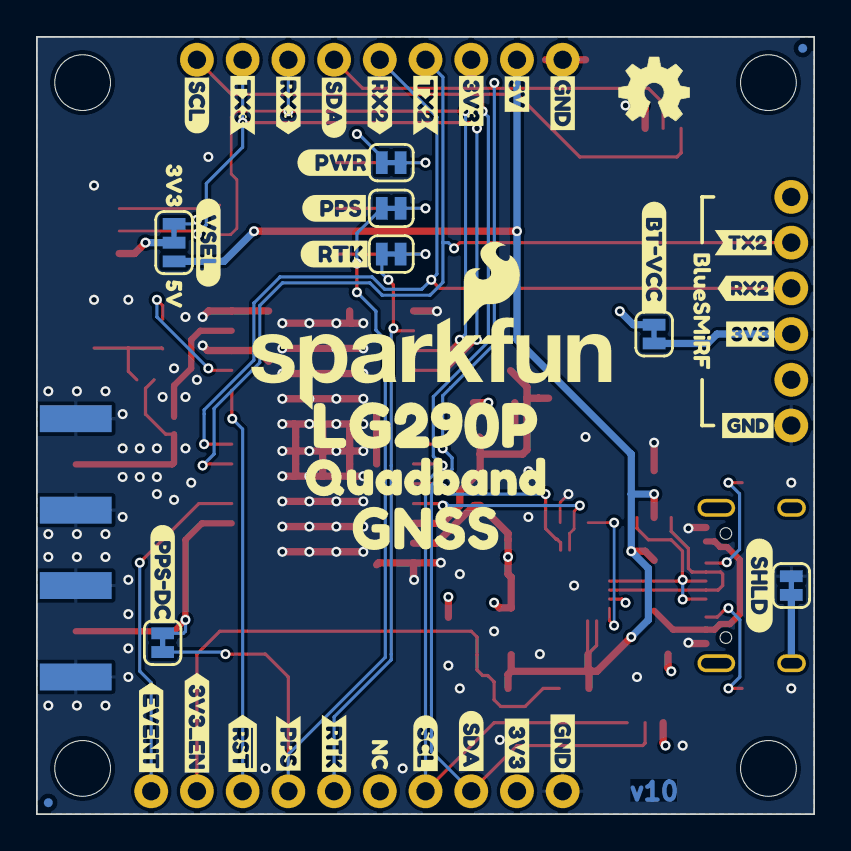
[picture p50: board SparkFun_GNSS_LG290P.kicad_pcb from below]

Board: 4 copper layers, 43.2 x 43.2 mm, 134 parts (46 on the bottom side), 39 nets.

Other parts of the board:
Ref**: Val**; OSHW_Logo_4mm
kibuzzard-64C2E6A3: G***; kibuzzard-64C2E6A3
kibuzzard-64C2E6BD: G***; kibuzzard-64C2E6BD
kibuzzard-64C2E6D6: G***; kibuzzard-64C2E6D6
kibuzzard-64C2E728: G***; kibuzzard-64C2E728
kibuzzard-64C2EB16: G***; kibuzzard-64C2EB16
kibuzzard-64C3DF93: G***; kibuzzard-64C3DF93
kibuzzard-64CB1646: G***; kibuzzard-64CB1646
kibuzzard-64CB1658: G***; kibuzzard-64CB1658
kibuzzard-64D296AE: G***; kibuzzard-64D296AE
kibuzzard-66C94FCB: G***; kibuzzard-66C94FCB
kibuzzard-66C9493A: G***; kibuzzard-66C9493A
kibuzzard-66C94934: G***; kibuzzard-66C94934
kibuzzard-66C94943: G***; kibuzzard-66C94943
kibuzzard-66CAA7B2: G***; kibuzzard-66CAA7B2
kibuzzard-66CAA7D2: G***; kibuzzard-66CAA7D2
kibuzzard-66CAA8C4: G***; kibuzzard-66CAA8C4
kibuzzard-66CAA8D1: G***; kibuzzard-66CAA8D1
kibuzzard-66CAA8D8: G***; kibuzzard-66CAA8D8
kibuzzard-66CAA8DF: G***; kibuzzard-66CAA8DF
kibuzzard-66CAA8E9: G***; kibuzzard-66CAA8E9
kibuzzard-66CAA8ED: G***; kibuzzard-66CAA8ED
kibuzzard-66CAA9A5, kibuzzard-66CAA9A5#2: G***; kibuzzard-66CAA9A5
kibuzzard-66CAA9AE, kibuzzard-66CAA9AE#2: G***; kibuzzard-66CAA9AE
kibuzzard-66CAA9CC: G***; kibuzzard-66CAA9CC
kibuzzard-66CAA9E1: G***; kibuzzard-66CAA9E1
kibuzzard-66CAA41A: G***; kibuzzard-66CAA41A
kibuzzard-66CAA70F: G***; kibuzzard-66CAA70F
kibuzzard-66CAA426, kibuzzard-66CAA426#2: G***; kibuzzard-66CAA426
kibuzzard-66CAA432, kibuzzard-66CAA432#2: G***; kibuzzard-66CAA432
kibuzzard-66CAA594: G***; kibuzzard-66CAA594
kibuzzard-66CAA834: G***; kibuzzard-66CAA834
kibuzzard-66CAAA3A: G***; kibuzzard-66CAAA3A
kibuzzard-66CAAA42: G***; kibuzzard-66CAAA42
kibuzzard-66CAAA64: G***; kibuzzard-66CAAA64
kibuzzard-66CB3A22: G***; kibuzzard-66CB3A22
kibuzzard-66CB3A29: G***; kibuzzard-66CB3A29
kibuzzard-66CB3AB2: G***; kibuzzard-66CB3AB2
kibuzzard-66CB3AEE: G***; kibuzzard-66CB3AEE
kibuzzard-66CB3B05: G***; kibuzzard-66CB3B05
kibuzzard-66CB3B6E: G***; kibuzzard-66CB3B6E
kibuzzard-66CB3B7A: G***; kibuzzard-66CB3B7A
kibuzzard-66CB3BAB: G***; kibuzzard-66CB3BAB
kibuzzard-66CB3BB4: G***; kibuzzard-66CB3BB4
kibuzzard-66CB3BBD: G***; kibuzzard-66CB3BBD
kibuzzard-66CB3BC8: G***; kibuzzard-66CB3BC8
kibuzzard-66CB3BD0: G***; kibuzzard-66CB3BD0
kibuzzard-66CB3BFF: G***; kibuzzard-66CB3BFF
kibuzzard-66CB3C6B: G***; kibuzzard-66CB3C6B
kibuzzard-66CB3C14: G***; kibuzzard-66CB3C14
kibuzzard-66CB3C73: G***; kibuzzard-66CB3C73
kibuzzard-66CB7E2C: G***; kibuzzard-66CB7E2C
kibuzzard-66CB37A9, kibuzzard-66CB37A9#2: G***; kibuzzard-66CB37A9
kibuzzard-66CB37CC: G***; kibuzzard-66CB37CC
kibuzzard-66CB37D7: G***; kibuzzard-66CB37D7
kibuzzard-66CB38B8: G***; kibuzzard-66CB38B8
kibuzzard-66CB38C4: G***; kibuzzard-66CB38C4
kibuzzard-66CB39E1, kibuzzard-66CB39E1#2: G***; kibuzzard-66CB39E1
kibuzzard-66CB82FB: G***; kibuzzard-66CB82FB
kibuzzard-66CB829C: G***; kibuzzard-66CB829C
kibuzzard-66CB830B: G***; kibuzzard-66CB830B
kibuzzard-66CB3887: G***; kibuzzard-66CB3887
kibuzzard-66CB3899: G***; kibuzzard-66CB3899
kibuzzard-66CB8004: G***; kibuzzard-66CB8004
kibuzzard-66CBD5AE: G***; kibuzzard-66CBD5AE
kibuzzard-6501FDDA, kibuzzard-6501FDDA#2: G***; kibuzzard-6501FDDA
kibuzzard-650880E6: G***; kibuzzard-650880E6

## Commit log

2024-08-28 Connect CH342 V3 to decoupling cap
    [SparkFun_GNSS_LG290P.kicad_pcb, SparkFun_GNSS_LG290P.kicad_sch]
2024-08-28 Reduce ground clearance to clear DRC error
    [SparkFun_GNSS_LG290P.kicad_pcb]
2024-09-23 Add TVS to 3V3 and VBATT. Add protocol spec.
    [SparkFun_GNSS_LG290P.kicad_pcb, SparkFun_GNSS_LG290P.kicad_sch]
2024-10-02 Make post design review changes. Add panel files.
    [SparkFun_GNSS_LG290P.kicad_pcb, SparkFun_GNSS_LG290P.kicad_sch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]
2024-11-14 Moved the 3D model
    Moved the 3D model of the module into the /docs/assets/component_documentation directory
    [Quectel_LG290P_3D_Dimensions_V1.0.stp]
2024-11-14 Update
    Change lists to `-`
    Update README for KiCad files
    Fix typos
2025-07-09 Add firmware update
    Added a new section to the documentation detailing the firmware update process for the LG290P module, including references to the official manual and firmware sources. Included a warning about the synchronization step and instructions for using the QGNSS software's reboot button, along with a new image illustrating the reboot button.
2025-07-09 Update purchase link
    Adjusted the layout of the purchase button and QR code
2025-09-12 Update footprints
    Fixes file path, position, and orientation for the 3D models
    [SparkFun_GNSS_LG290P.kicad_pcb]
2025-09-25 Add README.md
    Adds README file for the current directory

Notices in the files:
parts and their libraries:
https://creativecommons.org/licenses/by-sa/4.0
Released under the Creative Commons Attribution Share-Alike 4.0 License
